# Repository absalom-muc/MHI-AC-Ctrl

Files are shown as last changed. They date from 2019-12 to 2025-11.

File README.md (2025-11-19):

# MHI-AC-Ctrl
Reads and writes data (e.g. power, mode, fan status etc.) from/to a Mitsubishi Heavy Industries (MHI) air conditioner (AC) via SPI controlled by MQTT. The AC is the SPI master and the ESP8266 is the SPI slave.

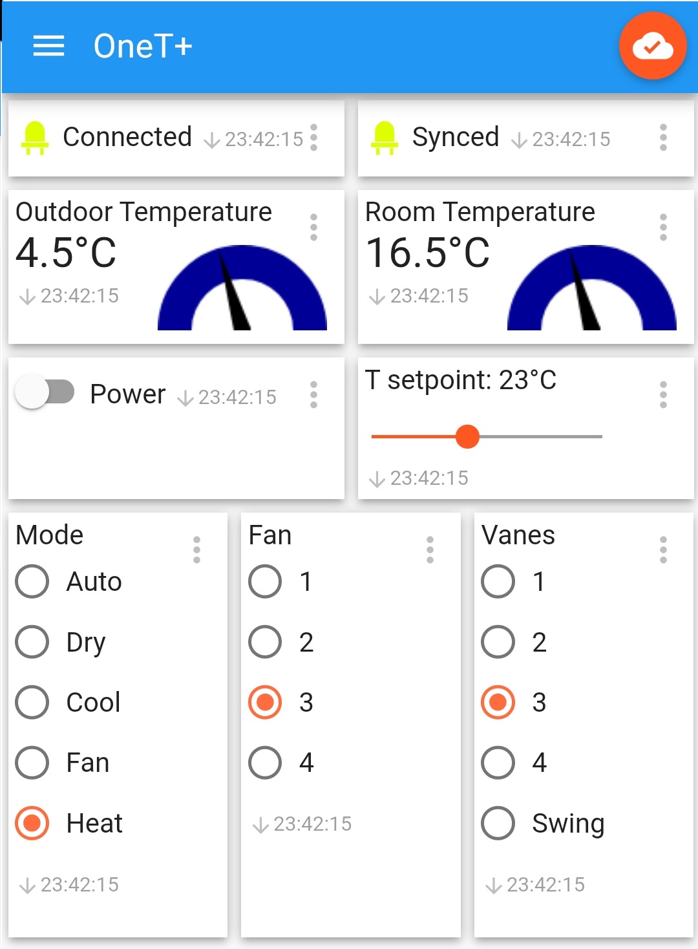
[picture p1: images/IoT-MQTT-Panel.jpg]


# Attention:
:warning: You have to open the indoor unit to have access to the SPI. Opening of the indoor unit should be done by 
a qualified professional because faulty handling may cause leakage of water, electric shock or fire! :warning: 

# Prerequisites:
For use of the program you have to connect your ESP8266 (I use a LOLIN(WEMOS) D1 R2 & mini with 80 MHz) via a
cable connector to your air conditioner. This has to be a split device (separated indoor and outdoor unit).
I assume that all AC units of the type "SRK xx ZS-S" / "SRC xx ZS-S" are supported. I use the indoor unit SRK 35 ZS-S and the outdoor unit SRC 35 ZS-S. Users reported that additionally the following models are supported:

- [SRF xx ZJX-S1](https://github.com/absalom-muc/MHI-AC-Ctrl/issues/17#issue-632187165)
- [SRF xx ZMX-S](https://github.com/absalom-muc/MHI-AC-Ctrl/issues/17#issuecomment-704789297)
- [SRF xx ZMXA-S](https://github.com/absalom-muc/MHI-AC-Ctrl/pull/91)
- SRF xx ZF-W
- [SRF xx ZS-W](https://github.com/absalom-muc/MHI-AC-Ctrl/pull/216#issue-3234769567) works with frame size 20
- [SRK xx ZJ-S](https://github.com/absalom-muc/MHI-AC-Ctrl/issues/10)
- [SRK xx ZM-S](https://github.com/absalom-muc/MHI-AC-Ctrl/issues/9)
- [SRK xx ZJX-S](https://github.com/absalom-muc/MHI-AC-Ctrl/issues/17#issuecomment-646469621)
- [SRK xx ZJX-S1](https://github.com/absalom-muc/MHI-AC-Ctrl/issues/17#issuecomment-646968940)
- [SRK xx ZR-WF](https://github.com/absalom-muc/MHI-AC-Ctrl/issues/214)
- [SRK xx ZRA-W](https://github.com/absalom-muc/MHI-AC-Ctrl/issues/17#issuecomment-730628655) / DXK xx ZRA-W
- [SRK xx ZSA-W](https://github.com/absalom-muc/MHI-AC-Ctrl/issues/17#issuecomment-891649495) / DXK xx ZSA-W
- [SRK63ZSPR-S](https://github.com/absalom-muc/MHI-AC-Ctrl/issues/149)
- SRK xx ZSXA-W/A
- [SRK xx ZSX-S](https://github.com/absalom-muc/MHI-AC-Ctrl/issues/6#issuecomment-582242372)
- [SRK xx ZSX-W](https://github.com/absalom-muc/MHI-AC-Ctrl/issues/17#issuecomment-643748095)
- [SRK xx ZS-W](https://github.com/absalom-muc/MHI-AC-Ctrl/issues/121)
- [SRK xx ZS-WF](https://github.com/absalom-muc/MHI-AC-Ctrl/issues/121#issuecomment-1938350129)
- [SRC 35Z SA-W]
- [DXK xx ZMA-S](https://github.com/absalom-muc/MHI-AC-Ctrl/issues/201)
- [SRK 2824 T (Japanese domestic model)](https://github.com/absalom-muc/MHI-AC-Ctrl/issues/211)

Unsupported models:
- [SRK71ZEA-S1](https://github.com/absalom-muc/MHI-AC-Ctrl/issues/143)
- [SRK35ZC-S](https://github.com/absalom-muc/MHI-AC-Ctrl/issues/154)
- [SRK xx ZSPR-S](https://github.com/absalom-muc/MHI-AC-Ctrl/issues/200) (except SRK63ZSPR-S)

If you find out that also other models are supported that are not listed here, please give feedback so that I can expand the list. In general, please recheck if your AC has a CNS connector before you spend time and money to build the hardware.

# Installing:

## Hardware:
The ESP8266 is powered from the AC via DC-DC (12V -> 5V) converter. 
The ESP8266 SPI signals SCL (SPI clock), MOSI (Master Out Slave In) and MISO (Master In Slave Out) are connected via a voltage level shifter 5V <-> 3.3V with the AC. Direct connection of the signals without a level shifter could damage your ESP8266!
More details are described in [Hardware.md](Hardware.md).

## Software:
The program uses the following libraries:
 - MQTT client library [PubSubClient3](https://github.com/hmueller01/pubsubclient3)
   - :warning: Don't use PubSubClient v2.8.0, it is broken due to issue [#747](https://github.com/knolleary/pubsubclient/issues/747) :warning:
 - [ArduinoOTA](https://github.com/esp8266/Arduino/tree/master/libraries/ArduinoOTA) (might be removed in future)
 
and optionally you need for the use of an external temperature sensor DS18x20 the libraries
 - [OneWire](https://www.pjrc.com/teensy/td_libs_OneWire.html)
 - [DallasTemperature](https://github.com/milesburton/Arduino-Temperature-Control-Library)

Please check the GitHub pages to see how to install them (usually via tools -> libraries).

Create a sub-directory "MHI-AC-Ctrl" and copy the files from the latest [release](https://github.com/absalom-muc/MHI-AC-Ctrl/releases) src directory in your MHI-AC-Ctrl sub-directory. You could also use the recently updated version in the [src folder](src) but with the risk that it is more unstable. The stability of the program is better when you compile it for a CPU frequency of 160MHz.
The configuration options are described in [SW-Configuration.md](SW-Configuration.md).

In a previous version (see [here](https://github.com/absalom-muc/MHI-AC-SPY)) I used the Hardware-SPI of the ESP8266. But since the SPI documentation of ESP8266 is poor, I decided to switch to a Software based SPI.
This Software based SPI is reliable and the performance of the ESP8266 is sufficient for this use case.
In case of problems please check the [Troubleshooting guide](Troubleshooting.md).

# Enhancement
If you are interested to have a deeper look on the SPI protocol or want to trace the SPI signals, please check [MHI-AC-Trace](https://github.com/absalom-muc/MHI-AC-Trace). But this is not needed for the standard user of MHI-AC-Ctrl.

# License
This project is licensed under the MIT License - see the LICENSE.md file for details

# Acknowledgments
The coding of the [SPI protocol](https://github.com/absalom-muc/MHI-AC-Trace/blob/main/SPI.md) of the AC is a nightmare. Without [rjdekker's MHI2MQTT](https://github.com/rjdekker/MHI2MQTT) I had no chance to understand the protocol! Unfortunately rjdekker is no longer active on GitHub. He used an Arduino plus an ESP8266 for his project.
Also thank you very much on the authors and contributors of [MQTT client](https://github.com/knolleary/pubsubclient), [ArduinoOTA](https://github.com/esp8266/Arduino/tree/master/libraries/ArduinoOTA), [OneWire](https://www.pjrc.com/teensy/td_libs_OneWire.html) and [DallasTemperature](https://github.com/milesburton/Arduino-Temperature-Control-Library) libraries.

Last but not least thank you for the implementation of MHI-AC-Ctrl in [different environments](https://github.com/absalom-muc/MHI-AC-Ctrl/blob/master/SW-Configuration.md#integration-examples) (FHEM, Tasmota, Home Assistant etc.)

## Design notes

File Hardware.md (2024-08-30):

# Hardware

## Schematic
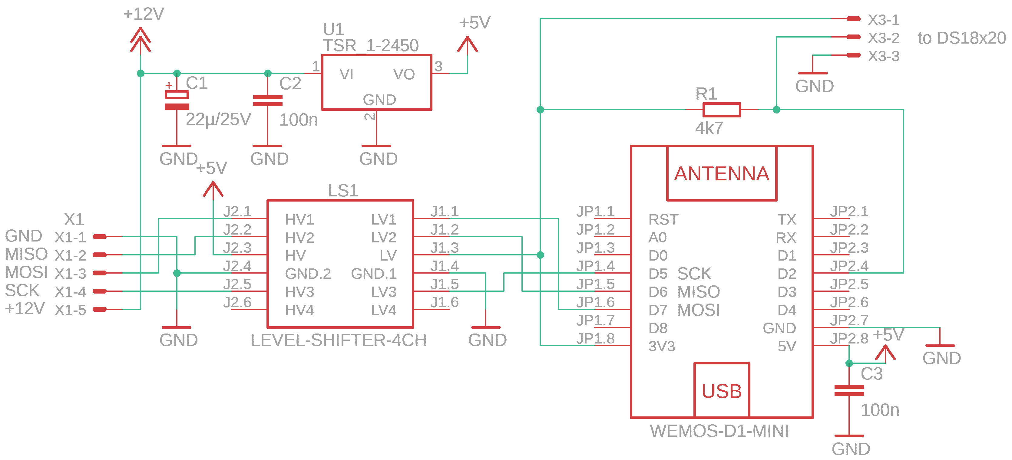
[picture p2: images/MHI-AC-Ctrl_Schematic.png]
schematic


## PCB (Eagle)
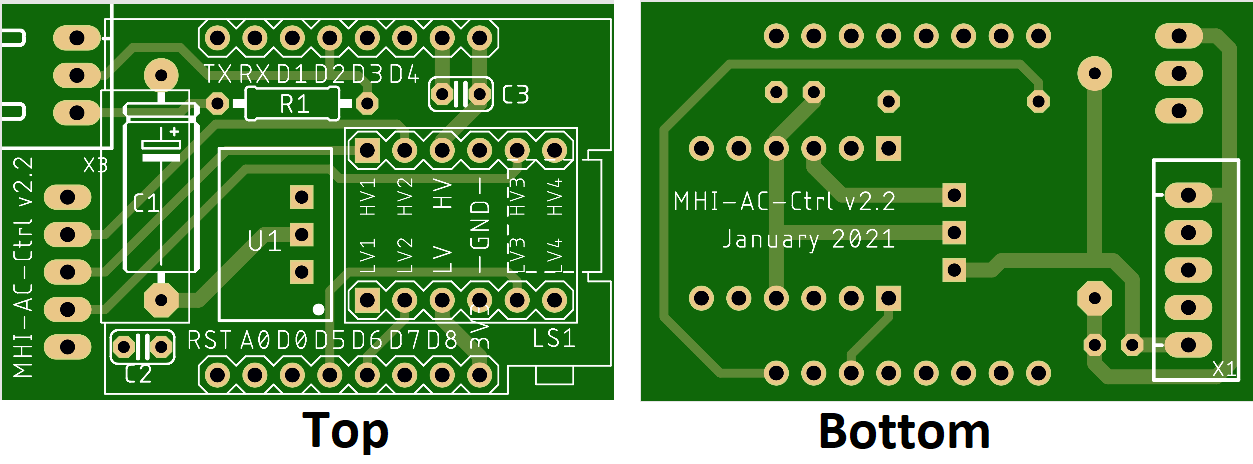
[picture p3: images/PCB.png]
PCB


You find the eagle schematic and the layout in the [eagle folder](eagle). The Gerber data is in [MHI-AC-Ctrl_v2.2_2021-01-22.zip](eagle/Gerber/MHI-AC-Ctrl_v2.2_2021-01-22.zip). I used this Gerber data for the PCB order at [JLCPCB](https://jlcpcb.com).

## Bill of Material
Part |Value            |Package                    |comment
---- | ----            |----                       |-----
C1   |22µ/25V          |E15-5                      |consider the polarity
C2, C3   |100n             |C025-024X044
LS1  |LEVEL-SHIFTER-4CH|LEVEL-SHIFTER-4CH          |consider the polarity
U$1  |WEMOS-D1-MINI    |WEMOS-D1-MINI              |consider the polarity
U1   |TSR_1-2450       |TSR-1                      |consider the polarity  <sup>1</sup>
X1   |JST 05JQ-BT      |JST-XH-05-PACKAGE-LONG-PAD                     |consider the polarity

<sup>1</sup>According to the discussions [here](https://github.com/absalom-muc/MHI-AC-Ctrl/issues/102) and [here](https://github.com/absalom-muc/MHI-AC-Ctrl/issues/17) TSR 1-2450 can be replaced by TSR 1-2450E.

The following parts are only needed when externally a DS18x20 should be connected:
Part |Value            |Package                    |comment
---- | ----            |----                       |-----
R1   |4k7              |R-EU_0207/10       
X3   |JST-XH-03        |JST-XH-03-PACKAGE-LONG-PAD |consider the polarity

## Assembled PCB
The following photos show the assembled PCB (without R1 and X1, which are used in context of DS18x20 only).
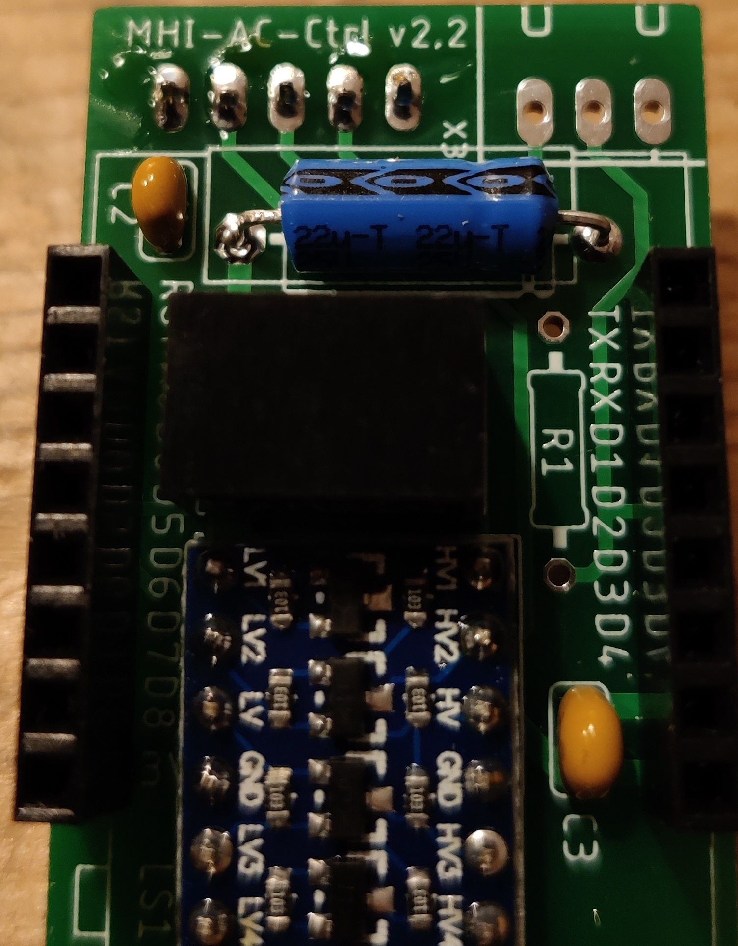
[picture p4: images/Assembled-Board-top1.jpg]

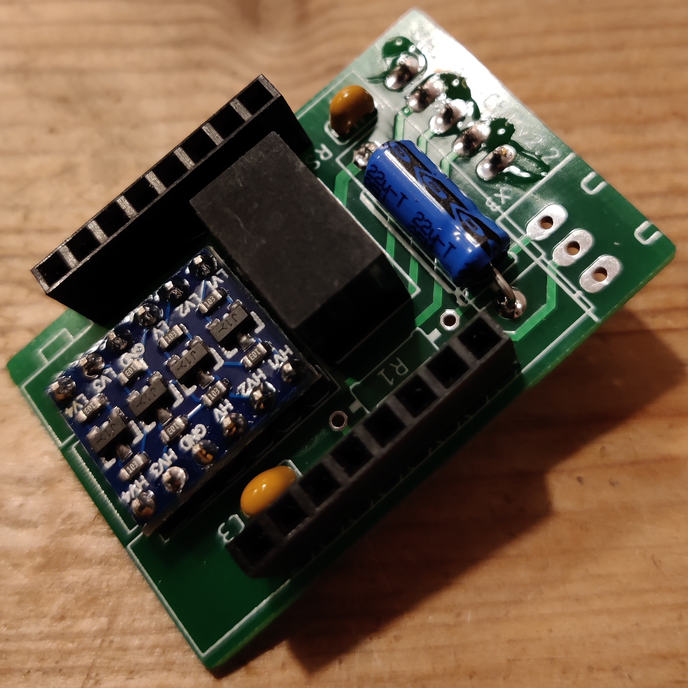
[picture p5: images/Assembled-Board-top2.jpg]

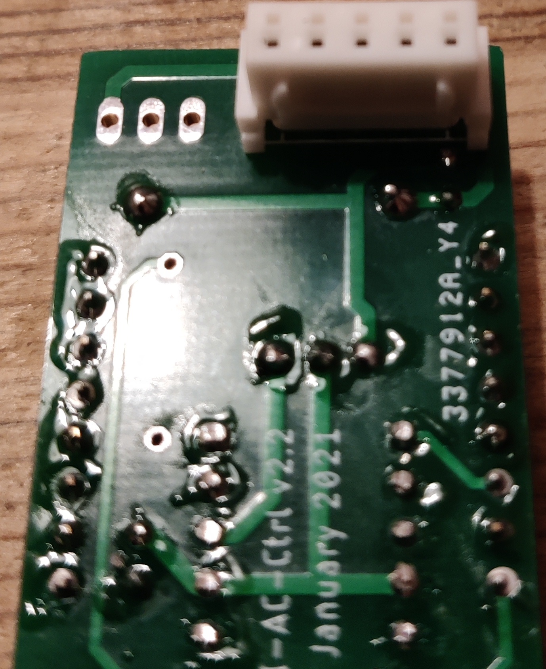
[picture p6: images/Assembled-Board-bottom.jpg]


# PCB (KiCad)
User [oliv3r](https://github.com/oliv3r) converted the eagle model to KiCad, see [here](https://gitlab.com/olliver/MHI-AC-Ctrl_PCB/-/tree/master/kicad). Continues development will also happens on that other repo.
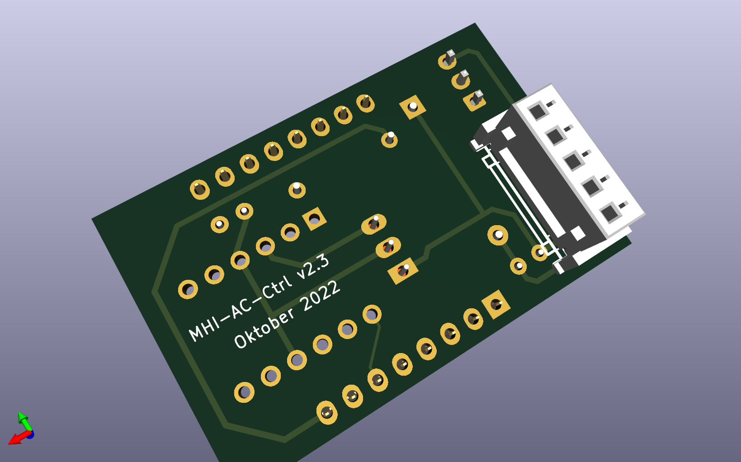
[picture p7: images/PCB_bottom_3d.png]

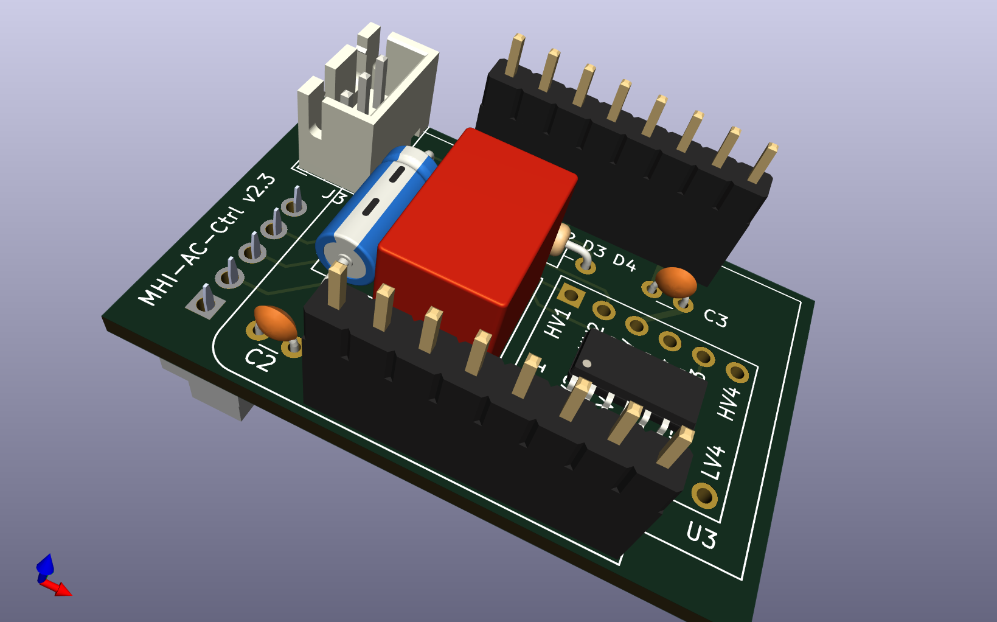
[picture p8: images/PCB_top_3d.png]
   
Please note that the KiCad design hasn't been tested so far (see also this [issue](https://github.com/absalom-muc/MHI-AC-Ctrl/issues/111)).

## Connector
The AC provides the signals via the CNS connector. It has 5 pins with a pitch of 2.5 mm. It is out of the [XH series from JST](http://www.jst-mfg.com/product/detail_e.php?series=277). The position of the connector is visible on the following photo of the AC indoor unit PCB.
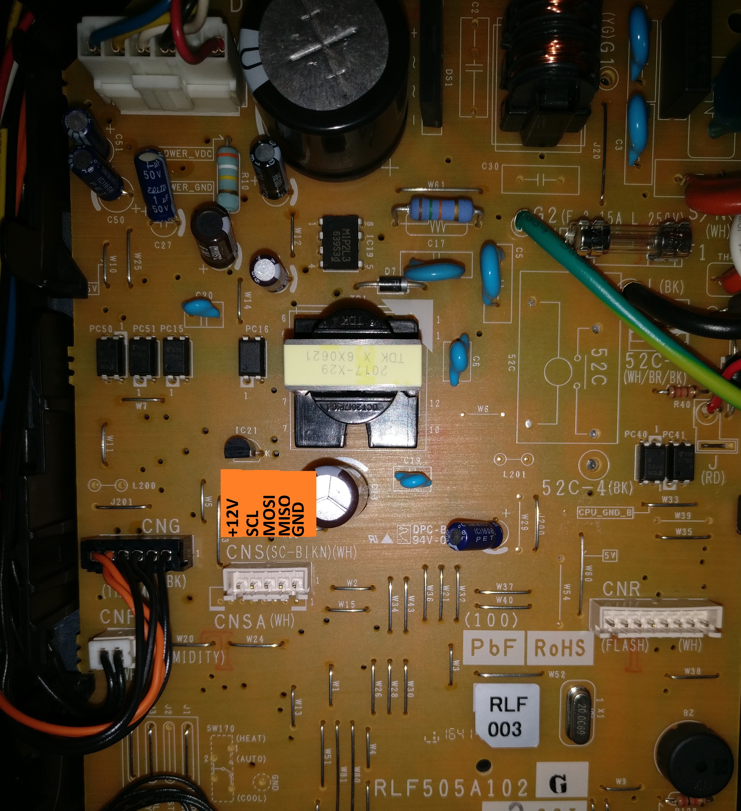
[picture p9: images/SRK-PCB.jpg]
Indoor PCB


The PCB of the remote control uses a pin connector out of [JST JQ series](https://jst.de/file/download/124/pitch-2-5-mm-btb-jq-pdf) also with a pitch of 2.5 mm. So the board can be directly plugged into the board of the AC.
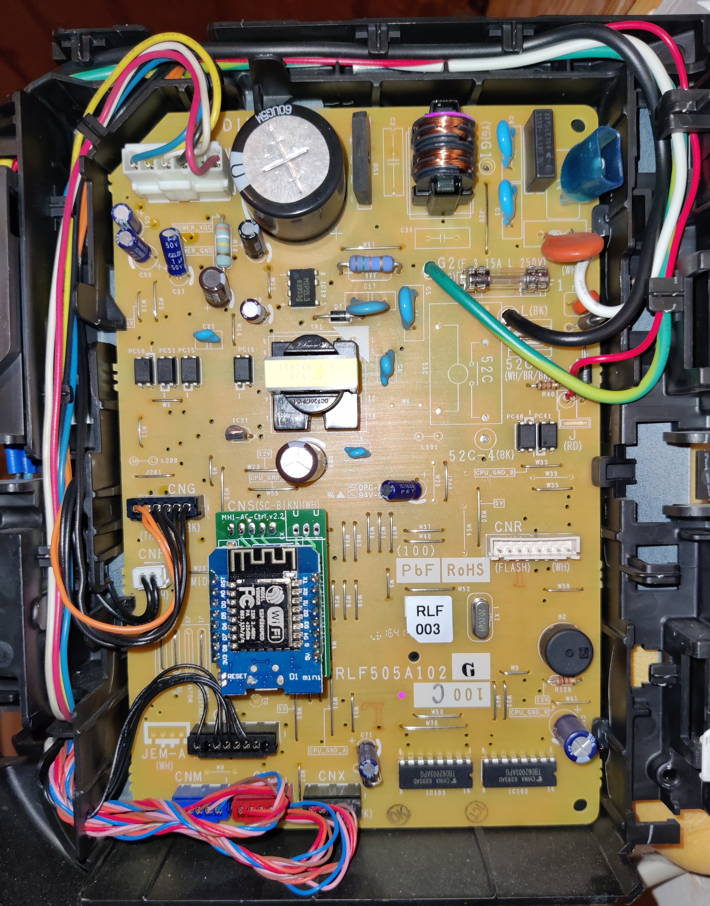
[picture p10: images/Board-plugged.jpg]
Board plugged


*hint: For previous MHI-AC-Ctrl PCB layouts a different connector was used. Additionally, it was required to swap pins because there was no 1:1 connection. This is no longer valid for the latest PCB layout. With the latest PCB layout you can directly plug the MHI-AC-Ctrl PCB to the AC PCB - **:warning: of course only when the AC is de-energized :warning:**.*

The possibility to directly plug the MHI-AC-Ctrl PCB to the AC PCB makes it simpler, but the operation of MHI-AC-Ctrl inside the AC case could reduce slightly the WiFi signal strength. If you see that the signal strength is not sufficient (e.g. many WiFi disconnects) then you should use a cable (called "4S balancer JST-XH extension cable" with one male and one female connector) and locate MHI-AC-Ctrl outside of the AC case. 

:warning: **Opening of the indoor unit should be done by a qualified professional because faulty handling may cause leakage of water, electric shock or fire!** :warning:

Before you assemble the PCB, please check this [issue](https://github.com/absalom-muc/MHI-AC-Ctrl/issues/56). For some ACs (e.g. SRK-ZSX serie) it's getting tight and there might be not enough space to plug-in the MHI-AC-Ctrl PCB to your AC board.

## Power Supply
The JST connector provides +12V. The DC-DC converter [TSR 1-2450](https://www.tracopower.com/products/browse-by-category/find/tsr-1/3/) converts the +12V to +5V.

## Signal Connection
The ESP8266 SPI signals SCL (SPI clock), MOSI (Master Out Slave In) and MISO (Master In Slave Out) are connected via a voltage level shifter 5V <-> 3.3V with the AC. Direct connection of the signals without a level shifter could damage your ESP8266!
In an early version I used a resistor voltage divider, but since the SPI of the AC has high impedance outputs, a voltage level shifter seems to be better. The voltage level shifters are bi-directional. That means the according ESP8266 pins (SCL, MOSI, MISO) could be inputs or outputs.

Please find [here](https://github.com/absalom-muc/MHI-AC-Ctrl/issues/65) the discussion if the level shifter can be omitted. 

## External Temperature Sensor
An external temperature sensor DS18x20 (e.g. DS18S20, DS18B20) is supported. If you want to connect a DS18x20 you assemble R1 (4k7) on the PCB. The signals for the DS18x20 are available at X2.

## Hints for Assembly
If you prefer to assemble X1 on the top of the PCB because e.g. you want to place the MHI-AC-Ctrl outside of the AC, you have to consider the direction of X1 as shown on the following photo.

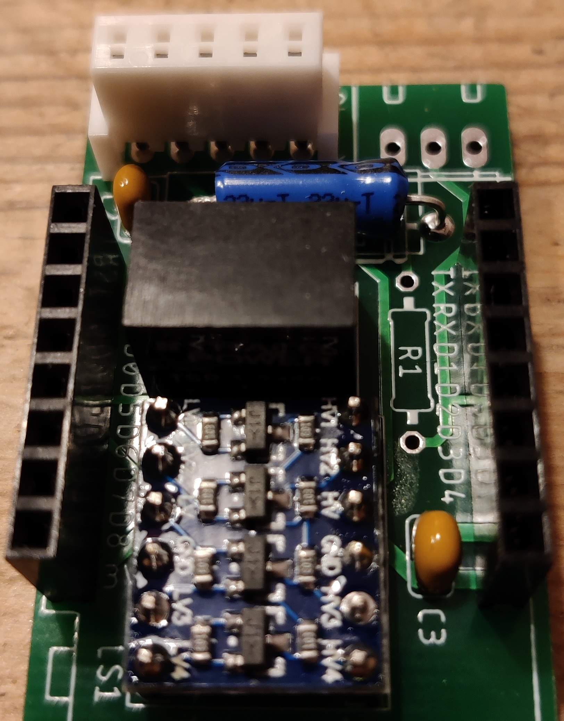
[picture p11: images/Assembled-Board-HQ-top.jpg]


## ESP32
There is also an ESP32 variant available created by user [hberntsen](https://github.com/hberntsen/mhi-ac-ctrl-esp32-c3). It is a rewite of the core files and using esphome. Issues with it should be posted there :-)

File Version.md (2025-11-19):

MHI-AC-Ctrl by absalom-muc

**Adaptions since version 2.8** (not released)
- [Move from unmaintained knolleary/pubsubclient to hmueller01/pubsubclient3](https://github.com/absalom-muc/MHI-AC-Ctrl/pull/212)

**v2.8** (September 2023)
- when ds18x20 used and get disconnected, fallback to  IU temperature sensor by [glsf91](https://github.com/glsf91)
- added status and control 3D auto and vanes L/R (extended frame size (33) used like WF-RAC module). You have to enable this! [3d auto and vanes l/r seems possible over CNS #77](https://github.com/absalom-muc/MHI-AC-Ctrl/issues/77) by [glsf91](https://github.com/glsf91) 
- added SRK35ZC-S to unsupported list [Addition to unsupported list #154](https://github.com/absalom-muc/MHI-AC-Ctrl/issues/154) by [glsf91](https://github.com/glsf91)

**v2.7R4** (April 2023)
- changed setup WiFi connection to async; module starts already communicating with AC during WiFi setup and also during scanning when WiFI_SEARCHStrongestAP is used by [glsf91](https://github.com/glsf91)
- added CONTINUE_WITHOUT_MQTT; module keeps communicating with AC if MQTT is disconnected. See also description in SW-Configuration.md and [Question: why mhi_ac_ctrl_core.loop only when MQTT connected? #144](https://github.com/absalom-muc/MHI-AC-Ctrl/issues/144) by [glsf91](https://github.com/glsf91)
- fix bug for publish list of access points by [glsf91](https://github.com/glsf91)
- added SRK71ZEA-S1 to unsupported list [Addition to unsupported list #143](https://github.com/absalom-muc/MHI-AC-Ctrl/issues/143) by [glsf91](https://github.com/glsf91)
- added Web page [Webpage for accessing MQTT data #141](https://github.com/absalom-muc/MHI-AC-Ctrl/issues/141) to integration list by [glsf91](https://github.com/glsf91)

**v2.7R3** (March 2023)
-  fix some compiler warnings by [glsf91](https://github.com/glsf91)
-  change sending MISO with faster refresh of data every 20s by [glsf91](https://github.com/glsf91)
-  avoid jitter with internal temperature sensor, now updating atmost every 5s by [glsf91](https://github.com/glsf91)
-  fix print wifi encryption type by [glsf91](https://github.com/glsf91)
-  skip not usable values for DB18B20 by [glsf91](https://github.com/glsf91)

**v2.7R2** (March 2023)
-  Added energy kWh from airco by [glsf91](https://github.com/glsf91).

**v2.7R1** (February 2023)
-  Fix for fan not showing 4 and Auto after powerdown AC [pull request #132](https://github.com/absalom-muc/MHI-AC-Ctrl/pull/132#) according to [issue #99](https://github.com/absalom-muc/MHI-AC-Ctrl/issues/99#issuecomment-1407615341) by [glsf91](https://github.com/glsf91).

**v2.6** (January 2023)
- Fix of [Wifi reconnect takes too long #125](https://github.com/absalom-muc/MHI-AC-Ctrl/issues/125)
- Typo related to the unit of TD fixed in MHI-AC-Ctrl-core.h and SW-Configuration.md

**v2.6R5** (December 2022, draft version)
- Added ROOM_TEMP_DS18X20_OFFSET for issue [Adding offset for external temperature sensor #119](https://github.com/absalom-muc/MHI-AC-Ctrl/issues/119)

**v2.6R4** (December 2022, draft version)
- Added Enhance resolution of Tsetpoint according to [pull request #123](https://github.com/absalom-muc/MHI-AC-Ctrl/pull/123) by [glsf91](https://github.com/glsf91).

**v2.6R3** (December 2022, draft version)
- Added switch for Troom filtering to address [issue #82](https://github.com/absalom-muc/MHI-AC-Ctrl/issues/82).

**v2.6R2** (August 2022, draft version)
- final implementation for fan control incl. 'Auto', see [issue](https://github.com/absalom-muc/MHI-AC-Ctrl/issues/99). This is a breaking change, because in the past only the values 1, 2 , 3, 4 were supported for fan status and fan control. Now "Auto" was added.
- added temporary operating data "unknwon" to find out which functions are supported by SPI dependent on the indoor AC unit.

**v2.6R1** (August 2022, draft version)
- new implementation for fan control incl. 'Auto', see [issue](https://github.com/absalom-muc/MHI-AC-Ctrl/issues/99)

**v2.5** (August 2022)
- release w/o changes

**v2.5R3** (June 2022, draft version)
- moved the functions for frequency measurement from MHI-AC-Ctrl.ino to support.cpp
- moved some MQTT init handling from MHI-AC-Ctrl.ino void setup() to MQTTloop()
- moved long previousMillis = millis to inside void loop() as static
- added parameter WiFI_SEARCH_FOR_STRONGER_AP_INTERVALL
- Reworked WiFi network re-scan function
- added work around for "not updating WiFi.status()", see https://github.com/esp8266/Arduino/issues/7432
- ICACHE_RAM_ATTR is deprecated, replaced by IRAM_ATTR
- removed switch ROOM_TEMP_MQTT in support.h, a Troom MQTT set command is always considered  

**v2.5R21** (December 2021, draft version)
- calculation of RETURN-AIR in MHI-AC-Ctrl.ino corrected
- Removed the option #define ROOM_TEMP_IU for adaption by the user in support.h. Now it is generated automatically when ROOM_TEMP_DS18X20 and ROOM_TEMP_MQTT are not defined
- Reworked WiFi network re-scan function
- increased resolution of Tsetpoint to 0.5°C

**v2.5R1** (November 2021, draft version)
- Version number now located in support.h, published once MQTT connection is available

**Versioning changed**

Released versions are availabe on the [release page](https://github.com/absalom-muc/MHI-AC-Ctrl/releases)
All other versions are draft. A new version ends with "R1", "R2"-postfix etc. before it is released w/o "R"-postfix, e.g. v2.5R1 => v2.5R2 => v2.5
For documentation updates usually no new version number is created.

**v2.3** (September 2021, draft version)
- for MHI_AC_Ctrl_Core::loop return value err_msg_timeout replaced by the more detailed return values err_msg_timeout_SCK_low and err_msg_timeout_SCK_high added
- output of the number of WiFi and MQTT lost since last reset
- output of the BSSID used for the WiFi connection
- use of the strongest WiFi access point (testing incomplete)
- option added to use the room temperature from DS18x20 sensor or from MQTT topic instead of AC IU sensor

**v2.2** (February 2021)
- PCB layout update to v2.2 allows to plug-in MHI-AC-Ctrl directly into the AC without using a cable

**v2.03** (July 2020)
- Functionality for POWERON_WHEN_CHANGING_MODE improved in MHI-AC-Ctrl.ino
- WiFi mode restricted to STA (no more AP) in support.cpp

**v2.02** (June 2020)
- Functionality for POWERON_WHEN_CHANGING_MODE enhanced, the according #define shifted to support.h

**v2.01** (June 2020)
- No functional changes
- Further reduction of memory usage
- Compiler warnings removed
- set-mechanism reworked
- SCK by SCK_PIN replaced according to [pull request 19](https://github.com/absalom-muc/MHI-AC-Ctrl/pull/19)
- Shift void MeasureFrequency() from support.cpp to MHI-AC-Ctrl-core.cpp

**v2.0** (June 2020)
- code refactored to allow simplified adaption for other frameworks (e.g. Tasmota, Home Assistant), main changes
	- MHI-AC-Ctrl-core separated according to [Issue #13](https://github.com/absalom-muc/MHI-AC-Ctrl/issues/13)
	- Changeable defs for all topics and payload according to this [Pull request](https://github.com/absalom-muc/MHI-AC-Ctrl/pull/15)
- Option added to switch on the AC when the mode is changed according to [Issue #14](https://github.com/absalom-muc/MHI-AC-Ctrl/issues/14)
- Added operating data THO-R1, THO-R2, THO-R3, THO-R1 and TD added
- Handling for operating data "PROTECTION-No" and "CT" corrected
- Output of the frame raw data is no longer supported
- MQTT.md replaced by [SW-Configuration.md](SW-Configuration.md)

**v1.4** (April 2020)
- Vanes MQTT status corrected
- Frequency measurement limits adapted, ESP is halted only when there is a toggle on MISO detected, results of the measurement will be published via MQTT
- some [operating data](https://github.com/absalom-muc/MHI-AC-Ctrl/blob/master/MQTT.md#mqtt-topics-related-to-operating-data) added (MQTT path changed)
- [error operating data](https://github.com/absalom-muc/MHI-AC-Ctrl/blob/master/MQTT.md#mqtt-topics-related-to-error-data) added
- reset via MQTT for ESP8266 added
- support of an external DS18x20

**v1.3** (March 2020)
- MHI-AC-Ctrl.h added
- Support of Mitsubishi's ZSK series by acceptance of additionally 0x6d as the first MOSI signature byte (SB0) according to [this issue](https://github.com/absalom-muc/MHI-AC-Ctrl/issues/6).
- MQTT authentication support added
- AC operating data are supported
- Outdoor temperature MQTT topic is shifted to operating data
- Frequency measurement of the signals to check correct connection of MHI-AC-Ctrl board to AC
- MQTT topic connection values changed from false/true to 0/1 to be aligned with the documentation

**v1.2** (January 2020)

- Mode setting corrected
- Vanes is now only published if DB0[7]=1 or DB1[7]=1, else last vanes change was via IR-RC (so not visible via SPI)
- Options for vanes MQTT values adapted, it is now 1,2,3,4,Swing (before it was 1..5)
- Data types of some variables adapted
- MQTT status will be published after broker was down
- Raw data publishing commented out to reduce the broker load (worst case 20/s)
- Remove leading space characters for MQTT room and outdoor temperature
- MQTT topic Runtime removed

**v1.1** (December 2019)

- Error code (DB4) added
 OTA is now also working when waiting for a MQTT connection

**v1.0** (December 2019)

- initial

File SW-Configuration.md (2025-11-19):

# Introduction
The following descriptions address:
1. Basic settings for your configuration
2. Advanced settings for other frameworks (e.g. Tasmota, Home Assistant, Homie)
3. Integration examples

# Basic settings
The basic settings will be adapted in three files:   
 - [support.h](src/support.h) for general settings related to WiFi, MQTT, OTA and the external temperature sensor DS18x20
 - [MHI-AC-Ctrl.h](src/MHI-AC-Ctrl.h) for input / output settings (i.e. topic / payload text)
 - [MHI-AC-Ctrl-core.h](src/MHI-AC-Ctrl-core.h) for settings related to the behaviour of MHI-AC-Ctrl (e.g. selection of operating data)

## WiFi ([support.h](src/support.h))
WiFi STA mode is supported.

### WiFi Settings (SSID, Password, hostname)
Adapt the SSID and the password. Changing the hostname is usually not required.
```
#define WIFI_SSID "your SSID"
#define WIFI_PASSWORD "your WiFi password"
#define HOSTNAME "MHI-AC-Ctrl"
```
 Changing the hostname is required when multiple ACs should be supported. E.g. replace "MHI-AC-Ctrl" by "Living-Room-MHI-AC-Ctrl"

Per default ESP8266 uses the first WiFi access point (AP) with matching SSID. This behaviour can be changed.
```
#define UseStrongestAP true             // when false then the first WiFi access point with matching SSID found is used.
                                        // when true then the strongest WiFi access point with matching SSID found is used, it doesn't work with hidden SSID
```
Configure the time interval for searching a stronger AP.
```
#define WiFI_SEARCH_FOR_STRONGER_AP_INTERVALL 12    // WiFi network re-scan interval in minutes with alternate to +5dB stronger signal if detected
```
 
## MQTT ([support.h](src/support.h))
The program uses the MQTT client library [PubSubClient3](https://github.com/hmueller01/pubsubclient3) from Holger Müller (hmueller01), originally written by Nick O'Leary (knolleary).
If you are not familiar with MQTT you find on the Internet endless numbers of descriptions and tutorials. My favorites are [here](https://www.hivemq.com/blog/how-to-get-started-with-mqtt/) and [here](https://www.heise.de/developer/artikel/Kommunikation-ueber-MQTT-3238975.html).
I recommend [MQTT Explorer](http://mqtt-explorer.com/) a great all-round MQTT client that provides a structured topic overview for the first steps.

### MQTT General Settings (broker, port, account data)
Adapt the server (broker) name and the port if needed:

```
#define MQTT_SERVER "MQTT broker name"  // broker name or IP address of the broker
#define MQTT_PORT 1883                  // port number used by the broker
```

If you want to use MQTT authentication enter user name and password:
```
#define MQTT_USER ""          // if authentication is not used, leave it empty
#define MQTT_PASSWORD ""      // if authentication is not used, leave it empty
```
note: TLS/SSL is not supported

The following sections show the configuration for the MQTT pathes.
### MQTT status
The topic level for status information from the AC consists of the MQTT_PREFIX and the function name separated by a slash, e.g. *MHI-AC-Ctrl/Power*.   
For writes the topic level consists of the MQTT_PREFIX, the prefix for set commands (MQTT_SET_PREFIX) and the function name, each separated by a slash, e.g. *MHI-AC-Ctrl/set/Power*.  
You can change MQTT_PREFIX and MQTT_SET_PREFIX, default is
```
#define MQTT_PREFIX HOSTNAME "/"           // basic prefix used for publishing AC data
#define MQTT_SET_PREFIX MQTT_PREFIX "set/" // prefix for subscribing set commands
```
Please pay attention to the case sensitivity.

The following status data is available (prefix is not listed)
They are only published when there is a change of the message. The retained flag is 'true'.
When writing data, the retain flag shall be 'false'!

topic|r/w|value|comment
-----|---|-----|------
Power|r/w|"On", "Off"|
Mode|r/w|"Auto", "Dry", "Cool", "Fan", "Heat" and "Off"|"Off" is only supported when option [POWERON_WHEN_CHANGING_MODE](#behaviour-when-changing-ac-mode-supporth) is selected
Tsetpoint|r/w|18 ... 30|Target room temperature (float) in °C, resolution is 0.5°C
Fan|r/w|1,2,3,4,"Auto"|Fan level
Vanes|r/w|1,2,3,4,"Swing","?"|Vanes up/down position <sup>1</sup>
Troom|r/w|0 ... 35|Room temperature (float) in °C, resolution is 0.25°C  <sup>2</sup>
Tds1820|r|-40 .. 85|Temperature (float) by the additional DS18x20 sensor in °C, resolution is 0.5°C  <sup>3</sup>
Errorcode|r|0 .. 255|error code (unsigned int)
ErrOpData|w||triggers the reading of last error operating data
VanesLR|r/w|1,2,3,4,5,6,7,"Swing"|Vanes left/right position <sup>4</sup>
3Dauto|r/w|"On", "Off"|3D auto only works for mode Auto, Cool and heat<sup>4</sup>

<sup>1</sup> When the last command was received via the infrared remote control then the Vanes status is unknown and the "?" is published.   
<sup>2</sup> Please compare with section [Room temperature](#room-temperature) for writing.   
<sup>3</sup> Only available when a DS18x20 is connected, please see the description in [Hardware.md](Hardware.md) and in section [External Temperature Sensor Settings](#external-temperature-sensor-settings-supporth).
<sup>4</sup> Only available if USE_EXTENDED_FRAME_SIZE is enabled in [support.h](src/support.h)

Additionally, the following program status topics are available:

topic    |r/w| value |comment
---------|---|---|---
cmd_received|r|"o.k.", "unknown command" or "invalid parameter"|feedback for last set command
connected|r  |0, 1|MQTT connection status to broker
fMISO    |r  |unsigned integer|frequency of the MISO pin in Hz during boot
fMOSI    |r  |unsigned integer|frequency of the MOSI pin in Hz during boot
fSCK     |r  |unsigned integer|frequency of the SCK pin in Hz during boot
reset|w|"reset"|resets the ESP8266
RSSI     |r  |integer         |WiFI RSSI / signal Strength in dBm after MQTT (re-)connect
Version  |r  |string          |Version number of MHI-AC-Ctrl
WIFI_LOST|r  |integer         |number of lost WiFi connections since last reset
MQTT_LOST|r  |integer         |number of lost MQTT connections since last reset
APs      |r  |string          |Matched APs seen at scan with RSSI value

note: The topic and the payload text of the status data is adaptable by defines in [MHI-AC-Ctrl.h](src/MHI-AC-Ctrl.h)

### MQTT operating data
MHI-AC-Ctrl can provide operating data of the indoor and outdoor unit. This data is not needed for daily use, but might be interesting in specific use cases. Operating data is only published when there is a change of the content. The retained flag is 'true'.
The path to the operating data topic can be adapted.

```
#define MQTT_OP_PREFIX "OpData/"    // prefix for publishing operating data
```

Without changes of the path, subscribe to *MHI-AC-Ctrl/OpData/#* for receiving all operating data. Please see section [Operating data](#operating-data-mhi-ac-ctrl-coreh) to find all supported operating data.

note: The topic and the payload text is adaptable by defines in [MHI-AC-Ctrl.h](src/MHI-AC-Ctrl.h)

### MQTT last error operating data
When an error in the AC occurs, some operating data of this error are stored in the AC and can be read out.
The path to the operating data topic is defined in   
```
#define MQTT_OP_PREFIX "ErrOpData/"    // prefix for publishing operating data from last error
```
The readout of last error operating data is triggered by publishing *ErrOpData* to topic ErrOpData. Not all of the operating data from section [Operating data](#operating-data-mhi-ac-ctrl-coreh) might be available as last error operating data.

note: The topic and the payload text is adaptable by defines in [MHI-AC-Ctrl.h](src/MHI-AC-Ctrl.h)

### MQTT operating data PROTECTION-NO topic
This is the Protection state number of the compressor (Compressor protection status).
The meaning of this numeric value is:

Value |meaning
------|-----
0  |Normal
1  |Discharge pipe temperature protection control
2  |Discharge pipe temperature anomaly
3  |Current safe control of inverter primary current
4  |High pressure protection control
5  |High pressure anomaly
6  |Low pressure protection control
7  |Low pressure anomaly
8  |Anti-frost prevention control
9  |Current cut
10 |Power transistor protection control
11 |Power transistor anomaly (Overheat)
12 |Compression ratio control
13 |-
14 |Condensation prevention control
15 |Current safe control of inverter secondary current
16 |Stop by compressor rotor lock
17 |Stop by compressor startup failure

## OTA Settings ([support.h](src/support.h))
OTA (Over the Air) update is the process of loading the firmware to ESP module using Wi-Fi connection rather than a serial port.
The OTA hostname can be adapted, per default it is the hostname used by WiFi.
```
#define OTA_HOSTNAME HOSTNAME     // default for the OTA_HOSTNAME is the HOSTNAME
#define OTA_PASSWORD ""           // Enter an OTA password if required
```
## External Temperature Sensor Settings ([support.h](src/support.h))
When an external temperature sensor is connected, you can configure the pin where DQ of the the DS18x20 is connected, default is Pin 4 (D2)
and how often the sensor should be read. To use reading of the external sensor you must adapt the TEMP_MEASURE_PERIOD.

```
#define TEMP_MEASURE_PERIOD 0   // period in seconds for temperature measurement with the external DS18x20 temperature sensor
                                // set to e.g. 30 to read the sensor every 30 seconds. 
#define ONE_WIRE_BUS 4          // D2, PIN for connecting temperature sensor DS18x20 DQ pin
#define ROOM_TEMP_DS18X20_OFFSET 0.0   // Temperature offset for DS18x20 sensor, can be positive or negative (examples: 0.0, -1.0, 1.5)

```
note: The according libraries [OneWire](https://www.pjrc.com/teensy/td_libs_OneWire.html) and [DallasTemperature](https://github.com/milesburton/Arduino-Temperature-Control-Library) are only used if TEMP_MEASURE_PERIOD > 0.

If the DS18x20 should replace the room temperature sensor of the AC, you have to configure it as described in the next clause.

## Room temperature
Usage of the room temperature sensor inside the AC is the default, but instead you can use the DS18x20 sensor on the MHI-AC-Ctrl board or the received temperature via the MQTT topic Troom. Setting Troom via MQTT works per default. But you should adapt ROOM_TEMP_MQTT_TIMEOUT. For using DS18x20 as Troom you have to use ROOM_TEMP_DS18X20.
```
//#define ROOM_TEMP_DS18X20           // use room temperature from DS18x20

#define ROOM_TEMP_MQTT_TIMEOUT  40    // time in seconds, after this time w/o receiving a valid room temperature
                                      // via MQTT fallback to IU temperature sensor value
#define TROOM_FILTER_LIMIT 0.25       // Defines from which Troom delta value a new Troom value is published. Resolution 0.25°C.
                                      // With a smaller resolution, Troom could toggle more. To deactivate the filter use 0.

```
ROOM_TEMP_MQTT_TIMEOUT must be greater than the period of room temperature update via MQTT. E.g. when the room temperature update via MQTT is done every minute, then ROOM_TEMP_MQTT_TIMEOUT could be 2 minutes.
If the timeout occurs, and the system falls back to IU temperature, it will return to using the MQTT room temperature if the MQTT messages resume.

## Enhance resolution of Tsetpoint ([support.h](src/support.h))
The AC is only accepting a setpoint in x.0 degrees. If you send x.5 degrees, the AC will convert this to (x+1).0 degrees. So using .5 degrees as a setpoint will increase the setpoint on the AC not with .5 degrees but with 1 degree. This behaviour can be changed with: 
```
#define ENHANCED_RESOLUTION true                    // when using Tsetpoint with x.5 degrees, airco will use (x+1).0 setpoint
                                                    // uncomment this to compensate (offset) Troom for this.
                                                    // this will simulate .x degrees resolution
```
If you now send x.5 degrees as setpoint, still the setpoint on the AC will be (x+1). But when sending the received Troom (from MQTT or the external temperature sensor) to the AC, Troom with an offset of .5 degrees will be send to the AC. This way the AC will increase the temperature in the room with .5 degrees instead of 1 degree.

**This behaviour won't work if you are using the internal temperature sensor of the AC !**

The MQTT topic Troom will show (like before) the Troom received by the AC (including the offset).

For example: when setpoint is 20.5. When Troom 19.5 is received (from MQTT or DS18x20), Troom sent to the AC will be 20.0. Topic Troom will also show 20.0.

## Behaviour when changing AC mode ([support.h](src/support.h))
Per default the power on/off state is not changed, when you change the AC mode (e.g. heat, dry, cold etc.).
But when you uncomment the following line, then the AC is switched on, once you change the AC mode and switched off if you publish "Off" to Mode (instead of Power). This beahviour is requested for use with [Home Assistant](https://www.home-assistant.io/).
```
//#define POWERON_WHEN_CHANGING_MODE true           // uncomment it to switch on the AC when the mode (heat, cool, dry etc.) is changed
```

## Using extended frame size for enabling 3D auto and vanes L/R ([support.h](src/support.h))
Per default the 3D auto and vanes left/right is not supported. 
But when you uncomment the following line, the frame size is extended to 33 bytes (like the WF-RAC module). This will make it possible to use 3D auto and vanes L/R.
```
//#define USE_EXTENDED_FRAME_SIZE true                // uncomment if you want to use de extended frame size (33) which is used by the WF-RAC module
                                                    // Then it will be possible to get and set the 3D auto and vanes left/right
```

# Advanced settings

## Topic and payload text ([MHI-AC-Ctrl.h](src/MHI-AC-Ctrl.h))
All topic and payload text is included in defines, e.g. change
```
#define PAYLOAD_POWER_ON "On"
```
to
```
#define PAYLOAD_POWER_ON "on"
```
if your framework prefers lower case. These topics and payloads are used for MQTT topics and payloads.

## Operating data ([MHI-AC-Ctrl-core.h](src/MHI-AC-Ctrl-core.h))
Currently the following operating data in double quotes are supported
```
  { 0xc0, 0x02},  //  1 "MODE"
  { 0xc0, 0x05},  //  2 "SET-TEMP" [°C]
  { 0xc0, 0x80},  //  3 "RETURN-AIR" [°C]
  { 0xc0, 0x81},  //  5 "THI-R1" [°C]
  { 0x40, 0x81},  //  6 "THI-R2" [°C]
  { 0xc0, 0x87},  //  7 "THI-R3" [°C]
  { 0xc0, 0x1f},  //  8 "IU-FANSPEED"
  { 0xc0, 0x1e},  // 12 "TOTAL-IU-RUN" [h]
  { 0x40, 0x80},  // 21 "OUTDOOR" [°C]
  { 0x40, 0x82},  // 22 "THO-R1" [°C]
  { 0x40, 0x11},  // 24 "COMP" [Hz]
  { 0x40, 0x85},  // 27 "TD" [°C]
  { 0x40, 0x90},  // 29 "CT" [A]
  { 0x40, 0xb1},  // 32 "TDSH" [°C]
  { 0x40, 0x7c},  // 33 "PROTECTION-No"
  { 0x40, 0x1f},  // 34 "OU-FANSPEED"
  { 0x40, 0x0c},  // 36 "DEFROST"
  { 0x40, 0x1e},  // 37 "TOTAL-COMP-RUN" [h]
  { 0x40, 0x13},  // 38 "OU-EEV" [Puls]
  { 0xc0, 0x94},  //    "energy-used" [kWh]
```

note1: If you are not interested in these operating modes (e.g. to reduce the MQTT load) you can comment out the according lines. But at least 1 line has to stay.
For THI-R2, THO-R1 and TDSH the formula for calculation is not yet known.
You can find some hints related to the meaning of the operating data [here](https://www.hrponline.co.uk/media/pdf/41/42/ed/Beijer-Ref-Service-Support-Handbook-19cWKESQUhzVIy5.pdf#page=7). Addtional opdata information is available [here](https://github.com/absalom-muc/MHI-AC-Trace/blob/main/SPI.md#operation-data-details).  

note2: The energy-used is the energy in kWh counting from power on the AC. If you power off the AC, the value (in kWh) will keep the last value. When you power on the AC again, it will start from 0 again.

hint: The error operating data is usually a sub-set of the operating data above. If user requests error operating data, all available error operating data is provided independent from the list above.

## Access Speed ([MHI-AC-Ctrl-core.h](src/MHI-AC-Ctrl-core.h ))
Default the above operating data is requested within 400 frames. Because 20 frames takes 1 second, the update interval for all operating data will be  400/20 = 20 seconds. If you disable some operating data (above), the update interval will stay 20 seconds.
With the following parameter you can change this interval of 20 seconds.
```
#define NoFramesPerOpDataCycle 400             // number of frames used for a OpData request cycle; will be 20s (20 frames are 1s)
```
Some operating data (32 -38) will take some time at the AC for processing. So don't decrease this value too much.

Changes to Power, Mode, Tsetpoint, Fan and Vanes wll be written to the AC right away. Above parameter will not influence this.

## Jitter internal temperature sensor ([MHI-AC-Ctrl-core.h](src/MHI-AC-Ctrl-core.h ))
If the AC internal temperature sensor is used, the received Troom can changes (+/- 0.25 degrees) sometimes several times in a second. This will give a burst of MQTT Troom messages.
To avoid this behaviour, the changed received Troom will only be published after at least 5 seconds. This is ONLY the case when the AC internal temperature sensor is used.
With the following parameter you can change this minimum interval of 5 seconds.
```
#define minTimeInternalTroom 5000              // minimal time in ms used for Troom internal sensor changes for publishing to avoid jitter 
```

This jitter can also be avoided by using the TROOM_FILTER_LIMIT as descibed above. But this filter is also used if the temperature is provided by an external temperature sensor or a connected DS18B20. With above it will be also possible to see smaller changes.

## Not switching off AC when MQTT connections fails ([MHI-AC-Ctrl.h](src/MHI-AC-Ctrl.h))
Default the module stops communicating with the AC when the MQTT connection get disconnected. After 120 sec the AC will power off because of [this](https://github.com/absalom-muc/MHI-AC-Ctrl/blob/master/Troubleshooting.md#fire-ac-switches-power-off-sometimes).
When using a DS18x20 as room temperature sensor, this can be unwanted behaviour. Also at night or when not at home when this happens, can be unwanted behaviour. 
This behaviour can be changed by changing the following line:
```
//#define CONTINUE_WITHOUT_MQTT true
```
to
```
#define CONTINUE_WITHOUT_MQTT true
```

Warning: be aware that there might be some safety implication and that the deactivation of this feature is on your own risk.
The AC now keeps running and no control is possible anymore when MQTT is disconnected. Also of course no MQTT topics are updated anymore. Of course control is still possible with the remote control.

## MHI-AC-Ctrl partitioning
MHI-AC-Ctrl-core implements the core functions (SPI read/write, communication with the wrapper).
Wifi, MQTT, OTA and DS18x20 stuff is located in support.h and support.cpp.
MHI-AC-Ctrl.ino and MHI-AC-Ctrl.h contain the wrapper for MHI-AC-Ctrl-core.cpp and support.cpp.

### MHI-AC-Ctrl-core.h and MHI-AC-Ctrl-core.cpp
Usually it should be not touched, only configured via [MHI-AC-Ctrl-core.h](src/MHI-AC-Ctrl-core.h).
AC status information change will trigger the callback function cbiStatusFunction located in [MHI-AC-Ctrl.ino](src/MHI-AC-Ctrl.ino)
It is controlled via the functions:
```
void init();                          // initialization called once after boot
void reset_old_values();              // resets the 'old' variables ensuring that all status information are resend
int loop(uint max_time_ms);           // receive / transmit a frame of 20 bytes
void set_power(boolean power);        // power on/off the AC
void set_mode(ACMode mode);           // change AC mode (e.g. heat, dry, cool etc.)
void set_tsetpoint(uint tsetpoint);   // set the target temperature of the AC)
void set_fan(uint fan);               // set the requested fan speed
void set_vanes(uint vanes);           // set the vanes horizontal position (or swing)
void set_troom(byte temperature);     // set the room temperature used by AC
void request_ErrOpData();             // request that the AC provides the error data
```
The following sections describe the usage of these functions.

#### void init()
Configures the input /output state of the SPI pins. Resets old values.

### reset_old_values()
This should be called if you want to ensure that the receiver of the status data has the latest data. E.g. in case of a MQTT broker disconnect it should be called.

### int loop(uint max_time_ms)
For receiving / transmitting a frame of 20 bytes.
The input parameter is the maximum time which should be consumed by the loop function. Use a value > T<sub>Frame</sub> + T<sub>FramePause</sub> to ensure there is sufficient time to receive a frame.

This is a blocking function which takes - dependent on the AC model - about 10 ... 50ms. Inside the loop function no delay() or yield() call is used.
The following return values are supported:

return value|meaning
------------|-------------
err_msg_valid_frame     |a valid frame was received in the given time
err_msg_invalid_signature | a frame with invalid signature bytes was received
err_msg_invalid_checksum | a frame with an invalid checksum was received
err_msg_timeout_SCK_low | the specified time max_time_ms has been exceeded because SCK is const low and not toggling
err_msg_timeout_SCK_high | the specified time max_time_ms has been exceeded because SCK is const high and not toggling

note: The input parameters and return values could be changed in future.

### set_*()
Controls the AC.

### request_ErrOpData()
The error operating data will be read upon a request via this function.

### support
Provides the interface between MHI-AC-Ctrl and the user interfaces. 
It contains helper functions for serving WiFi, MQTT, OTA and the external temperature sensor DS18x20. 

### MHI-AC-Ctrl.h and MHI-AC-Ctrl.ino
This is the wrapper for MHI-AC-Ctrl-core and support.
It provides beside the standard setup() and loop() functions the following two functions.

#### void cbiStatusFunction(ACStatus status, int value)
This is a member of the class StatusHandler : public CallbackInterface_Status. It is a callback function called by MHI-AC-Ctrl-core in case of AC status changes. 

#### void MQTT_subscribe_callback(char* topic, byte* payload, unsigned int length)
This function is called for incoming MQTT messages, the message is analyzed and translated to function calls.
From systematic point of view this function should actually be located in [support.h](src/support.h) but in order to keep it simple it resides in [MHI-AC-Ctrl.ino](src/MHI-AC-Ctrl.ino). 

# Integration examples
You find here some examples for integration of MHI-AC-Ctrl
- [Node-Red / Google Assistant](https://github.com/absalom-muc/MHI-AC-Ctrl/issues/60)
- [openHAB](https://community.openhab.org/t/control-mhi-aircon-by-mqtt/104972)
- [IoT MQTT Panel](https://github.com/absalom-muc/MHI-AC-Ctrl/issues/59)
- [Home Assistant](https://github.com/absalom-muc/MHI-AC-Ctrl/issues/23)
- [Home Assistant with ESPHome](https://github.com/ginkage/MHI-AC-Ctrl-ESPHome)
- [Tasmota](https://github.com/absalom-muc/MHI-AC-Ctrl/issues/13#issuecomment-630425714)
- [ioBroker](https://forum.iobroker.net/topic/17041/anfrage-airconwithme-intesishome-klimasteuerung-adapter/14)
- [FHEM](https://forum.fhem.de/index.php/topic,88841.0/all.html)
- [WiFi SSID, hostname and MQTT server dynamic](https://github.com/absalom-muc/MHI-AC-Ctrl/pull/69)
- [Web page with MQTT](https://github.com/absalom-muc/MHI-AC-Ctrl/issues/141)
- [Display with AC controller](https://github.com/absalom-muc/MHI-AC-Ctrl/issues/173)

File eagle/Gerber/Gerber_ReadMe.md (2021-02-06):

The [Gerber files](MHI-AC-Ctrl_v2.1_2021-01-10.zip) in this folder were generated with Eagle v9.6.2. 
The predefined [CAM file](./cam/jlcpcb_2_layer_v9.cam) was downloaded from [JLCPCB](https://support.jlcpcb.com/article/137-how-to-generate-gerber-and-drill-files-in-autodesk-eagle) and generated according to the description there. 
The price for 5 PCBs with a delivery time of 10 days was approx. 10€ incl. shipment from China to Germany.

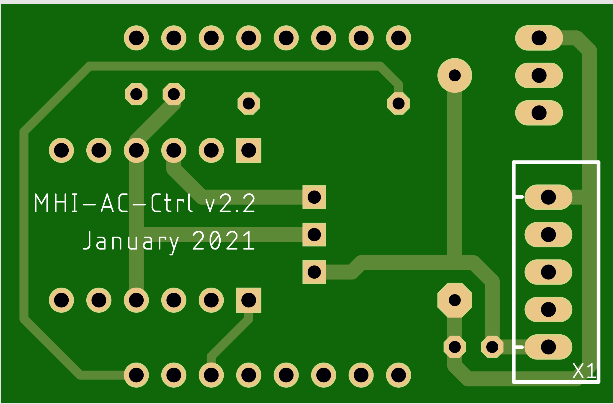
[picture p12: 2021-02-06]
images/PCB_bottom.PNG

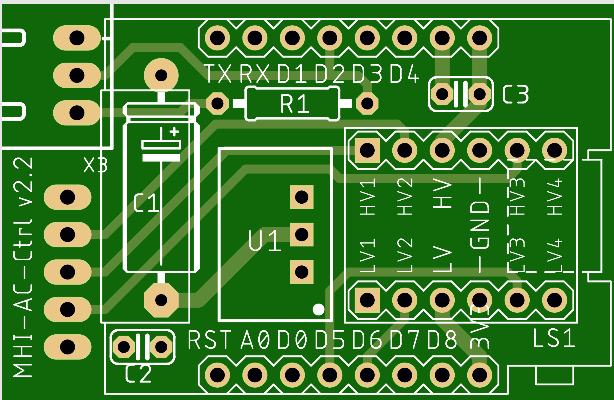
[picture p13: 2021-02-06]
images/PCB_top.PNG

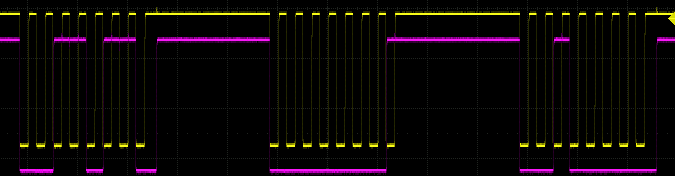
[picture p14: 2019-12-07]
images/ScreenImg-11-cut.png

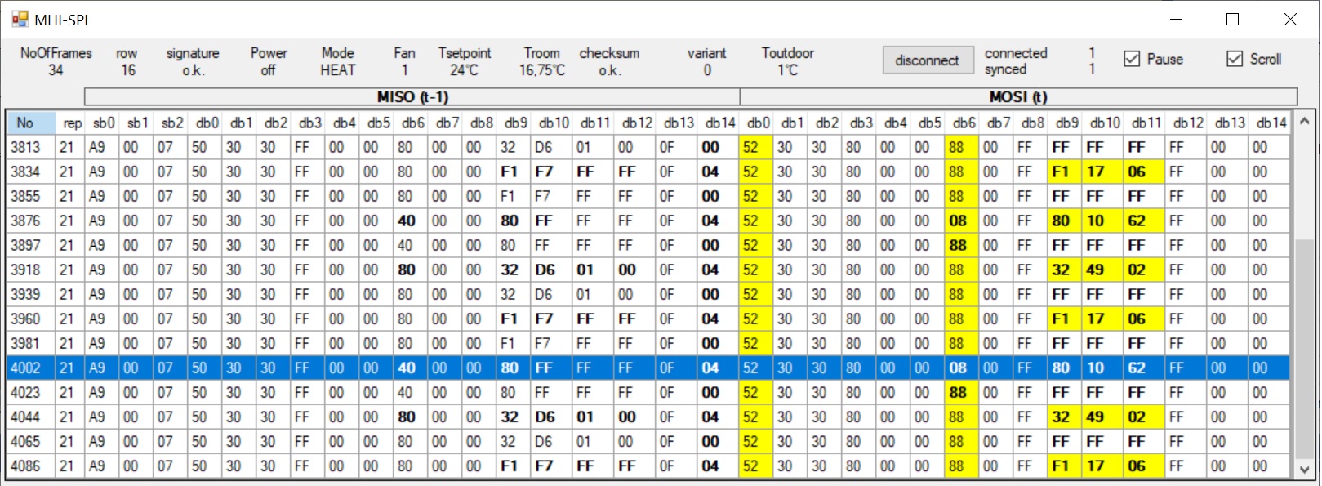
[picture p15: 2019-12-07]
images/MISO-MOSI_1.JPG

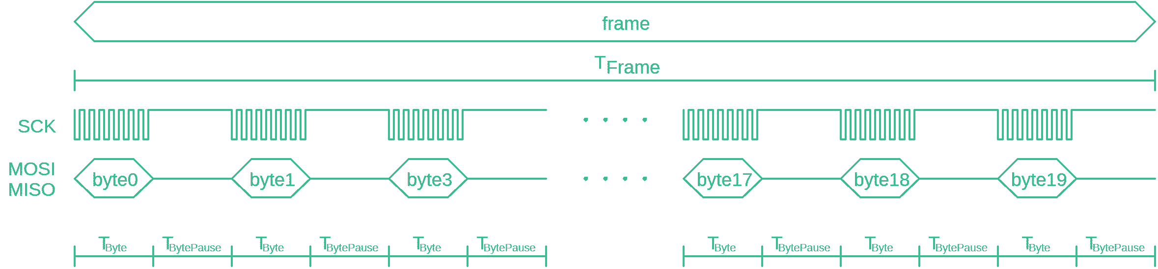
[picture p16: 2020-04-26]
images/timing_frame-byte.png

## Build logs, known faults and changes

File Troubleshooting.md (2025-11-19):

# Troubleshooting
You find here problems and solutions collected by users. I spend some time to write this documentation. Please take your time to read it before you open a new issue.

If you can't find the solution for your problem here and not in the existing  [Issues](https://github.com/absalom-muc/MHI-AC-Ctrl/issues?q=is%3Aissue) you can open a new issue. But please consider the following topics:
- You should have a basic understanding how to use an ESP8266. That includes the usage of an IDE for programming, compile, flash, OTA and log output via the serial terminal.
- You should have a basic understanding of the MQTT protocol and how to setup a MQTT broker

There are great descriptions in the WWW related to the topics above. Please use your preferred search engine.

If you open a new issue, please consider the following topics:
- Use a use a meaningful title, so that the next user with a similar problem can recognize it
- Which program version do you use?
- Add the exact name of your AC indoor unit, e.g. SRK 35 ZS-S 
- MHI-AC-Ctrl outputs some basic status information via the serial terminal. Please use it for your first analysis and upload it together with a new Issue. Check this [section](#recording-a-basic-log-file)

## Recording a basic log file
You can use e.g. the Arduino IDE to record the serial output. Apply a baud rate of 115000 Baud and switch **on** the time stamp. In order not to overload the Issue, the log should not be copied directly into the Issue, but copied to a text file and attached to the Issue.

## Recording a detailed log of the SPI waveforms
This is done via the [SPI-logger](https://github.com/absalom-muc/MHI-AC-Ctrl/blob/master/testprog/SPI_logger.ino). You can use e.g. the Arduino IDE to record the serial output. Apply a baud rate of 115000 Baud and switch **off** the time stamp. In order not to overload the Issue, the log should not be copied directly into the Issue, but copied to a text file and attached to the Issue.

## Known limitations
MHI-AC-Ctrl doesn't support all functions of the infrared remote control. This is because some functions are not reflected by the SPI payload (or I'm not aware of the according SPI codes):
- Vanes up/down is supported, but with the limitation that if the last command was issued by the IR RC, then the vanes up/down status is not visible in MHI-AC-Ctrl
- ECO, Silent and Night set back mode

This should be considered especially when you use the IR RC in parallel to MHI-AC-Ctrl.

Connecting the MHI-AC-Ctrl controller will **disable** the RC timer functionality. This also apply to the standard MHI WiFi (or other) controller. See [here](https://github.com/absalom-muc/MHI-AC-Ctrl/issues/148) for more information.

## :fire: ESP8266 crashes periodically
For a periodic crash there are different causes possible:

### :fire: Pins not properly connected
During boot the frequency of the SPI pins are checked. This is very helpful to identify SPI signal connection problems. Following values are expected:
- SCK frequency > 3000 Hz
- MOSI frequency < SCK frequency (usually ~ 500 Hz)
- MISO frequency ~ 0 Hz (usually 0Hz)

If you see other values, please re-check
- the connection between the MHI-AC-Ctrl board and your AC
- that there is no short between the three signals

If MISO frequency>10Hz the program will stop and reboot. This prevents damage of your board or AC because there was a signal detected on the MISO pin which should be an output during normal operation.

 Typical faults seen in the past:
- SCK frequency = 0Hz => SCK pin not connected
- SCK frequency < MOSI frequency => SCK and MOSI pins swapped
- MISO frequency = SCK frequency => MISO and SCK pins shorted

For reference: With a multimeter I measure for SCK and MOSI approx. 4.7V on the HV pins of the level shifter (and X1) and approx. 3V on the LV pins of the level shifter (and D5/D7)

### :fire: You use PubSubClient v2.8.0
There was a [bug](https://github.com/knolleary/pubsubclient/issues/747) introduced in PubSubClient version 2.8.0. Please use [PubSubClient3](https://github.com/hmueller01/pubsubclient3) instead, or downgrade to PubSubClient v2.7.0.

## :fire: MQTT connects / disconnects periodically
The HOSTNAME specified in support.h is used as WiFi hostname, MQTT hostname and OTA hostname. In case that you use more than one MHI-AC-Ctrl, e.g. in a multi-split configuration, you have to use unique HOSTNAME to every PCB.

## :fire: AC switches power off sometimes
When there is for >=120 seconds no valid MISO frame, the AC goes into an error state (MQTT topic Errorcode=1) and the AC switches off. You can leave the error state by sending a command via IR-RC or by sending a command via SPI. To switch on the AC again via SPI you have to send the Power On command. I assume this is some kind of safety function. This happens when there is >=120 seconds no WiFi or MQTT connection, because the SW loop related to SPI is not served.

## :fire: Receiving the AC status works, but can't change values
Different root causes are possible:
### :fire: MISO pin not connected to AC
Please check this [section](#fire-pins-not-properly-connected)

### :fire: Wrong MQTT set path used
The MQTT path for receiving the status is different from the MQTT path for setting values. Re-check that you use the set-path described in [SW-Configuration.md](https://github.com/absalom-muc/MHI-AC-Ctrl/blob/master/SW-Configuration.md#mqtt-status). Please pay attention to the case sensitivity.
## :fire: Last Vanes up/down status not visible in MHI-AC-Ctrl
That is no bug, but a restriction because the SPI unfortunately doesn't provide the Vanes status when the IR remote control was used for the last command.

## :fire: Log shows errors, but it works nevertheless
With some ACs the SPI connection is fragile because of a different timing. E.g.
```
mhi_ac_ctrl_core.loop error: -4
```

Possible error codes:
```
err_msg_invalid_signature = -1
err_msg_invalid_checksum = -2
err_msg_timeout_SCK_low = -3
err_msg_timeout_SCK_high = -4
```

However, this does not appear to be critical and is usually not noticed by the user.

## :fire: Room temperature is toggling
This effect occurs with some AC models. The cause is unclear. 

## :fire: Can't see the device in in Arduino IDE 'tools -> port' for OTA 
I believe this is a general OTA problem, not related to MHI-AC-Ctrl. I made good experience using [espota.py](https://github.com/esp8266/Arduino/blob/master/tools/espota.py) instead of the Arduino IDE for OTA.

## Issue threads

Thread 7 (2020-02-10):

Cannot get it working

gamblor999, 2020-02-10:
I have been trying to get this working with both rjdekkars library and now your library with no success. Below is a picture of my connections which looks the same as your picture (excuse the blurryness) as aircon is right next to wall so was difficult to hook up)

I’ve tried swapping the scl and MOSI but no success I can see mqtt is connecting again and again to my broker which suggests it’s getting caught in the while loop and resetting. This would suggest nothing coming through on the scl but I don’t get it my picture looks the same as yours. I’m using level shifter from spark fun and polu voltage regulator as per rjdekkar with a nodemcu over the Wemos. I’ve tried diffrent cpu frequencies. Any help would be greatly appreciated. My unit is an srk

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

gamblor999, 2020-02-10:
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

gamblor999, 2020-02-10:
Also
When I check the voltages on the aircon port I get the following

Pin1 = 12v
Pin2= 4.7v
Pin3=4.7v
Pin4=2.78v
Pin5 =ground

absalom-muc, 2020-02-10:
Spontaneously I see no mistake. Only in the pictures you write "D7 & D5 (SCL and MISO) swapped", I assume that there is only a typo because it should be SCL and MOSI (instead of MISO), but D7 & D5 is correct.
btw: For your testing I recommend that you connect power supply and SCL only, to prevent unintended driving of an aircon output.

absalom-muc, 2020-02-10:
Can you see that the mqtt is connecting again and again to your broker also when your ESP board is not connected via USB with your computer? With this question I want to ensure that the power supply with your DCDC is working and that the ESP board is not supplied via USB.

gamblor999, 2020-02-10:
Yes when it’s connected to USB on pc it resets due to the while loop digital read as expected and in the serial I just see it connecting to mqtt and then resetting, when connected to the 12v through pololu regulator to 5v I see the same thing on the broker it connects to mqtt and then resets. On your last message I disconnected everything Except scl and power and tried each of the possible 3 pins as scl between ground and 12v and the same thing happened for all of them. Is it possible that maybe there is an srk model that does not work...  I even bought all the parts to rjdekker last version (arduino pro mini, esp and adapter ) followed the code and still no success with that either. No one replies to comments on that one as he no longer maintains it so really appreciate your reply

gamblor999, 2020-02-10:
Out of curiosity do you get the same voltages on each of the 5 pins from the aircon as per my previous message, the one that is 2.78v seems odd was wondering if you have one that voltage also

absalom-muc, 2020-02-10:
Imho a CNS connector is a clear indication for a SPI, but of course the protocol could be different. Nevertheless the SPI CLK should toggle.
Currently I can't check the voltage levels, but your list
Pin1 = 12v
Pin2= 4.7v (SCL)
Pin3=4.7v (MOSI)
Pin4=2.78v (MISO)
Pin5 =ground
seems to be reasonable.
- SCL and MOSI are AC outputs and have mostly a value of 5V, so a value just below 5V seems to be fine.
- MISO is an AC input, every level between 0 - 5V is o.k. (without the knowledge if there are AC internal pull up/down resistors)

Can you measure the SCL and MOSI voltage behind the DCDC-converter? Should be about 3V independent if SCL/MOSI are connected to the ESP board

gamblor999, 2020-02-10:
the voltages behind the level converter that go to the nodemcu were:
Scl= 3.03
MOSI = 3
Miso = 3.22

absalom-muc, 2020-02-10:
The voltage levels look fine. Now we should measure the SCK frequency, expected is approx. 32kHz. but we have to consider that SCK is only sometimes toggling as described in the timing clause of the SPI docu. Can you measure the frequency? With a standard frequency meter I would expect a value of 20*20*8Hz=3.2kHz
If you have no frequency meter we can use most probably the ESP for the measurement.

gamblor999, 2020-02-11:
i have never measured frequency but found a method using the ardunio uno which i tried (readings vary a bit so not sure)
https://github.com/PaulStoffregen/FreqCount
https://www.pjrc.com/teensy/td_libs_FreqCount.html

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

gamblor999, 2020-02-11:
for the above measurements below are the averages for each pin

PIN 2 (SCL) =   5717.17

PIN 3 (MOSI) = 2927.41

PIN 4 (MISI) = 944.79

absalom-muc, 2020-02-11:
To be honest, none of these values make sense for me. Unfortunatelly I can't use the lib you used with my WEMOS board. Therefore I wrote my own very simple frequeny measurement program:

```
// MHI-AC-frequency-simpel_v1.0
// simple frequency measurement for SCK input

#define SCK 14
void setup() {
  Serial.begin(115200);
  pinMode(SCK, INPUT);
}

void loop() {
  uint cnt=0;
  unsigned long starttimeMillis = millis();
  uint SCK_state = digitalRead(SCK);
  while(millis() - starttimeMillis < 1000){
    if(SCK_state != digitalRead(SCK)){
      cnt++;
      SCK_state = !SCK_state;
    }
  }
  Serial.printf("frequency=%i\n", cnt/2);
}
```

Results are between 3040 - 3200. That is the range I expected. Can you try this program?

gamblor999, 2020-02-12:
your code worked really well!   below are the results for pin 2 SCL

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

absalom-muc, 2020-02-12:
Very good. Then let us check if you have the same problem as metarutaiga described [here](https://github.com/absalom-muc/MHI-AC-Ctrl/issues/6) that the signature of your AC is different. Please use the original MHI-AC-Ctrl sketch and replace in row 370
`if ((rx_SPIframe[SB0] == 0x6c) & (rx_SPIframe[SB1] == 0x80) & (rx_SPIframe[SB2] == 0x04) & (rx_SPIframe[CBH] == highByte(rx_checksum)) & (rx_SPIframe[CBL] == lowByte(rx_checksum)))`
by
`if ((rx_SPIframe[SB1] == 0x80) & (rx_SPIframe[SB2] == 0x04) & (rx_SPIframe[CBH] == highByte(rx_checksum)) & (rx_SPIframe[CBL] == lowByte(rx_checksum)))`

So we don't longer check SB0 for detecting of a valid frame.

gamblor999, 2020-02-12:
in below serial it connects ok,  but from the broker  (windows) it never is able to subscribe to a topic  ( am i doing something very wrong here).

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

absalom-muc, 2020-02-12:
What I can see from the screenshot MHI-AC-Ctrl is connected to the broker, so on this side all is working. But I can't tell you why mosquitto_sub is not connecting to the broker (could be a wrong broker configuration, a firewall topic, a virus scanner etc.). The refused connection has nothing to do with MHI-AC-Ctrl, therefore I can't help you with this problem.

gamblor999, 2020-02-12:
Really appreciate all the help you have given to get me to this point.   I have added inbound rules to firewall, temporarily disabled bitdefender and forwarded ports on the router/modem,   I will install mosquitto on my rpi and give it a shot from there perhaps something else in windows i have overlooked.  I will let you know if i do get this going.

one last question:  as a last resort do you know of any online/cloud mqtt brokers i can use that will eliminate any problems in my personal setup/hardware/configuration ?  i have read one of the other closed issues on this thread to add a username and password which seems easy enough.

coyote1, 2020-02-13:
I don't want to open a new issue. Yesterday, i soldered all the components together and did a first test. Looks good so far, all values are displayed in "ioBroker" MQTT Server.
Now my question, no "set /" topics are created, I then created them by myself and then the control of the device also works.

gamblor999, 2020-02-13:
Good sir absalom-muc,  i tip my hat to you!!!   All is working!    I did try changing row 370 back to the original code (including SB0) to see if it would still work but nothing shows up in mqtt execpt connected topic.

For anyone else having issues my setup is as follows:

Model = SRK20ZSA-W
1. Modified version of absalom-muc' code where line 370 has been changed as per the above.
2. Flashed to NodeMCU (not sure if it matters but CPU frequency was 80Mhz
3. AIRCON PIN SETUP
Pin1 = 12V
Pin2 = SCL     -> level converter  -> D5
Pin3 = MOSI  -> level converter -> D7
Pin4 = MISO - > level converter .> D6
Pin5 = GROUND
4. Mqtt broker was setup with openhab on the raspberry pi (anyone with similar setup first 8minutes of this video helped - https://www.youtube.com/watch?v=R-SrZvKHXdA)
5. Tested the mqtt setup using MQtt.fx (as per video).

Thanks for taking the time and for all your help absalom-muc,  I live in Australia and its summer so being able to automate the cooling of the house will make such a difference.

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

absalom-muc, 2020-02-13:
@gamblor999: Great to hear and thank you for the feedback! I have one request: I'm interested to know the signature of your AC. Could you add to row 369
`Serial.println(rx_SPIframe[SB0]);`
and check the results? Thank you!

absalom-muc, 2020-02-13:
@coyote1: The "set/" topics (commands to the AC) have to be published by your client which should control your AC. Publishing e.g. the topic MHI-AC-Ctrl/set/Power with value "On" is the right way. If you have still problems with it please create a new Issue thread

coyote1, 2020-02-13:
OK, thanks for your answer. Works fine so far, can control 3 Aircons now. Good Work 👍

absalom-muc, 2020-02-13:
Congratulation coyote1 - good to hear!

gamblor999, 2020-02-14:
> @gamblor999: Great to hear and thank you for the feedback! I have one request: I'm interested to know the signature of your AC. Could you add to row 369
> `Serial.println(rx_SPIframe[SB0]);`
> and check the results? Thank you!

will get this done tomorrow night and report back! thanks again absalom-muc

gamblor999, 2020-02-18:
Apologies for delay, i had it all soldered and taped up.   new parts came in the mail that i could prototype again to serial debug.
I tried your original code again and it worked with no modification ( originally it appeared i was only getting the subscription for connected,  but this was not the case this time round as all topics are working so have left the code as per your original).

I did run the following as requested:
Serial.println(rx_SPIframe[SB0]);

The serial output displayed   109

I have updated/corrected my comments further up for future readers of this issue,  i will now close this off.

absalom-muc, 2020-02-18:
Thank you gamblor999, enjoy the summer!

aaronactive, 2024-04-16:
Sorry to bring this up again, but is there any help here to fix this on the original [rjdekker](https://github.com/rjdekker)
/
[MHI2MQTT](https://github.com/rjdekker/MHI2MQTT) code? I have the same model SRK20ZSA-W and presumably this is the same issue?

Closed 2020-02-18.

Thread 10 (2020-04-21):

Vanes left/right swing and mode

b0rder, 2020-04-21:
Hi,

    I've successfully connected SRK25ZJ-S to Wemos D1 using this great project.
Just a few notes:
1. Pinout of MHI CNS connector was different from which described in this project (CLK and MOSI should be swapped). So, my CNS connector pinout: +12V, SPI_CLK, SPI_MOSI, SPI_MISO, GND.
2. After flashing ESP8266 with sketch I have  a lot of messages "Wrong MOSI signature". That's because ESP8266 CPU speed was not enough (80MHz). After flashing with CPU speed 160MHz it works like a charm.

I've started to investigate SPI bus protocol according, and found there is nothing about changing Vanes left/right position and mode. Unfortunately I have no wired module to sniff set commands for this operation. Also, the latest status is not changed during operation using IR as well (the same logic as for vanes up/down swing).

If You have wired remote, can You catch the commands during such operations? Probably we can extend SPI bus interface description and then to implement additional commands?

Thanks.

absalom-muc, 2020-04-22:
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
Thank you for your feedback.
> Just a few notes:
>
>     1. Pinout of MHI CNS connector was different from which described in this project (CLK and MOSI should be swapped). So, my CNS connector pinout: +12V, SPI_CLK, SPI_MOSI, SPI_MISO, GND.
I believe that is in sync with the [description](https://github.com/absalom-muc/MHI-AC-Ctrl/blob/master/Hardware.md#connector)
>     2. After flashing ESP8266 with sketch I have  a lot of messages "Wrong MOSI signature". That's because ESP8266 CPU speed was not enough (80MHz). After flashing with CPU speed 160MHz it works like a charm.
That is interesting - thank you! Which SCL frequency is output?
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

Unfortunatelly the wired remote control (I used two different devices) doesn't support vanes left/right. I assume it is in general not supported by the SPI

b0rder, 2020-04-23:
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

This point is a little bit confuse me. According to the schematic PIN2 (SCL?) connected to D7 (GPIO13) and PIN3 (MOSI?) connected to D5 (GPIO14) [description](https://github.com/absalom-muc/MHI-AC-Ctrl/blob/master/Hardware.md#schematic).
But according to source code:

```
#define SCK 14
#define MOSI 13
#define MISO 12

```
I think there is a type in schematic.

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

I didn't use analyzer, but according console output values are not stable (SCKf=5.3kHz...18kHz, MOSIf=0.8...2.5kHz):
```
SCK frequency=5304Hz (expected: >3000Hz)
MOSI frequency=759Hz (expected: <SCK frequency)
SCK frequency=7928Hz (expected: >3000Hz)
MOSI frequency=1118Hz (expected: <SCK frequency)
MOSI frequency=1474Hz (expected: <SCK frequency)
SCK frequency=13077Hz (expected: >3000Hz)
MOSI frequency=1819Hz (expected: <SCK frequency)
SCK frequency=13077Hz (expected: >3000Hz) MOSI frequency=1819Hz (expected: <SCK frequency)
SCK frequency=18253Hz (expected: >3000Hz)
MOSI frequency=2539Hz (expected: <SCK frequency)

```
That's output from a working sketch on 160MHz esp8266 CPU.

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

I think the situation with up/down vanes was the same as for left/right:

> note: Vanes status is not applicable when using IR remote control. The latest vanes status is only visible when it was changed by the SPI-RC. The latest vanes status is only visible when MOSI DB0[7]=1 or MOSI DB1[7]=1.

Also, I have a lot of messages like:
Troom 27.25
...
Troom 24.50

It looks like temperature sensor is not precise, and to avoid very frequent temperature change reporting, I changed:
`        if (updateMQTTStatus | (abs(troom_diff) > 1)) { // Room temperature delta > 0.25°C
`
to
`        if (updateMQTTStatus | (abs(troom_diff) > 10)) { // Room temperature delta > 0.25°C (2°C)
`

And a last question: why You didn't use SPI.h library from Arduino to work with this stuff?

absalom-muc, 2020-04-24:
For the connection of the air conditioner with the MHI-AC-Ctrl PCB we have the following situation:
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
That means when using the MHI-AC-Ctrl PCB the connection cable has to swap MOSI and SCL. Maybe it is a good idea to add this diagram to the description to make it clearer.

> And a last question: why You didn't use SPI.h library from Arduino to work with this stuff?

Originally when I started with the hardware SPI from ESP8266 and using the Arduino stuff. I managed to use the RX path with the HW SPI (see [here](https://github.com/absalom-muc/MHI-AC-SPY)). But I found no way to transmit data synchronously to the receive data with the HW SPI. Therefore I use the SW SPI.

Related to the other topics I will come back to you later.

absalom-muc, 2020-04-24:
It seems that your SRK xx ZJ-S uses a higher SCK frequency than my SRK xx ZS-S. Where you see SCKf=5.3kHz...18kHz, I see more or less constant fsck=3200Hz. I can imagine that the SW SPI can't manage your high SCK frequencies when running at 80MHz. Therefore, switching the CPU to 160MHz was a good idea.
But it still seems that it works not really stable because of the SCK frequency variations (it should be a constant value and not always changing).
Maybe the toggling Troom temperature values is related to this instability. The temperature sensor of the indoor unit might not be accurate, but it should provide stable values when there is no temperature change. My AC provides stable values. I observe toggling of the least significant bit only, that is related to 0.25°C.

Summarized I assume we can improve the MHI-AC-Ctrl for you AC but it will be some effort on my side and on your side for testing. I am o.k. to spend this time, but before I start with further evaluations, please give me feedback if you are interested to improve it and if you are willing to make some tests.

b0rder, 2020-04-24:
> It seems that your SRK xx ZJ-S uses a higher SCK frequency than my SRK xx ZS-S. Where you see SCKf=5.3kHz...18kHz, I see more or less constant fsck=3200Hz. I can imagine that the SW SPI can't manage your high SCK frequencies when running at 80MHz. Therefore, switching the CPU to 160MHz was a good idea.

I'll try to get frequency analyser and to measure frequency of PIN2 (SCL) directly on MHI...

> But it still seems that it works not really stable because of the SCK frequency variations (it should be a constant value and not always changing).

Even it is not really stable, I don't notice that :) It works :)
Probably, there is something wrong when ESP measures freauency, but I am not sure. That's why I want to measure SCL with frequency analyzer.

> Maybe the toggling Troom temperature values is related to this instability. The temperature sensor of the indoor unit might not be accurate, but it should provide stable values when there is no temperature change. My AC provides stable values. I observe toggling of the least significant bit only, that is related to 0.25°C.

Tha'ts really strange. One more thing I noticed, few years ago my SRK25ZJ-S stops produce beep sound (when I start/stop power, or when I change mode in cycle). I don't know can it be related somehow with SCK stability, but I hope there is some problem with buzzer (or contacts on board, but I am not sure).

> Summarized I assume we can improve the MHI-AC-Ctrl for your AC but it will be some effort on my side and on your side for testing. I am o.k. to spend this time, but before I start with further evaluations, please give me feedback if you are interested to improve it and if you are willing to make some tests.

Yes, I am ready to make some tests.

absalom-muc, 2020-04-26:
Perfect, then let us start with the frequency measurement.
[f_measurement.txt](https://github.com/absalom-muc/MHI-AC-Ctrl/files/4534698/f_measurement.txt)
SInce it is not supported to attach .ino-files I renamed it to .txt. So, please rename it back to f_measurement.ino, run it  for approx. 1 minute and provide the log file from the serial output. (preferred as an attachment ending with .log).
If you see that the SCK results are not stable, please comment out the MOSI and MISO related stuff in line 44,45,50,51 and 57,58 and make a second run.
Thank you.

b0rder, 2020-04-27:
I performed test using provided f_measurement.ino. I didn't change it.
Results for run at 160MHz CPU:
[measurement_160.log](https://github.com/absalom-muc/MHI-AC-Ctrl/files/4538268/measurement_160.log)
Results for run at 80MHz CPU (AC power on):
[measurement_80.log](https://github.com/absalom-muc/MHI-AC-Ctrl/files/4538269/measurement_80.log)
Results for run at 80MHz CPU (AC power ON, then power OFF, then power ON):
[measurement_80_on_off_on.log](https://github.com/absalom-muc/MHI-AC-Ctrl/files/4538271/measurement_80_on_off_on.log)

SCK frequency seems to be stable - 2.5-2.7kHz now :)

absalom-muc, 2020-04-28:
Perfect, thank you! Originally I believed that SCK of your AC has a higher frequency than my AC. But now it is visible that SCK=2720Hz only. That may mean that more time is consumed for receiving a frame, so there is less time left for publishing MQTT data.
Could you make another test? Please add the following line to row 378:

```
   Serial.println("f");  // <- please insert his line
    if (((rx_SPIframe[SB0] & 0xfe) == 0x6c) & (rx_SPIframe[SB1] == 0x80) & (rx_SPIframe[SB2] == 0x04) & ((rx_SPIframe[CBH]<<8 | rx_SPIframe[CBL]) == rx_checksum)) {
      valid_datapacket_received = true;
    }
```
and enable "show timestamp" of the serial monitor. Please log it for 1 minute during power off. And another log when power on.
Thank you!

b0rder, 2020-04-28:
[test_poff.log](https://github.com/absalom-muc/MHI-AC-Ctrl/files/4547991/test_poff.log)
[test_pon.log](https://github.com/absalom-muc/MHI-AC-Ctrl/files/4547992/test_pon.log)

absalom-muc, 2020-04-29:
o.k. thank you. Will check it and come back to you

absalom-muc, 2020-05-02:
I have another (most probably last) test. Please run for ~1 minute and send me the log.
[frame_measurement_0.4.txt](https://github.com/absalom-muc/MHI-AC-Ctrl/files/4568603/frame_measurement_0.4.txt)

b0rder, 2020-05-03:
I performed run more then ~1minute:
Run when AC is off.
23:12:27 - AC switched on (ventilator mode)
23:13:25 - AC switched to auto mode
23:15:03 - AC switched to cool mode
23:20:00 - AC switched on
Result in attachment.
[frame_measurement_0.4.log](https://github.com/absalom-muc/MHI-AC-Ctrl/files/4571533/frame_measurement_0.4.log)

absalom-muc, 2020-05-08:
Thank you b0rder, I'm still checking it and come back to you ...

absalom-muc, 2020-05-12:
When comparing the SPI timing
AC|T<sub>Frame</sub>|T<sub>FramePause</sub>|T<sub>Byte</sub>|T<sub>BytePause</sub>|T<sub>Bit</sub>
---|---|---|---|---|---|
SRK xx ZS-S|10ms|40ms|250µs|250µs|31.25µs
SRK xx ZJ-S|10ms|44ms|120µs|360µs|15µs

the main difference is the doubling of the bit frequency. Overall the measurement was very unstable. I do not know the reason, maybe the cable between AC and MHI-AC-Ctrl is too long. However, since this does not create a problem, we should make no further efforts.

I had also deeper look on your logs [here](https://github.com/absalom-muc/MHI-AC-Ctrl/issues/10#issuecomment-620799365). I have no idea why there are so many temperature changes reported. The SPI connection to the AC is stable (only few async messages). It seems to be something different or wrong with your AC. Sorry, but I don't know how to improve it.
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
absalom-muc, 2020-05-15:
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

The message "async: millis() - lastDatapacketMillis > 35" informs you that you loose the SPI synchronization, because the program execution between 2 frames took more than 35ms. If you loose the synchronization you will have more messages "Wrong MOSI signature ..."
With increasing the 35 to 200 you suppress the warning, but if you can still use the program to control the AC I see no issue.

absalom-muc, 2020-06-24:
@b0rder Could you run the [SPI logger](https://github.com/absalom-muc/MHI-AC-Ctrl/blob/master/testprog/SPI_logger.ino) and provide the log? That would be helpful to understand the differences in the SPI protocol.

absalom-muc, 2020-08-09:
If you are still interested in a follow up, please feel free to re-open this issue

Closed 2020-08-09.

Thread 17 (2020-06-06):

Add supported MHI models

waynethomas69, 2020-06-06:
Hi not really an issue, but thought you would like to know your base code works with the SRK50ZJX-S1 heat pump also. Only issue noted is the SCK frequency is measured incorrectly, but this doesn't affect operation. Checked SPI output using a logic analyser and actual SCK was around 60kHz (from memory) but measured as 2500Hz.
Haven't tested v2.0 yet (only just noticed you updated).
Cheers
Wayne

absalom-muc, 2020-06-06:
I am absolutely interested in such feedback, thank you.

The frequency measurement counts the rising edges for 1 second. The result is only meaningful, if the timing of your AC is identical to the timing of the SRK xx ZS-S. That means only if you have 20 frames in one second (1frame=20byte=20 x 8bit=160bit => 20frame x 160bit=3200). So also with the latest version you will see no meaningful results. But as you mentioned, that is no restriction for the normal usage.

ThatsIT67, 2020-06-14:
Hi, I'm using your program for the AC SRK60ZSX-W and it works fine! You have done a great job!!!

absalom-muc, 2020-06-15:
Thank you for your feedback @ThatsIT67. I'm glad to hear that.

makonrus, 2020-06-19:
Hello! Thanks for the project. I connected the air conditioner SRK25ZJX-S.
1) Power On/Off - Perfect!
2) Fan speed. In total, the air conditioner has 3 fan speeds. Do I understand correctly that mode 4 is an automatic mode? - Perfect!
3) Mode. Fail... When I try to turn on any of the modes, the Heat mode is turned on:
```
MQTT_subscribe_callback, topic=MHI-AC-Ctrl/set/Mode payload=Cool
status=67 value=16
status=67 topic=Mode payload=Heat
status=128 value=16
status=128 topic=Mode payload=Heat
status=129 value=26
status=129 topic=Tsetpoint payload=26
status=137 value=4
status=137 topic=OU-FANSPEED payload=4
status=133 value=1
status=133 topic=IU-FANSPEED payload=1
mhi_ac_ctrl_core.loop error: -2
```
4) Setpoint temp. - Perfect!

absalom-muc, 2020-06-20:
Thanks for your feedback. Please find my response below:

>     2. Fan speed. In total, the air conditioner has 3 fan speeds. Do I understand correctly that mode 4 is an automatic mode? - Perfect!
There should be 4 different fan speeds, no auto mode for the fan.

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

Please create a log with time stamp and some more entries before and after the effect. In addition, how does row 30 of [MHI-AC-Ctrl-core.h](https://github.com/absalom-muc/MHI-AC-Ctrl/blob/f762d00571a6530e3519ce7a6949f2a7054d8a81/src/MHI-AC-Ctrl-core.h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)
`//#define POWERON_WHEN_CHANGING_MODE true`
looks like?, Unchanged or have you commented it in?

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
We've seen this instability alrady e.g. in the [issue10](https://github.com/absalom-muc/MHI-AC-Ctrl/issues/10).  I couldn't find out the root cause, but since this seems to be not critical, I postponed it. btw: If you have an oscilloscope, a measurement would be helpful.

waynethomas69, 2020-06-20:
Me again, also works with my SRF50ZJX-S1. Only issue was this model AC seems to vomit room temperature readings constantly in pairs (0.5 degrees difference). I added an averaging filter for the pairs and another filter to reduce the number of outputs. No issue with your code, just an oddity about this AC model. Thanks again for your great work!!!
Cheers

absalom-muc, 2020-06-20:
Thank you for the feedback @waynethomas69!

absalom-muc, 2020-06-20:
sorry, closed it unintenionally...

absalom-muc, 2020-06-21:
I added a testprogram to folder [testprog](https://github.com/absalom-muc/MHI-AC-Ctrl/tree/master/testprog) and I would appreciate when you could upload here the according logfile. My intention is to find out, if the timing of MHI-AC-Ctrl should be adapted to improve it for further AC models.

scottm1985, 2020-10-07:
@absalom-muc thanks for sharing this, it works perfectly on my SRF35ZMX-S

absalom-muc, 2020-10-07:
Great 👍 thanks for your feedback @scottm1985

L4RGER, 2020-11-19:
@absalom-muc awesome work man, can confirm this works with
SRK95ZRA-W
Have control through Apple Home app using Home Assistant.
Changes made as per @deverelo post above

drdoener, 2021-03-06:
Hi, I'm using it for the AC MHI SRK 35 ZSX - W and it works perfect!
It´s a superb project.
Please advise if I can support you anyhow.

absalom-muc, 2021-03-07:
Thanks for your feedback @drdoener - I'm happy to hear that.
Have you used the latest PCB layout from Feb 2021 or the previous version?

drdoener, 2021-03-07:
I use the previous version. Due to the limited space in the device, I focussed already ne new PCB layout. It seems to be really good improvement.

joshuammex, 2021-08-03:
Thanks for your work on this.
The hardware and code works for a SETSRK25ZSA-W (C2.5kW H3.2kW Reverse Cycle Split System). I did have issues with Mosquitto in Home Assistant picking up the new MQQT device (probably unrelated to this project), so I've instead installed the ESPHome fork (https://github.com/ginkage/MHI-AC-Ctrl-ESPHome).

kARTechnology, 2022-01-20:
MHI SRK18YXS2-W6 Model supported. working without any bugs. highest Indian ISEER model, 1.65ton..
installed in the case itself, discreet.

tharealmb, 2022-04-05:
AC MHI SRK 35 ZSX - WT works too. It's the same as the other ZSX that are already listed. Just a different color (W=white, WB=White/Black, WT=Titanium)

FloR012, 2022-12-29:
Hi,
Thanks for your awesome work. I ordered the OCB with the provided Gerber Files from JLCPCB and it works perfectly with my SRF25-ZJX-S and SRF25-ZJX-S. But the PCB does hardly fit into the cabinet so I placed outside next to the power supply cables. There is a lot of space.

The DC-DC converter was hard to get, but the TSR 1-2450E seems to be the successor of TSR 1-2450 and can also be used.
Best regards from Germany

absalom-muc, 2023-01-02:
Thanks for yor feedback @FloR012

A discussion related to the TSR1-2450E was started [here](https://github.com/absalom-muc/MHI-AC-Ctrl/issues/102). I had also the impression that the 'E'-version it an adequate replacement - good to hear that you can confirm.

Fix1985, 2023-06-18:
Thanks for the good work.
I have a SRK25ZS-W that works great.
I also have an SRF50ZSX-W as a chest.
Unfortunately it is not read. I installed MHI-AC_CTRL as ESP Home. I haven't found the testprog yet.

glsf91, 2023-10-02:
Closed because of no activity for a long time

Krava615, 2024-04-08:
Hello! Does someone know is it Homebridge compatible?

Closed 2023-10-02.

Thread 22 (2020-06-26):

MISO frequency issue?

Daryn-L, 2020-06-26:
Hey mate,

I wonder if you can help me.  I have just soldered up your circuit and have a problem with the MISO frequency it seems.

Here is the running log:
```
MHI-AC-Ctrl starting
CPU frequency[Hz]=80000000
Found 0 DS18xxx family devices.
Unable to find address for Device 0
Device 0 Address: 0000000000000000
Attempting WiFi connection ....... connected to 42 Grey Street, IP address: 192.168.1.91
OTA Ready
Attempting MQTT connection... connected
status=65 topic=connected payload=1
status=64 topic=RSSI payload=-89
Measure frequency for SCK, MOSI and MISO pin
SCK frequency=3196Hz (expected: >3000Hz) o.k.
MOSI frequency=478Hz (expected: <SCK frequency) o.k.
MISO frequency=3435Hz (expected: ~0Hz) out of range!

Soft WDT reset

>>>stack>>>

ctx: cont
sp: 3ffffdb0 end: 3fffffc0 offset: 01a0
3fffff50:  3ffee8bc 3ffee8c4 3ffeeb34 40202b8d
3fffff60:  35333433 3ffe8900 3ffeea00 40202a00
3fffff70:  0039382d 3ffee8d8 3ffee908 3ffeec7c
3fffff80:  3fffdad0 00000000 3ffee908 402021ff
3fffff90:  402018c0 feefeffe 4020f600 4020f5e8
3fffffa0:  feefeffe feefeffe 3ffeec3c 4020d9a0
3fffffb0:  feefeffe feefeffe 3ffe850c 40101135
<<<stack<<<

ets Jan  8 2013,rst cause:2, boot mode:(3,2)

load 0x4010f000, len 3456, room 16
tail 0
chksum 0x84
csum 0x84
va5432625
~ld
```

Here is the freqency log:

```
acquisition-please wait, ready: acq. time=999ms f=3200 time to 1st falling edge=35µs
cycle_time_min[0]=33µs, delta_time[0]=1µs, cycle_time_cnt=2800
cycle_time_min[1]=266µs, delta_time[1]=3µs, cycle_time_cnt=379
cycle_time_min[2]=40268µs, delta_time[2]=1µs, cycle_time_cnt=20
delta_cycle_time_max 9 6 4

acquisition-please wait, ready: acq. time=959ms f=3200 time to 1st falling edge=13156µs
cycle_time_min[0]=33µs, delta_time[0]=1µs, cycle_time_cnt=2800
cycle_time_min[1]=265µs, delta_time[1]=4µs, cycle_time_cnt=380
cycle_time_min[2]=40266µs, delta_time[2]=3µs, cycle_time_cnt=19
delta_cycle_time_max 9 6 4
```

And the SPI log:
https://www.dropbox.com/s/1co2uv9fxcv0zp7/SPI%20Log.txt?dl=0

I'm not really sure how any of this works, but if you could give me an idea of what might be wrong it would be greatly appreciated.

Daryn-L, 2020-06-26:
Actually I think I may have bought the wrong type of logic shifter, 2-channel instead of 4-channel...

damienmorrissey, 2020-06-26:
That'd do it.

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

absalom-muc, 2020-06-26:
The MISO which is an output of the ESP8266 detected a signal during start-up, and that shouldn't be. Maybe you have a short between MISO and SCK.

Daryn-L, 2020-06-28:
Yes I just had bought the wrong level shifter.  It is working now.  But there is a new issue which I think warrants a new thread...

Closed 2020-06-28.

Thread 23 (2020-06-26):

Home Assistant

artbrayko, 2020-06-26:
Do you have an example of integration in Home assistant?

absalom-muc, 2020-06-26:
Unfortunatelly I've no experience with Home assistant. In general you have to setup a MQTT server for receiving the messages from MHI-AC-Ctrl. But maybe @apateluk or @ThomasHFWright who discussed a Home assistant topic in [this issue](https://github.com/absalom-muc/MHI-AC-Ctrl/issues/14) could support you.

apateluk, 2020-06-26:
You need to add the climate mqtt platform to your configuration. Note, I havn't tried the latest build of MHI-AC-Ctrl yet, but is meant to be more compatible with HA.
Below is my configuration,  but note some of the string and topic names may be different to the defaults and HA likes everything to be lowercase.

`climate:
  - platform: mqtt
    unique_id: mhi0001a
    name: LoftAC
    initial: 22
    min_temp: 18
    max_temp: 30
    modes:
      - "auto"
      - "dry"
      - "cool"
      - "fan_only"
      - "heat"
      - "off"
    swing_modes:
      - "1"
      - "2"
      - "3"
      - "4"
      - "Swing"
    fan_modes:
      - "1"
      - "2"
      - "3"
      - "4"
    mode_command_topic: "MHInterface/set/Mode"
    mode_state_topic: "MHInterface/Mode"
    temperature_command_topic: "MHInterface/set/Tsetpoint"
    temperature_state_topic: "MHInterface/Tsetpoint"
    fan_mode_command_topic: "MHInterface/set/Fan"
    fan_mode_state_topic: "MHInterface/Fan"
    swing_mode_command_topic: "MHInterface/set/Vanes"
    swing_mode_state_topic: "MHInterface/Vanes"
    current_temperature_topic: "MHInterface/Troom"`

artbrayko, 2020-06-26:
Thanks, at least some understanding. If you still know what, please write.

artbrayko, 2020-08-25:
I added to configuration.yaml as you wrote above,
only the topic names were left by default (MHI-AC-Ctrl) but nothing happens. Please tell me what am I doing wrong?
In MQTT Explorer I can see that data is being transferred.
.........
............
    mode_command_topic: "MHI-AC-Ctrl/set/Mode"
    mode_state_topic: "MHI-AC-Ctrl/Mode"
    temperature_command_topic: "MHI-AC-Ctrl/set/Tsetpoint"
    temperature_state_topic: "MHI-AC-Ctrl/Tsetpoint"
    fan_mode_command_topic: "MHI-AC-Ctrl/set/Fan"
    fan_mode_state_topic: "MHI-AC-Ctrl/Fan"
    swing_mode_command_topic: "MHI-AC-Ctrl/set/Vanes"
    swing_mode_state_topic: "MHI-AC-Ctrl/Vanes"
    current_temperature_topic: "MHI-AC-Ctrl/Troom"

sstmelbourne, 2020-09-17:
At first thanks @absalom-muc for the great effort in the compiling.

I have set up my yaml as above, everything works except;

AC unit is off - can't switch the ac unit on from the UI of HA. However when a command "On" is sent to the the topic MHI-AC-Ctrl/set/Power via an mqtt.fx the AC unit turns on.

Once the AC is on, modes (heat, cool, dry) from the front UI of HA function, it will change on the AC as well.

When I switch to "Off" front he UI of HA it doesn't work and unit doesn't respond. - error I get when looked up on serial communication of D1 mini is "invalid command".

However, when an "Off" command is published from the mqtt.fx to the power topic it switches off.

In summary the on and off command are not working from the UI of the HA.

Anyone come up with this issue, if so any solution.

Thanks

L4RGER, 2021-01-21:
did you check the updated wiring picture absalin posted?

Also whats the topic for the DS18B20, i cannot get a readinf out of it.
i tried subscribing to TOPIC_TDS1820 "Tds1820"

absalom-muc, 2022-06-16:
closed since there was no update for a long time. Please feel free to re-open in case of follow-up topics.

hart0x, 2022-06-17:
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

If you add this line in HA:
    power_command_topic: "MHI-AC-Ctrl/set/Power"
and change the following 2 lines in MHI-AC-Ctrl.h from:
#define PAYLOAD_POWER_ON "On"
#define PAYLOAD_POWER_OFF "Off"
to:
#define PAYLOAD_POWER_ON "ON"
#define PAYLOAD_POWER_OFF "OFF"
It seems to work then..

scottm1985, 2023-11-09:
Has anybody got this working in Home Assistant with the new config layout?
I've got temperature working but for some reason I can't see the current operation or power status even though the MQTT topics are populated.  This is the configuration I have currently:
`
mqtt:
  climate:
    unique_id: mhi0001a
    name: HeatPump
    initial: 18
    min_temp: 18
    max_temp: 30
    modes:
      - "auto"
      - "dry"
      - "cool"
      - "fan_only"
      - "heat"
      - "off"
    swing_modes:
      - "1"
      - "2"
      - "3"
      - "4"
      - "Swing"
    fan_modes:
      - "1"
      - "2"
      - "3"
      - "4"
    mode_command_topic: "MHI-AC-Ctrl/set/Mode"
    mode_state_topic: "MHI-AC-Ctrl/Mode"
    temperature_command_topic: "MHI-AC-Ctrl/set/Tsetpoint"
    temperature_state_topic: "MHI-AC-Ctrl/Tsetpoint"
    fan_mode_command_topic: "MHI-AC-Ctrl/set/Fan"
    fan_mode_state_topic: "MHI-AC-Ctrl/Fan"
    swing_mode_command_topic: "MHI-AC-Ctrl/set/Vanes"
    swing_mode_state_topic: "MHI-AC-Ctrl/Vanes"
    current_temperature_topic: "MHI-AC-Ctrl/Troom"
`

Timple, 2023-11-09:
Honestly I just use: https://github.com/ginkage/MHI-AC-Ctrl-ESPHome
It's based on this nice project. But works out of the box for home assistant.

Allinijhof, 2023-11-21:
I have been able to toggle / Target / Fan mode and Swing mode successfully, hence unfortunately I am not able to enable the features displayed under Mode.

If I select "Heat" = I can see a message has been send through MQTT topic: MHI-AC-Ctrl/set/Mode = heat

I can see a response through MQTT topic: MHI-AC-Ctrl/cmd_received = invalid parameter

Can you advice how to resolve the parameter issue?

Please find attached the software I have loaded on to the Wemos D1;

[MHI-AC-Ctrl.zip](https://github.com/absalom-muc/MHI-AC-Ctrl/files/13430988/MHI-AC-Ctrl.zip)

Please find below a screenshot of Home Assistant entity and MQTT explorer;

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

Please find below the code in configuration.yaml

mqtt:
  climate:
    unique_id: mhiacctrl
    name: mhictrlac
    initial: 15
    min_temp: 15
    max_temp: 30
    modes:
      - "auto"
      - "dry"
      - "cool"
      - "fan_only"
      - "heat"
      - "off"
    swing_modes:
      - "1"
      - "2"
      - "3"
      - "4"
      - "Swing"
    fan_modes:
      - "1"
      - "2"
      - "3"
      - "4"
    mode_command_topic: "MHI-AC-Ctrl/set/Mode"
    mode_state_topic: "MHI-AC-Ctrl/Mode"
    temperature_command_topic: "MHI-AC-Ctrl/set/Tsetpoint"
    temperature_state_topic: "MHI-AC-Ctrl/Tsetpoint"
    fan_mode_command_topic: "MHI-AC-Ctrl/set/Fan"
    fan_mode_state_topic: "MHI-AC-Ctrl/Fan"
    swing_mode_command_topic: "MHI-AC-Ctrl/set/Vanes"
    swing_mode_state_topic: "MHI-AC-Ctrl/Vanes"
    current_temperature_topic: "MHI-AC-Ctrl/Troom"

Many thanks for your help!

Regards,
Allard

scottm1985, 2023-11-21:
I figured this out after reading the documentation.  There is a line in support.h
```cpp
#define POWERON_WHEN_CHANGING_MODE true
```
that needs to be uncommented to be able to turn on and off with Home Assistant.
And then you need to change MHI-AC-Ctrl.h so that your mode payloads are as follows
```cpp
#define PAYLOAD_MODE_AUTO "auto"
#define PAYLOAD_MODE_STOP "stop"
#define PAYLOAD_MODE_DRY "dry"
#define PAYLOAD_MODE_COOL "cool"
#define PAYLOAD_MODE_FAN "fan_only"
#define PAYLOAD_MODE_HEAT "heat"
```
Home Assistant is receiving "Heat" when it should be "heat".
Your YAML looks correct.

Allinijhof, 2023-11-22:
Excellent it working perfectly!

Allinijhof, 2023-11-24:
@scottm1985  I have do want to add a second AC to Home Assistant, I have created a prefix HOSTNAME Room1 and Room2 however unfortunately the Dasboard in Home Assistant is no longer working. Once I delete either Room1 or Room2 (so basically just have one HOSTNAME / HOSTNAME prefix) the dashboard is working.

Could you please advise what I am missing?

#define MQTT_PREFIX HOSTNAME "/Room1/"                    // basic prefix used for publishing AC data (e.g. for status),
                                                    // replace "/" by e.g. "/Living-Room/" when you have multiple ACs

Please find below the details of the configuration.yaml file in Home Assistant.

mqtt:
  climate:
    unique_id: MHI-AC-Ctrl-Room1
    name: MHI-AC-Ctrl-Room1
    initial: 15
    min_temp: 15
    max_temp: 30
    modes:
      - "auto"
      - "dry"
      - "cool"
      - "fan_only"
      - "heat"
      - "off"
    swing_modes:
      - "1"
      - "2"
      - "3"
      - "4"
      - "Swing"
    fan_modes:
      - "1"
      - "2"
      - "3"
      - "4"
    mode_command_topic: "MHI-AC-Ctrl/Room1/set/Mode"
    mode_state_topic: "MHI-AC-Ctrl/Room1/Mode"
    temperature_command_topic: "MHI-AC-Ctrl/Room1/set/Tsetpoint"
    temperature_state_topic: "MHI-AC-Ctrl/Room1/Tsetpoint"
    fan_mode_command_topic: "MHI-AC-Ctrl/Room1/set/Fan"
    fan_mode_state_topic: "MHI-AC-Ctrl/Room1/Fan"
    swing_mode_command_topic: "MHI-AC-Ctrl/Room1/set/Vanes"
    swing_mode_state_topic: "MHI-AC-Ctrl/Room1/Vanes"
    current_temperature_topic: "MHI-AC-Ctrl/Room1/Troom"
  climate:
    unique_id: MHI-AC-Ctrl-Room2
    name: MHI-AC-Ctrl-Room2
    initial: 15
    min_temp: 15
    max_temp: 30
    modes:
      - "auto"
      - "dry"
      - "cool"
      - "fan_only"
      - "heat"
      - "off"
    swing_modes:
      - "1"
      - "2"
      - "3"
      - "4"
      - "Swing"
    fan_modes:
      - "1"
      - "2"
      - "3"
      - "4"
    mode_command_topic: "MHI-AC-Ctrl/Room2/set/Mode"
    mode_state_topic: "MHI-AC-Ctrl/Room2/Mode"
    temperature_command_topic: "MHI-AC-Ctrl/Room2/set/Tsetpoint"
    temperature_state_topic: "MHI-AC-Ctrl/Room2/Tsetpoint"
    fan_mode_command_topic: "MHI-AC-Ctrl/Room2/set/Fan"
    fan_mode_state_topic: "MHI-AC-Ctrl/Room2/Fan"
    swing_mode_command_topic: "MHI-AC-Ctrl/Room2/set/Vanes"
    swing_mode_state_topic: "MHI-AC-Ctrl/Room2/Vanes"
    current_temperature_topic: "MHI-AC-Ctrl/Room2/Troom"

Beste regards,

Allard

Allinijhof, 2023-11-26:
By creating unique HOSTNAME's and PREFIX'es MQTT has been able to divide the messages. The issue has been resolved and I am now able to control my three AC's through Home Assistant. Many thanks for your help!

glsf91, 2023-11-27:
I added this issue in the Integration examples list for as Home Assistant.
As it is solved I will close this item.

Closed 2023-11-27.

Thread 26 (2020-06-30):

First run problem

aleksandrdobrynin, 2020-06-30:
Greetings.

Thanks a lot for such a cool thing. But I can’t start something: /

I assembled the module, flashed it with the latest firmware, connected it to the air conditioner, in MQTT Explorer I see only that (see screen). What could be wrong?
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

aleksandrdobrynin, 2020-06-30:
It is also alarming that the pings are interrupted, maybe it doesn’t catch the wifi network well, but another device is nearby and works fine.
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

absalom-muc, 2020-06-30:
Hello,
1. Which AC model do you have? Please tell me the exact name e.g. SRK 35 ZS-S
2. Please provide an extract of the serial monitor output (115200Baud, Timestamp enabled)

aleksandrdobrynin, 2020-06-30:
1. SRK 25ZS-W
2. Please tell me how to do this? I do not quite understand (

aleksandrdobrynin, 2020-06-30:
Still, instead of the power that is implemented in the project, I set this with an output of 5v:
https://aliexpress.ru/item/4000035788248.html?spm=a2g0s.9042311.0.0.402133edyUWAbH

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

absalom-muc, 2020-06-30:
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

if you use the Arduino IDE, select tools -> serial monitor. Since this is very basic, please use Google for further details how to use the serial monitor.

aleksandrdobrynin, 2020-06-30:
11:49:41.688 -> MHI-AC-Ctrl starting
11:49:41.688 -> CPU frequency[Hz]=80000000
11:49:41.721 -> Attempting WiFi connection .... connected to ilink2G, IP address: 192.168.252.215
11:49:42.207 -> OTA Ready
11:49:42.207 -> Attempting MQTT connection... connected
11:49:42.207 -> status=65 topic=connected payload=1
11:49:42.207 -> status=64 topic=RSSI payload=-58
11:49:42.241 -> Measure frequency for SCK, MOSI and MISO pin
11:49:43.238 -> status=68 value=0
11:49:43.238 -> status=68 topic=fSCK payload=0
11:49:43.238 -> status=69 value=0
11:49:43.238 -> status=69 topic=fMOSI payload=0
11:49:43.238 -> status=70 value=0
11:49:43.238 -> status=70 topic=fMISO payload=0
11:49:43.238 -> SCK frequency=0Hz (expected: >3000Hz) out of range!
11:49:43.238 -> MOSI frequency=0Hz (expected: <SCK frequency) out of range!
11:49:43.238 -> MISO frequency=0Hz (expected: ~0Hz) o.k.
11:49:44.229 -> mhi_ac_ctrl_core.loop error: -1
11:49:44.583 -> mhi_ac_ctrl_core.loop error: -1
11:49:44.931 -> mhi_ac_ctrl_core.loop error: -1
11:49:45.294 -> mhi_ac_ctrl_core.loop error: -1
11:49:45.621 -> mhi_ac_ctrl_core.loop error: -1
11:49:45.963 -> mhi_ac_ctrl_core.loop error: -1
11:49:46.317 -> mhi_ac_ctrl_core.loop error: -1
11:49:46.661 -> mhi_ac_ctrl_core.loop error: -1
11:49:47.026 -> mhi_ac_ctrl_core.loop error: -1
11:49:47.394 -> mhi_ac_ctrl_core.loop error: -1

absalom-muc, 2020-06-30:
You mixed MOSI and SCK pins. Swap the connections or adapt MHI-AC-Ctrl-core.h
old
```
#define SCK_PIN  14
#define MOSI_PIN 13
```
new
```
#define SCK_PIN  13
#define MOSI_PIN 14
```
And ensure that MISO is connected to Pin 12

aleksandrdobrynin, 2020-06-30:
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
The data ran! )))
Only does not display the position of the curtain. Is he just writing a sign? I tried to change the position from the remote control, the situation has not changed.

aleksandrdobrynin, 2020-06-30:
I tried to send Off or On in RAW format to the MHI-AC-Ctrl-LR / Power topic via MQTT Explorer, but the air conditioner does not react in any way.

absalom-muc, 2020-06-30:
>
>
> I tried to send Off or On in RAW format to the MHI-AC-Ctrl-LR / Power topic via MQTT Explorer, but the air conditioner does not react in any way.

Please provide an extract of the serial monitor output (115200Baud, Timestamp enabled).
Have you changed something in the program? I'm surprised that fSCK=0, it should be aprox. 3200.
The curtain topic is described in https://github.com/absalom-muc/MHI-AC-Ctrl/blob/master/SW-Configuration.md#mqtt-status

aleksandrdobrynin, 2020-06-30:
Changed only this:
old

#define SCK_PIN 14
#define MOSI_PIN 13
new

#define SCK_PIN 13
#define MOSI_PIN 14

And reloaded the firmware. Didn’t change anything anymore.

fSCK is ok
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

aleksandrdobrynin, 2020-07-01:
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

I worked for a couple of hours and fell off, does not respond to / set commands. fSCK shows 0

Also there was an open wifi network. Or should it be?

aleksandrdobrynin, 2020-07-01:
12:15:37.205 -> mhi_ac_ctrl_core.loop error: -2
12:15:37.312 -> mhi_ac_ctrl_core.loop error: -2
12:15:37.420 -> mhi_ac_ctrl_core.loop error: -2
12:15:37.520 -> mhi_ac_ctrl_core.loop error: -2
12:15:37.624 -> mhi_ac_ctrl_core.loop error: -2
12:15:37.727 -> mhi_ac_ctrl_core.loop error: -2
12:15:37.801 -> mhi_ac_ctrl_core.loop error: -2
12:15:37.902 -> mhi_ac_ctrl_core.loop error: -2
12:15:38.012 -> mhi_ac_ctrl_core.loop error: -2
12:15:38.118 -> mhi_ac_ctrl_core.loop error: -2

absalom-muc, 2020-07-01:
In your log are no MQTT accesses visible. Have you considered the desciption in https://github.com/absalom-muc/MHI-AC-Ctrl/blob/master/SW-Configuration.md#mqtt-status? Especially that the MQTT path for setting values is different from the path for reading values, e.g. MHI-AC-Ctrl/**set**/Power

I don't understand your statement:
>  fSCK shows 0

If fSCK=0 then the program would do nothing, and [here](https://github.com/absalom-muc/MHI-AC-Ctrl/issues/26#issuecomment-651960971) you show that fSCK=3200.

If you used previously the ESP8266 for an open WiFi then it could happen that the old configuration is stored. To prevent this, you could use once the option tools -> Erase Flash -> All Flash Contents when compiling/uploading the sketch in the Arduino IDE.

Your log shows many errors, but these are not critical and we take care later once the basic functionality works.

aleksandrdobrynin, 2020-07-01:
I download the firmware with the checkmark on clearing flash checked, but after downloading, the Wi-Fi point is visible anyway.
Tell me which version of arduino ide  to use and what settings to set with firmware?

aleksandrdobrynin, 2020-07-01:
Now there is such a log in the console (cyclic reboot).
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
aleksandrdobrynin, 2020-07-03:
Tell the correct syntax:

void setupWiFi (WiFi.persistent (false), WiFi.mode (WIFI_STA));

So I get a compilation error.

absalom-muc, 2020-07-03:
Please copy it from my post

aleksandrdobrynin, 2020-07-03:
Sorry, I made changes to the wrong file.

Forgiven, the access point has disappeared. But the connection disappeared again. Log:

01:28:45.630 -> >>>stack>>>
01:28:45.664 ->
01:28:45.664 -> ctx: cont
01:28:45.664 -> sp: 3ffffdb0 end: 3fffffc0 offset: 01a0
01:28:45.664 -> 3fffff50:  3ffee54c 3ffee554 3ffee7b0 402011b1
01:28:45.664 -> 3fffff60:  00000001 3ffe86a3 3ffee67c 3ffee8f8
01:28:45.664 -> 3fffff70:  3fffdad0 00000000 3ffee558 402011d6
01:28:45.664 -> 3fffff80:  3fffdad0 00000000 3ffee584 40202440
01:28:45.664 -> 3fffff90:  40201a9c feefeffe 4020e8cc 4020e8b4
01:28:45.664 -> 3fffffa0:  feefeffe feefeffe 3ffee8b8 4020cc6c
01:28:45.700 -> 3fffffb0:  feefeffe feefeffe 3ffe850c 40101145
01:28:45.700 -> <<<stack<<<
01:28:45.700 ->
01:28:45.700 ->  ets Jan  8 2013,rst cause:2, boot mode:(3,7)
01:28:45.700 ->
01:28:45.700 -> load 0x4010f000, len 3456, room 16
01:28:45.700 -> tail 0
01:28:45.700 -> chksum 0x84
01:28:45.700 -> csum 0x84
01:28:45.700 -> va5432625
01:28:45.700 -> ~ld
01:28:45.775 ->
01:28:45.775 -> MHI-AC-Ctrl starting
01:28:45.775 -> CPU frequency[Hz]=80000000
01:28:45.775 -> Attempting WiFi connection .......... connected to ilink2G, IP address: 192.168.252.215
01:28:50.020 -> OTA Ready
01:28:50.020 -> Attempting MQTT connection... connected
01:28:50.020 -> status=65 topic=connected payload=1
01:28:50.020 -> status=64 topic=RSSI payload=-63
01:28:50.020 -> Measure frequency for SCK, MOSI and MISO pin
01:28:51.009 -> status=68 value=3200
01:28:51.009 -> status=68 topic=fSCK payload=3200
01:28:51.009 -> status=69 value=500
01:28:51.043 -> status=69 topic=fMOSI payload=500
01:28:51.043 -> status=70 value=500
01:28:51.043 -> status=70 topic=fMISO payload=500
01:28:51.043 -> SCK frequency=3200Hz (expected: >3000Hz) o.k.
01:28:51.043 -> MOSI frequency=500Hz (expected: <SCK frequency) o.k.
01:28:51.043 -> MISO frequency=500Hz (expected: ~0Hz) out of range!
01:28:52.165 ->
01:28:52.165 -> Soft WDT reset

absalom-muc, 2020-07-04:
```
01:28:51.043 -> SCK frequency=3200Hz (expected: >3000Hz) o.k.
01:28:51.043 -> MOSI frequency=500Hz (expected: <SCK frequency) o.k.
01:28:51.043 -> MISO frequency=500Hz (expected: ~0Hz) out of range!
```
This time it is a short between MOSI and MISO.

coyote1, 2020-07-05:
Flashed all 3 ESPs with Changes lines, works fine now. No AP anymore

aleksandrdobrynin, 2020-07-06:
Yes, I did it too! WiFi points are no more. Thank.

And how can I make sure that the air conditioner sends its basic settings (operating mode, temperature, fan speed, shutters) every 10 seconds? I add air conditioning to Apple HomeKit through Node-RED and without receiving changes, it may turn out that the air conditioner works in one mode, and the Apple application will display another.

And yet, I have 5 fan speed modes - auto, 1,2, 3, 4. When I set auto mode, it says that this is the third speed, not auto. Can I somehow add support for auto mode?

absalom-muc, 2020-07-08:
> Yes, I did it too! WiFi points are no more. Thank.

Thanks to you and @coyote1 for your feedback

> And how can I make sure that the air conditioner sends its basic settings (operating mode, temperature, fan speed, shutters) every 10 seconds? I add air conditioning to Apple HomeKit through Node-RED and without receiving changes, it may turn out that the air conditioner works in one mode, and the Apple application will display another.

Better rethink your approach. An update of the AC status is visible on your MQTT broker. This event driven approach is usually the best approach because it is ensured that the latest status is always available. There should be no reason for regulary update the status when there is no change. If you still want to have the status resend w/o update you have to adapt the program.

> And yet, I have 5 fan speed modes - auto, 1, 2, 3, 4. When I set auto mode, it says that this is the third speed, not auto. Can I somehow add support for auto mode?

Please check section "Known Limitations" in the [Troubleshooting guide](https://github.com/absalom-muc/MHI-AC-Ctrl/blob/master/Troubleshooting.md#known-limitations)

aleksandrdobrynin, 2020-07-09:
Thank you very much for the help!!!
Added two air conditioners to HomeKIT thanks to your efforts.

L4RGER, 2020-11-16:
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

In 2.03 it’s still showing
#define SCK_PIN  14
#define MOSI_PIN 13

Do I need to swap this?

absalom-muc, 2020-11-17:
No, if you connect it according to [Hardware.md](https://github.com/absalom-muc/MHI-AC-Ctrl/blob/master/Hardware.md)
```
#define SCK_PIN  14
#define MOSI_PIN 13
```
is correct.

Closed 2020-07-09.

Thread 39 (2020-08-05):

Wiring btw AC and MHI-AC-Ctrl

drdoener, 2020-08-05:
Hi absalom,

thanks a lot for your great work. I´m about to solder the board and I´ve a question and input concerning the layout / wiring.
On the orange placards (/images/SRK-PCB.jpg and /images/SRK-PCB-RC.jpg) the order is GND,MISO,MOSI,SCL,+12V, beginning from 1.
This would mean 1 equals to GND.
On the pic below (AC_to_MHI-AC-Ctrl.png), PIN 1 equals to +12 V.
Please, could you explain the relationship between the pins on the boards and the information on the orange placards?

Thanks a lot,
Best,
drdoner

absalom-muc, 2020-08-05:
Thank you @drdoener - you found a bug in AC_to_MHI-AC-Ctrl.png. There is the numbering of the AC connector wrong, it should be
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
But the photos (incl. the orange placards in [SRK-PCB.jpg](../tree/master/images/SRK-PCB.jpg) and [SRK-PCB-RC.jpg](../tree/master/images/SRK-PCB-RC.jpg)) and the PCB show still the correct signal names.
I will update AC_to_MHI-AC-Ctrl.png accordingly.

absalom-muc, 2020-08-09:
corrected [here](https://github.com/absalom-muc/MHI-AC-Ctrl/blob/master/images/AC_to_MHI-AC-Ctrl.png)

drdoener, 2020-08-15:
Hi,
fine, looks better now.
As soon as I will have installed the board, you receive feedback for my SRK 35 ZSX-W.

Greetz

Closed 2020-08-09.

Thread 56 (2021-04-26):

PCB improvement for SRK-ZSX serie

DYLaKo, 2021-04-26:
First of all: Excellent project & development. I have 2 MHI airco's and both are equipped with your solution and it works great!

Last week I have provided one of my ordered PCB's to someone who also wanted to build an airco controller based on your software. After installation, he provided me with some feedback for PCB improvement, since he had to modify the PCB to make it fit in his airco.

The airco used is one from the Mitsubishi Heavi Industries SRK-ZSX series. Next to the connector on the mainboard of the airco, there is a big elco which prevents the PCB to be fitted in the connector. This could offcourse be solved with an extension cable, but he removed a small piece of the PCB to make it fit.

Photos are attached for your reference, maybe you can use them to further improve your PCB design.

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

absalom-muc, 2021-04-28:
Thank you for the hint @DYLaKo, I will add a link to this issue to the HW description and consider it for a future update of the PCB.

absalom-muc, 2022-01-20:
The [supported units list](https://github.com/absalom-muc/MHI-AC-Ctrl#prerequisites) gives you only the infromation if MHI-AC-Ctrl is basically supported by a unit, e.g. related to the SPI protocol and the electrical connection. The feature for plug-in MHI-AC-Ctrl directly into the AC without using a cable is only since the last PCB update (Sept 2021). And I'm not sure when we received the confirmation that SRK ZS-W units work with MHI-AC-Ctrl. Before or after Sept 2021. So worst case there could be a collision. And I'm also not sure if there is enough space for an extension.
Let's keep finger crossed.

DYLaKo, 2022-01-20:
I have 2 SRK35ZS-W units in my house, running like a charm with the MHI-AC-Ctrl board, so that works. :)

birarda, 2022-01-21:
> The [supported units list](https://github.com/absalom-muc/MHI-AC-Ctrl#prerequisites) gives you only the infromation if MHI-AC-Ctrl is basically supported by a unit, e.g. related to the SPI protocol and the electrical connection. The feature for plug-in MHI-AC-Ctrl directly into the AC without using a cable is only since the last PCB update (Sept 2021). And I'm not sure when we received the confirmation that SRK ZS-W units work with MHI-AC-Ctrl. Before or after Sept 2021. So worst case there could be a collision. And I'm also not sure if there is enough space for an extension. Let's keep finger crossed.

@absalom-muc thanks for the info!

In this response you mention a Sept 2021 PCB update but it looks like the latest in the repo is Jan 2021?

absalom-muc, 2022-01-21:
Sept 2021 is the date when the new PCB was released in v2.2. Introduced was it in Jan 2021. If someone trusted the "draft" version in the repo the Jan is the deadline, for a release version the September.

johnneerdael, 2023-08-08:
Have you found any instructions ANYWHERE on how to access the PCB?

Closed 2021-04-28.

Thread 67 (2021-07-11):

"SELF CLEAN operation" to prevent mold

al400k, 2021-07-11:
Hello,
is it possible to switch on Aircon in "SELF CLEAN operation" with MHI-AC-Ctrl?

SELF CLEAN operation should be run after AUTO, COOL and DRY operation to remove the moisture from inside of the indoor unit andcontrol the growth of mold and bacteria.
The indoor unit fan runs for about two hours in SELF CLEAN operation
(can be switched on using settings on remote control)

See mitsubishi heavy manual that explains that function:
https://www.mhi-mth.co.jp/en/products/pdf/rlf012a201_english.pdf

When this function is swithed on, i see this data in MQTT Explorer:

MHI-AC-Ctrl-1
connected = 1
RSSI = -79
fSCK = 3200
fMOSI = 500
fMISO = 0
Mode = fan_only
Power = on
Fan = 1
Vanes = ?
Troom = 30.75
Tsetpoint = 24
Errorcode = 0
OpData
	Mode = fan_only
	Tsetpoint = 24
	RETURN-AIR = 31.00
	THI-R1 = 27
	IU-FANSPEED = 1
	TOTAL-IU-RUN = 4600
	OUTDOOR = 34.50
	THI-R2 = 71
	COMP = 0.00
	THO-R1 = 19
	TD = 43
	THI-R3 = 27
	CT = 0.00
	PROTECTION-NO = 0
	OU-FANSPEED = 0
	DEFROST = off
	TOTAL-COMP-RUN = 3800
	OU-EEV1 = 250
	TDSH = 2
	cmd_received = o.k.

in this mode:
	Vanes are closed,
	indoor fan speed- very slow (slower than minimum on cool mode)
	OUTDOOR unit -is swithed off

thank you.

absalom-muc, 2021-07-13:
Activating "SELF CLEAN operation" with MHI-AC-Ctrl is not supported because I don't know if the self-clean command is supported via the [SPI](https://github.com/absalom-muc/MHI-AC-Ctrl/blob/master/SPI.md#spi-bus) bus and - if yes - which SPI command it is. Currently I have no plans to analyze it.

drdoener, 2021-07-26:
Hi,
for you info: I subsituted this function by a short script in node red.
Shut down with SELF CLEAN: Via MHI-AC-Ctrl immediately to FAN mode, after 2 hours via MHI-AC-Ctrol-> OFF.

al400k, 2021-07-26:
thanks,  i did the same with script, but "SELF CLEAN" works little different because vanes are closed. I thought there is the way to send command to MHI (fan=1(nomal min mode=2),vanes=0) but it is not so easy.

drdoener, 2021-08-06:
Hi,
that sounds interesting. I **assumed** that there is no difference between SELF CLEAN and the ordinary FAN mode.
How have you figuered it out? I can´t see the difference.
As an example, I dumped the values via MHI-Ctrl and copied those into the attached xls to compare the values.
[MHI_SELF_CLEAN.xlsx](https://github.com/absalom-muc/MHI-AC-Ctrl/files/6944299/MHI_SELF_CLEAN.xlsx)

And here are two pics:
The IU in FAN mode:
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

The IU in SELF CLEAN mode:
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

Thanks & greets,
drdoener

al400k, 2021-08-06:
Hello,very strange, your data shows mqtt.0.MHI-AC-Ctrl.OpData.IU-FANSPEED=2 like normal minimum fan speed.
 are you sure that you push "SELF CLEAN operation" and not the "ALLERGEN CLEAR operation"?
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

drdoener, 2021-08-06:
Hi,
really sure. This mode is set in my RC and the timer on RC display runs down when I press "ON/OFF)
I never used the "ALLERGEN CLEAR operation". Just tried it out. After pressing the "Alien Button" on the RC, the Unit went ON und shut down after approx. 1 min.

al400k, 2021-08-06:
Probably depends of model, mine is: SRK25ZS-W and SRK40HG-S both working with closed Vanes and Fan=1 in Self clean mode. May i know your model?

drdoener, 2021-08-06:
It´s MHI SRK 35 ZSX - W

drdoener, 2021-08-10:
Hi,
disregard everything I wrote above.
I had a huge bug in my scripts, resulting in triggering the normal FAN mode when I switched on SELF CLEAN via RC.
This means: Same at my device, if I switch on SELF CLEAN, the vanes become closed and **IU-FANSPEED = 2** for 2 hours.

Further info:
Prior MHI-AC-Ctrl, I used the original WLAN Adapter via intensis cloud.
As far as I remember (I`m very sure), as well the SELF CLEAN function didn´t work via the WLAN Adapter.
That leads me to expect, that the SELF CLEAN mode is only working via the RC.

Sorry for the misleading information, I´ll delete my posts above if you agree.

al400k, 2021-08-10:
thank you for sharing, now everything is clear:) We still don't have working solution for "SELF CLEAN" mode except Fan mode with script.

kARTechnology, 2021-10-31:
I

>
>
> thank you for sharing, now everything is clear:) We still don't have working solution for "SELF CLEAN" mode except Fan mode with script.

Is it possible to close the vanes fully with mhi-ac-ctrl? and also we see the power led blinking (3sec on/1sec off) is present which means there is some mode to activate it.

kARTechnology, 2022-01-20:
i would like to change the action on the off command to

1. set temp to 30deg
2. fan at 2 speed
3. run for 2 hrs on a timer and then turn off
4. and reset the temp to what value it was set before(either by remote too, so how to read the current value from the esp/ac before i change it to 30)

if the ac is turned on, the running timer to turn off after 2 hrs is cancelled.

this looks the workaround but without it my ac starts to stink. even though we tried analyzing the raw values thru the mhi-trace, unable to fund out. there might be some other setting bit to set but without a wired RC with self clean, cant explore

absalom-muc, 2022-06-16:
closed since there was no update for a long time. Please feel free to re-open in case of follow-up topics.

Closed 2022-06-16.

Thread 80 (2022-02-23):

mhi_ac_ctrl_core.loop error: -3

andi377, 2022-02-23:
I described the wemos with version v2.5R21. The Wemos is available in the WiFi and also in the MQTT server in the iobroker. The data points have been created, but they are not updated. Where I have now activated the serial monitor in the IDE comes

18:01:26.323 -> mhi_ac_ctrl_core.loop error: -3
18:01:26.423 -> mhi_ac_ctrl_core.loop error: -3
18:01:26.523 -> mhi_ac_ctrl_core.loop error: -3
18:01:26.624 -> mhi_ac_ctrl_core.loop error: -3
18:01:26.724 -> mhi_ac_ctrl_core.loop error: -3

Where is my problem, unfortunately I can't get any further

absalom-muc, 2022-02-23:
This message indicates a time out condition for the SCK pin. Please provide the debug outputs from the beginning after reset is released. There should be messages related to the pins SCK, MISO and MOSI, so that you can see if the pins are connected in the right way. (I assume SCK is not connected, but let's see)

andi377, 2022-02-24:
Ifound the problem, it was a hardware error, now everything works.
Thanks for your help

Is there also a possibility to integrate a ceiling device (FDTC25VF) ?

andi377, 2022-02-25:
Today I wanted to rewrite the wemos, only the host name was adjusted. After that, the control no longer works.

The  debugfile is attach

Here is the problem?

[debug.txt](https://github.com/absalom-muc/MHI-AC-Ctrl/files/8142606/debug.txt)
-

andi377, 2022-02-26:
yes it the original HW setup for MHI-AC-Ctrl).
I just changed the hostname.
With one pcb I have the plug directly with the second one with a cable length of approx. 15 cm. I measured the pcb electrically. Only the level converter could be the problem
.
In the MQTT server I can see that the time stamp for MISO, MOSI and SCK changes when the Wemos is boote
[debug2.txt](https://github.com/absalom-muc/MHI-AC-Ctrl/files/8147493/debug2.txt)
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
d

absalom-muc, 2022-02-28:
The frequency values for SCK, MOSI and MISO during boot look perfect and I can see in your debug file that it works without problems for 20 seconds. I have no idea what happens after these 20 seconds. Maybe the esp8266 should be replaced, but that's just a guess.

andi377, 2022-03-03:
oday I tried it again with new hardware,
one version worked, one didn't.
When it worked, the whole thing only went for a certain amount of time. Then the wemos was no longer visible in the WLAN. When checked, the wemos was very warm. What temperature is normal there?
I'm slowly running out of ideas on how to get this to work.

absalom-muc, 2022-03-12:
> oday I tried it again with new hardware, one version worked, one didn't. When it worked, the whole thing only went for a certain amount of time. Then the wemos was no longer visible in the WLAN. When checked, the wemos was very warm. What temperature is normal there? I'm slowly running out of ideas on how to get this to work.

I don't know "normal temperature".
Not sure what you mean with "one version worked, one didn't". Have you exchanged the Wemos of the boards? So not clear if you identified a board not working or a Wemos not working.

absalom-muc, 2022-06-05:
Since there was no update since long time, I assume this issue is resolved. In case of further questions please don't hesitate to re-open it.

Closed 2022-06-05.

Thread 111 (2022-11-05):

Wrong assembly orientation of X1 in KiCad PCB layout

absalom-muc, 2022-11-05:
@oliv3r : Not sure if you have seen my question in your [KiCad pull request](https://github.com/absalom-muc/MHI-AC-Ctrl/pull/106).

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

 I believe the orientation of X1 is not correct and should be rotated by 180°. Could you recheck?

oliv3r, 2022-11-08:
Hey @absalom-muc,

don't think so? I took this picture of you as reference:
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 obviously this is the male mounted at the bottom, but the 'tabs' are pointing the same way, board-inside. I agree that the actual connector is on the wrong side and uses the wrong model :p but that shouldn't matter?

Looking at the pcblayout:
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
GND is pin 1 facing the 'middle' +12V is the bottom one facing the edge. As I 'traced' your PCB, I'm fairly confident that the pin orientation is identical to yours?

So pins are GND, MISO, MOSI, CLK, 12V which is exactly what you had as well (though no silkscreen helpers on those labels :p)

oliv3r, 2022-11-09:
Well right now the connector is just a render, and the pinout matches exactly that of a female (the housing is male?) on the bottom. So if you'd solder this board, and put the correct connector on the bottom with the edges facing inwards, your fine.

If I 'flip' the connector to the bottom, it _looks_ like this:
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

But regardless, the pinout stays completly _identical_. So in the end, it's just how the component is being rendered. I do agree it makes logically more sense :p to at least show it exactly as you'd have to assemble it with extension cable type A). But I'm sure excention cable type B exists just as much, which makes it work with the current rendering. Caveat emptor I would say. I'll open a MR with the correct _rendering_ of the connector. But note, that ultimately, the PCB gerber is still the same as before!

oliv3r, 2022-11-09:
https://github.com/absalom-muc/MHI-AC-Ctrl/pull/113

absalom-muc, 2022-11-12:
I understand that the gerber is unchanged and that only the rendering is affected. But I've also seen in the last years that for unexperienced users this minor "inconsistency" creates confusion. Would it be possible to make a female connector and to rotate it by 180°? Then we are consistent to the existing assembly pictures. Thank you.

oliv3r, 2022-11-16:
> Then we are consistent to the existing assembly pictures
I'd have to do some 3D modelling to create that connector :), which is not something I've done before much. So that's certainly a challenge :) So #113 puts it on the correct side, the 180degree rotation would then only be applicable because it's a female header. I'll see what I can do on those rendering skills. We could also omit the render of the connector for the time being :p

absalom-muc, 2022-11-17:
Thank you for your efforts @oliv3r

Closed 2023-08-28.

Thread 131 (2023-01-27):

Get Power usage

HpNoTiQ56, 2023-01-27:
Hi,
I'm trying to monitor power usage (W,KWh or A) but the only value I could gather is TD and CT in A.

First, are TD and CT intensities in A? I've monitored them but TD is about 45 thus can't be in A and CT is too low I think!

Could you tell me if it could be done?

thanks,

dennistd4, 2023-01-28:
The CT value is the right one. Multiply it with your actual voltage and you will have the power in watts. Here it is slightly higher (about 10-40 watt) than the power measured by a Shelly EM, but maybe it's because of the length of the power cable (I use the voltage measured by the Shelly for the calculation).

buennerbernd, 2023-01-28:
I‘m using CT * 230 to calculate the current electrical power.
If my devices are of, this jumps between 0 and 62W.
During heating I have peaks up to 1600W but normal are 500 - 900W.
For power consumption I‘m calculating the integral over the time an get reasonable results.

absalom-muc, 2023-01-28:
btw: In the documentaion and in the source code the TD unit is wrong, TD is the Discharge Pipe Temperature  [°C]

buennerbernd, 2023-01-28:
In my installation I have 3 indoor units and one outdoor unit. All devices are powered by the outdoor unit. That are 4 devices in stand-by plus 3 esps.
The CT is a value of the outdoor unit for the whole installation. All 3 ESPs are reporting consistent values. Perhaps 0,27A is the minimum step that can be reported.
I will calculate the power consumption in stand-by for the coming hour…

absalom-muc, 2023-01-28:
o.k. makes sense. The resolution of CT is 14/51A=0,2745A

buennerbernd, 2023-01-28:
So, now I have checked after an hour. My calculated consumption is 0.0133kWh.
The average power consumption of my whole installation in stand-by is 13.3 Watt.

@absalom-muc Could you please explain 14/51?

absalom-muc, 2023-01-28:
> @absalom-muc Could you please explain 14/51?

This is the factor to calculate the current from the data byte value, see [here](https://github.com/absalom-muc/MHI-AC-Trace/blob/main/SPI.md#29-ct-a) (just added)

HpNoTiQ56, 2023-01-28:
Thanks a lot for your help and clarification. I'm now ready to follow power consumption !
I didn't think that I would make such reactions!
Keep up the good work !
I Close the issue !

Closed 2023-01-28.

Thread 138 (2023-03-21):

Frage: wie bekomme ich den Deckel ab?

ymca72, 2023-03-21:
Hallo,
Vorweg  kein Bug sondern eine Frage:
Ich beschäftige mich gerade sehr intensiv mit deinem Projekt und habe heute eines meiner Splitgeräte geöffnet um mir mal die Leiterplatte anzuschauen um zu wissen was mich erwartet.
Ich bin aber daran gescheitert, die Abdeckung der Leiterplatte zu öffnen.  Ich wollte am Ende keine rohe Gewalt anwenden um dran zu kommen. Ich denke mal, das es Abdeckung auf der rechten Seite ist wo sehr viel Blech zur Abschirmung drauf ist.  Gibt es da einen Trick die zu öffnen?
Da mein Split sehr dicht rechts an der Wand sitzt, sieht man es kaum. Und das zweite Split sitzt sehr hoch, deswegen habe ich erstmal an diesem üben wollen.

Übrigens,  ich habe 20 PCB bestellt (5 oder 20 hat keinen großen Unterschied gemacht) und würde dann auch welche zum Selbstkostenpreis abgeben.

Danke für die Realisierung des Projektes und Support .

ymca72, 2023-03-21:
Not really. It's more for desinfect and clean. I need advice for open the electric compartment. I have no idea how to open it. The AC is an 2016 zr-35m.

dennistd4, 2023-03-22:
You have to follow that video till 1:34. Then you see a screw on the right side. Unscrew that screw, remove the cover it holds and you will have access to the mainboard.

ymca72, 2023-03-22:
Right , i See in last 24h a lot of YouTube-Videos, that the Single screw remove all. Bit my setup is quite different like that shown in that Videos. I See a lot of screws, a lot of Plastik clips and think in my compartment is the pcb rotated 180° against what i see in YouTube.  This is the reason why i ask.

trombose009, 2023-03-25:
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

Ich hätte Interesse: svenhandloegten@yahoo.de
Melde dich und sag mir gern wie weit du damit gekommen bist

ymca72, 2023-03-26:
Hi,
i solved the issue to open the electronic compartment but it needs more than one screw in my case (additional 3 screws) and the PCB is indeed 180° reverse than the newer modelsfrom  MHI. Anyway, so I´m now little smarter. Thanks to my AC technican for support.
For all with older models: You must lose the srew on the top, downside and on the left side of the compartment. Then you dismantle the cover in front with by slightly lifting the plastic clips on the left and on the top. If the cover away, you can silde carefully the Main-PCB out of AC. Then you see the needed conector.  This is a little nightmare to dismantle all. Also you must cut one of the cable tie around the ferrite core. The second in this area is reuseable.
To assemble goes just the same only in reverse. Pay attention to all cables when assembling, that they come back into the correct bushings.

Now I waiting of delivery of all needed parts and then again reopen the AC and install the control. Keeps fingers cross that all will work on the first try.

glsf91, 2023-03-28:
@ymca72 Please close the item if your issue is solved.

ymca72, 2023-03-28:
Thanks for Support. It's sovled. Discription above.

Cheers

Closed 2023-03-28.

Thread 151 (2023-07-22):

MISO not zero during startup in software versions 2 and above

NickyNL, 2023-07-22:
Name of my AC: MHI SRK50ZJX-S1
Used MHI-AC-Ctrl HW: 2.2
Used MHI-AC-Ctrl SW: 2.6

I have a strange issue. I have ordered the latest hardware pcb, programmed a ESP with the latest software, and it didn`t work. The ESP keeps getting rebooted due to a too high MISO frequency.
See the serial output here;
Starting MHI-AC-Ctrl v2.6
CPU frequency[Hz]=160000000
ESP.getCoreVersion()=3.1.2
ESP.getSdkVersion()=2.2.2-dev(38a443e)
ESP.checkFlashCRC()=1
Measure frequency for SCK, MOSI and MISO pin
SCK frequency=2400Hz (expected: >3000Hz) out of range!
MOSI frequency=300Hz (expected: <SCK frequency) o.k.
MISO frequency=165Hz (expected: ~0Hz) out of range!

I have tried the following to solve this;
- Try different Wemos D1 versions (standard mini and the PRO), both give the same issue
- Try new level shifters, all the same issue
- Downgrade to software version 2.0, same issue

Lastly I downgraded even ot 1.4, and that seems to at least work.
Now I do get data via MQTT, and the MISO frequency seems to be roughly zero as it should.
I do get some checksum errors, but this at least works.
See the serial output here;
MHI-AC-Ctrl starting
Measure frequency for SCK, MOSI and MISO pin
SCK frequency=2594Hz (expected: >3000Hz) out of range!
MOSI frequency=315Hz (expected: <SCK frequency) o.k.
MISO frequency=0Hz (expected: ~0Hz) o.k.
Found 0 DS18xxx family devices.
Unable to find address for Device 0
Device 0 Address: 0000000000000000
........ connected to xxx, IP address: xxx
OTA Ready, IP address: xxx
Attempting MQTT connection...connected
Wrong MOSI signature: 0x6C 0x80 0x04 or checksum received!

So the main question boils down to, how can the measured MISO frequency be higher when I use the latest software versions?

It`s nice to have it working, but keeping up with the newer versions would be preferrable.

NickyNL, 2023-07-23:
I have tried two more things;

- With software version 2.6, just for testing i disconnected only the MISO pin between the pcb and the airco.
  Doing this resulted in a MISO readout of zero,  a voltage on the MISO pin on the airco side of zero,
  And the data worked only partially. It only send out data from the indoor unit as far as I could see.
- In software version 2.6, I commented out the while(1) so the software wouldn`t reboot, to see if for example MISO would later
  on become zero.
  After this the program seems to work and I get all the data. Also sending commands works. However the MISO does not go
  to zero.
  And also the serial output is clogging with "mhi_ac_ctrl_core.loop error: -4"

glsf91, 2023-07-23:
Removing the while(1) can damage the ac or your board as mentioned in Troubleshooting.md
There is no difference in measuring the pins in 1.4 and 2.6.
If the board is connected to your ac with a cable, maybe it is picking up some noise.

absalom-muc, 2023-07-23:
And please re-check your PCB if there is a short between MISO signal and another signal, maybe a bridge due to poor PCB quality or by solder. I suggest a loupe.

NickyNL, 2023-07-23:
Thanks for your responses.
Yes I did read the disclaimer about damaging, I knew it was a bit risky.

Also I did look at #22 which is about the wrong level shifter,
I also looked at #26 and #84, but none seems to display exact behavior to what I am seeing.

So picking up some noise would sound reasonable... However, it does not explain the difference in 1.4 and 2.6.

Also a fault on the PCB would not explain that difference if you ask me.

I have though measured by multimeter,
And the only resistive values I saw where 10k/20k due to the pull/up/down resistors on the level shifter.
Measureable between ground and SCK/MOSI/MISO is some 10k/20k, and between SCK/MOSI/MISO also some 10k/20k.
Between VCC(12V) and SCK/MOSI/MISO it`s all measuring mega ohms.

I do have oscilliscopes and stuff to measure things, but unsure at the moment of what to measure.

glsf91, 2023-07-23:
If you have a logic analyser this will help.
Otherwise maybe with the oscilloscoop you can monitor the behavior of the MISO line at the board without the esp. It should be steady 0 Volt.
Otherwise strip the program to only measure the frequency repeatly and look with the oscilloscoop.

NickyNL, 2023-07-23:
I don`t have a logic analyser readily available.
When I have some more time I`ll sure hookup a scope to at least look what the signals look like.

I just measured with my multimeter, the MISO pin reads a steady 2,6V when the PCB is connected to the airco. Even without the ESP on it. Without the PCB so measuring just the airco pins it the MISO pin reads 0V.
So at least this voltage must be coming from the on the PCB itself (including level shifter).

Am wondering now if it is due to the resistances on the level shifter.
So measuring with my scope I should be able te verify if it is a voltage diveded copy of SCK and/or MOSI.
Would suspect SCK since that is 5V.
(Although I am wondering why nobody else had the issue)
These are the level shifters I`ve used; https://nl.aliexpress.com/item/1972789887.html

I`ll update next when I`ve had time to hook up a scope!

SmOeL-swdev, 2023-08-04:
@NickyNL have you managed to solve the issue? I was facing the same issue. I have made a complete different hardware version though (manually soldered with stuff I had laying arround).
Initially I used the same pinning as described in the repository.
I solved the issue by changing the MISO pin to GPIO16 (Seems like internal crosstalk of the ESP).
I have created al sorts of filtering initially that didn't help, changing pin did. You might need some changing when using the PCB version.

Groeten

NickyNL, 2023-08-04:
@SmOeL-swdev thanks for the tip! Will definitely try swapping to that pin soon.

It also was a good trigger that I still had to do something.
As it is "working" as is, it sometimes gets forgotten.

So, hereby at least some captures with a oscilloscope;
Measured straight on the pins on the pcb coming from the AC.
With the ESP on the pcb as well.

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

NickyNL, 2023-08-05:
I`ve given your trick a try, and it works!
Swapped MISO from GPIO12 to GPIO16 and now the MISO reading remains 0!
Reimplementing the MISO check on boot and everything is okay now.

Cudos to @SmOeL-swdev!
Of course I live and work in probably the same country, the Netherlands :)

Closed 2023-08-05.

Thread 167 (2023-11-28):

KiCAD: J1 Connector pinout is wrong

AlexCPU, 2023-11-28:
The KiCAD design was "fixed" in #155 to model a female connector correctly on the reverse of the board, which involved flipping the connector.  However the schematic wasn't updated, so the PCB layout has the pins defined incorrectly:
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
You can see the unconnected nets, and the fact that different named nets are connected to the pins (easiest to see on the GND and +12V pins).
I'll see if I can raise a PR for this.

Unrelated question: I'm making a new version of the board with an ESP32-C3 integrated (i.e. no extra D1 Mini) with mostly SMD parts, any preference in the repo where to put it?

glsf91, 2023-11-28:
That epshome fork is using a part of the mhi-ac-ctrl code.
I have also tried with that esphome fork without success.
So I suggest you first trying to get this up and running without errors before making a new version of the board :-)

oliv3r, 2024-02-07:
Sorry for not noticing this !! Thanks @AlexCPU for the fix :)

Closed 2024-01-08.

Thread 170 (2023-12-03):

Can't send commands

wissenj, 2023-12-03:
I have installed version 2.8 with MQTT PubSubCLient v.2.7. D1 mini is soldered to the PCB Board which I manufactured by JLCPCB. This is mounted on the Unit SRK 50ZS-W. Via MQTT I can receive all data successfully. And I can send commands via MQTT, e.g. MHI-AC-Ctrl/set/Power which then get's confirmed by an MHI-AC-Ctrl/cmd_received o.k.

However, all send commands are not executed in any way. Seems they get lost on the way to the SRK unit.

I have checked the troubleshooting guide, but can't find the issue. My serial boot log:
```
Measure frequency for SCK, MOSI and MISO pin
SCK frequency=3200Hz (expected: >3000Hz) o.k.
MOSI frequency=560Hz (expected: <SCK frequency) o.k.
MISO frequency=0Hz (expected: ~0Hz) o.k.
OTA Ready
```
Also looks OK for me? Can someone give me a hint what to check next? Thank you very much!

absalom-muc, 2023-12-04:
It seems that the problem is related to the hardware.

- First I would check the PCB with a magnifying glass to ensure there is no bad solder joint (in most cases this is the problem).
- Please check if the Level Shifter is the right one.
- Can you check if the MISO conncetion from PCB to the jack at the end of the cable is o.k.?
- Do you have electronic measurement equipment? E.g. an oscilloscope?
- Since it is simple to test you could change the ESP8266

btw: I appreciate the way how you described your problem - very clean and structured 👍

wissenj, 2023-12-07:
Hey absalom-muc,

Thank you for the nice help and the hints. My level shifter used had all necessary connections but wasn't fully bi-directional on all foru channels! And this was the reason. Maybe this can be added to the troubleshoot list or to the hardware description.

Thank you very much for the great project, looking forward now using it.

Closed 2023-12-08.

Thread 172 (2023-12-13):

Wrong runtime counters

KoelnSolar, 2023-12-13:
Hi there,

great job !

Since yesterday my SRK35-ZSX-WB with SRC35-ZSX-W is running with Wemos-mini. I just added an LED to reduce power of 12,5V(measured) to a voltage beneath 12V(3.3 voltage regulator has max. voltage 12V). Level shifting MOSI/SCLK is done by voltage dividers 825/2200. USE_EXTENDED_FRAME_SIZE is enabled. Version MHI-AC-Ctrl is 2.8.

OpData_TOTAL-IU-RUN didn't change so far and still shows 100(value seems to be 1)
OpData_TOTAL-COMP-RUN was 100(value seems to be 1) and changed now the first time to 200(last power off was yesterday 4 p.m.)

further issues:
OpData_CT seems to be calculated wrong(at least 0.5 higher than measured consumption). Maybe it is an issue that no wave shift Phi is given ?
Edit: e.g. CT shows 1.1; calculated power by multiplying 230V results in 253W, but power is measured with 140-200 W

OpData_OUTDOOR is nearly 1 degree lower than temperature measured with DS18B20

setting fan speed doesn't work for 2 and 3. setting 4 results in level 7. Auto and level 5,6,7 as settings are missing(checked against program code).

I'm missing settings for "Hi/Lo"(boost/eco mode), silent mode....

Any idea of calculating thermal energy and COP ?

I'm using FHEM as MQTT Server and have a lot of possibilities to compare data against measurements, program things...... Don't hesitate to contact me if you need further informations or assistance.

Regards, Markus

glsf91, 2023-12-13:
OpData_CT:
We cannot change this, this is wat the AC provides. The voltage is not always 230V, so multiplying always with 230V is not right. Better to multiply with voltage from P1 meter measured (on the right phase).

OpData_OUTDOOR:
We cannot change this, this is wat the AC measures and provides.

Fan speed:
level 5,6,7 don't exists. Only 1-4 and Auto like on the remote control. The levels 1-8 are for OpDate/IU-Fanspeed and are different from topic Fan.
So if you set Fan to 3, the IU-Fanspeed will normally become 6. BUT the AC can change this to lower values.
So if you set Fan, look into the topic Fan and you will see the same value (and means it is working). Same for Auto,

"Hi/Lo"(boost/eco mode), silent mode...." is not possible.

KoelnSolar, 2023-12-13:
Thanks for quick reply.

> The voltage is not always 230V, so multiplying always with 230V is not right. Better to multiply with voltage from P1 meter measured (on the right phase).

Thats true, but multiplying 230V is OK to get nearly the power. 25% difference is caused by wrong CT, maybe missing wave shift.

> We cannot change this, this is wat the AC provides.

The value is not provided by AC. It is calculated `dtostrf(value * 14 / 51.0f, 0, 2, strtmp)`

> OpData_OUTDOOR:
We cannot change this, this is wat the AC measures and provides.

Is calculated too. `dtostrf((value - 94) * 0.25f, 0, 2, strtmp)`

> "Hi/Lo"(boost/eco mode), silent mode...." is not possible.

Currently in software and not yet evaluated, but should be supported by SPI, I think.

glsf91, 2023-12-13:
Of course they are calculated but value is coming from AC en calculations are right. And yes this can differ from own measured values.

> Currently in software and not yet evaluated, but should be supported by SPI, I think.

Is not supported by SPI.

KoelnSolar, 2023-12-13:
How do you know the right formulas for calculations ?

At lunch time I made a test to check directly power after each change of AC-CT. As you can see the differences are not that big. Maybe just time shifted.
But in low power mode CT didn't change since 4:24 p.m . Real power is 20% less. As you can see, I checked against power meter and grid.
I'm wondering that I could see only this 1.1. And there was only one lower value 0.82. Is it similar with your ACs ?
It seems that CT is only a kind of calculation and not really measured.

[AC power.pdf](https://github.com/absalom-muc/MHI-AC-Ctrl/files/13664164/AC.power.pdf)

glsf91, 2023-12-13:
> How do you know the right formulas for calculations ?

Because in the past they are compared with other devices connected with the AC and showing the values.

> Is it similar with your ACs ?

I don't measure the current with a power meter so cannot compare with CT.
And I do not calculate power usage with CT so can also not compare with power usage from powermeter.
It will be always preferable to use the power measured from your powermeter if you have one. It will be more accurate.

glsf91, 2023-12-21:
I think we can close this one

KoelnSolar, 2023-12-21:
Why did you close the issue ?
Was there any answer regarding the runtime counters ?

glsf91, 2023-12-21:
Because there was no activity anymore.
> Was there any answer regarding the runtime counters ?

It is in the last answer. Calculations are based (in the past) on a MHI device which was also displaying these values.

Closed 2023-12-21.

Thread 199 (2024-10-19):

SRR series not working

Dduck112, 2024-10-19:
Hi all, I orders the board on Nodo-Shop and included the soldering service.
I have a MHI srr35zs-w with the required CNS connection, 5 pins.
Installed the ESPHome code and read out the log wireless while on usb power.
Turned the power from the airco down, and connected the board. Turned it back on, but the ESP did not get powered.
I tried pressing the reset button and watched for the little blue light, but it did not light up.
(when I have the ESP connected with a usb power, it does light up.)
So I ques the SRR are not supported :(  (I did not dare to power it with a usb while connected too the airco)

glsf91, 2024-10-20:
Check if the TSR2450 SUPPLIES 5V to the wemos. If not check if the AC supplies 12V to the TSR

Dduck112, 2024-10-20:
Hi,
I get 12.3V on the TSR and 4.9 to the wemos.
So no idea why it does not boot up at all.

fonske, 2024-10-20:
Does your esp still work on USB source only? Or is it dead on usb?

I see that the pcb from node-shop is missing the larger capacitor as in the original design?

Dduck112, 2024-10-20:
Hi,  I disconnected the board from the airco, and powered it using a 12v power supply, the wemos did not turn on...
I tried a other wemos, and it did  turn on. I flashed the bin downloaded from ESPhome in HA to the new board and added the code from the examle to the main code. tried to connect with the wireless log, and it worked. Connected it back to the airco and it is powering the wemos :)  I can read the log from within HA... see below, But all entities are unavailable.

side note, it is my first ESPhome node. So not much experience here.

Log:
INFO ESPHome 2024.10.0
INFO Reading configuration /config/esphome/espairco.yaml...
INFO Starting log output from 192.168.2.40 using esphome API
INFO Successfully connected to espairco @ 192.168.2.40 in 0.063s
INFO Successful handshake with espairco @ 192.168.2.40 in 0.396s
[14:09:35][I][app:100]: ESPHome version 2024.10.0 compiled on Oct 20 2024, 13:51:24
[14:09:35][W][component:237]: Component MhiAcCtrl took a long time for an operation (53 ms).
[14:09:35][W][component:238]: Components should block for at most 30 ms.
[14:09:36][W][component:237]: Component MhiAcCtrl took a long time for an operation (54 ms).
[14:09:36][W][component:238]: Components should block for at most 30 ms.
[14:09:36][W][component:237]: Component MhiAcCtrl took a long time for an operation (52 ms).
[14:09:36][W][component:238]: Components should block for at most 30 ms.
[14:09:36][W][component:237]: Component MhiAcCtrl took a long time for an operation (53 ms).
[14:09:36][W][component:238]: Components should block for at most 30 ms.
[14:09:36][W][component:237]: Component MhiAcCtrl took a long time for an operation (52 ms).
[14:09:36][W][component:238]: Components should block for at most 30 ms.
[14:09:36][W][component:237]: Component MhiAcCtrl took a long time for an operation (52 ms).
[14:09:36][W][component:238]: Components should block for at most 30 ms.
[14:09:37][W][component:237]: Component MhiAcCtrl took a long time for an operation (51 ms).
[14:09:37][W][component:238]: Components should block for at most 30 ms.
### This go's on and on

fonske, 2024-10-20:
you can use this in your code
```
logger:
  baud_rate: 0
  logs:
    esp32.preferences: DEBUG
    sensor: DEBUG
    text_sensor: DEBUG
    switch: DEBUG
    button: DEBUG
    number: DEBUG
    climate: DEBUG
    component: ERROR
```

glsf91, 2024-10-20:
Please continue in the repo with this issue where you got the mhi esphome sw.
They can support esphome issues better there. I will close this one.

Closed 2024-10-20.

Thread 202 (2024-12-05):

Manufacturer Wifi units wiring question

ThomasHFWright, 2024-12-05:
Name of my AC: SRK35ZS-WF
Used MHI-AC-Ctrl HW: Nodo shop ESPAC Wifi interface MHI-AC-Ctrl +WeMos D1 Mini (https://www.nodo-shop.nl/en/our-products/228-espac-wifi-mitsubishi-heavy-industries-interface.html)
Used MHI-AC-Ctrl SW: N/A

**Describe the bug**
Has anyone tested the cable that connects to the manufacturer wifi units to check the orientation of the cables are the same as expected by the hardware design in this repo?
My installer didn't have access to non-wifi units so just gave me a discount to get the same price on the units with wifi units pre-installed.
They have installed the units without the proper spacing to be able to open them up and allow me to swap cables (getting this fixed with the aftercare service).
In the meantime I want to see if I can just splice the manufacturer cable to connect to the module I bought from Nodo shop but I don't want to risk frying my aircon units or esp hardware.

See picture of the wifi unit:
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
I've identified which pins are the 12V and GND but not sure about the 3 middle pins as I couldn't find any obvious trace to what I expect are the MISO, MOSI and SCK pins on the chip.
I'm no electronics expert so wanted to ask if there's any risk to my units if I just try those pins randomly until I can identify the correct orientation. Thoughts?

fonske, 2024-12-05:
This cable has the same wiring order as the MHI-AC-CTRL
I checked already.

I was planning to make a pcb with this connector on the board too
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

ThomasHFWright, 2024-12-05:
That's awesome, do you know what the connector standard is? I'd love to just buy or make a converter from the manufacturer cable to the one on the piece of hardware I bought

fonske, 2024-12-05:
@ThomasHFWright
I think the connector is a SM05B-GHS-TB(LF)(SN) from jst

glsf91, 2024-12-05:
I cut the wifi cable in the middle (power off AC !!). Then bought this: https://www.aliexpress.com/item/1005003977653324.html
Cut 1 of the cables in the middle. Soldered 1 part to the wifi cable from AC. Other part to the wifi module. Used Heat Shrink Tube to protect.
Now I can connect (with AC mains power off!) the mhi-ac-ctrl module or wifi module to the AC.

fonske, 2024-12-05:
@glsf91
Are you sure you this fits on this module, because the pitch size (1,25) looks smaller then the one in your link?

ThomasHFWright, 2024-12-05:
It looks like these might be the right size https://www.aliexpress.com/item/1005006135792829.html

glsf91, 2024-12-05:
I used the cable from my link. This cable (JST-XH) fits on the mhi-ac-ctrl module like described in https://github.com/absalom-muc/MHI-AC-Ctrl/blob/master/Hardware.md under connector. It also fits the CNS port on the AC.
It won't fit of course the connector on the pcb of the wifi module.
But I see your cable of the wifi module is short. So probably makes not much sense to cut the cable like I did. My cable was 1 meter.

ThomasHFWright, 2024-12-05:
> @ThomasHFWright I **think** the connector is a SM05B-GHS-TB(LF)(SN) from jst it doesnt fit on the standard soldering connection though because of 1.25 mm pitch instead of 2 mm
>
> I am happy to make one for you, when i order the new pcb's

I appreciate the thought, but I already have all the hardware for the regular JST-XH cable so just looking for a simple adapter to put together

fonske, 2024-12-05:
@ThomasHFWright
Not sure if it will fit on the original connector as it is GH
https://www.lcsc.com/datasheet/lcsc_datasheet_2304140030_JST-SM05B-GHS-TB-LF-SN_C189896.pdf

ThomasHFWright, 2024-12-05:
> @ThomasHFWright Not sure if it will fit on the original connector as it is GH https://www.lcsc.com/datasheet/lcsc_datasheet_2304140030_JST-SM05B-GHS-TB-LF-SN_C189896.pdf

hmm yes you're right, I can't see any listings with female connectors. Only male such as https://www.aliexpress.com/item/1005007295303376.html
I suppose I can just splice the cable while it remains plugged in as long as I cut the power.

ThomasHFWright, 2024-12-05:
Anyone know where to look for a 5 pin JST GH breakout board? Closest I could find is a 6 pin https://mktechnic.com/product/jst-1-25-6-pin-female-connector-adapter-pcb-breakout-board/

ThomasHFWright, 2024-12-05:
I ended up ordering some little boards on JLCPCB to plug into and keep everything stock.
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

[PickAndPlace_PCB_JST-GH-5-pin-breakout_2024-12-05.csv](https://github.com/user-attachments/files/18026016/PickAndPlace_PCB_JST-GH-5-pin-breakout_2024-12-05.csv)
[Gerber_JST-GH-5-pin-breakout_PCB_JST-GH-5-pin-breakout_2024-12-05.zip](https://github.com/user-attachments/files/18026017/Gerber_JST-GH-5-pin-breakout_PCB_JST-GH-5-pin-breakout_2024-12-05.zip)

fonske, 2024-12-18:
@ThomasHFWright
I got my pcb's also delivered today,
The connector is the correct one.

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

glsf91, 2025-01-12:
I close this one. We can reopen if needed

Closed 2025-01-12.

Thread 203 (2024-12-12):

Mitsubishi WF-RAC Interface wiring

tech2mar, 2024-12-12:
Hi friends,

Is it possible that this Mitsubishi WF-RAC Interface module has wiring issues? It seems like it’s not powering on, as the device doesn’t work at all. Could it be that the 12V+ and GND connections are swapped or incorrectly wired? Has anyone experienced something like this before?

I recently made some PCBs for my home and sold this module to a friend, but he’s struggling to get it to work. Unfortunately, I haven’t had the chance to use this module myself, as I prefer a local solution for my own unit.

Any advice or insights would be greatly appreciated!

Very strange.

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

glsf91, 2024-12-13:
You can see [here](https://github.com/absalom-muc/MHI-AC-Ctrl/blob/master/Hardware.md#connectorl) how the board is connected to he AC. So check if your cable is doing the same.
You can also check if the Wemos receives 5V from the TSR_1-2450.
If that is the case take a look at the serial logging of the Wemos with a usb cable (and the module connected to the AC).

tech2mar, 2024-12-19:
Update maybe the Modul is not working at all, is it possible to flash the Modul and using It without MQTT or Home Assistent? With Esphome and a direct Esphome server on it?

glsf91, 2024-12-20:
You can use the module without MQTT. See CONTINUE_WITHOUT_MQTT  in support.h
But if you don't use an external DS18x20 temperature sensor it has no sense to use the module without MQTT.
For esphome you have to use: https://github.com/ginkage/MHI-AC-Ctrl-ESPHome
(you can ask question about esphome there)

tech2mar, 2024-12-22:
Thank you for your help.

glsf91, 2025-01-12:
I close this one. We can reopen if needed

Closed 2025-01-12.

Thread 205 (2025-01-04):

Wemos restarts after connecting to AC

Haegar88, 2025-01-04:
Hi, after connecting to the AC the Flash-LED of the Wemos periodically flashes. I think he's rebooting periodically, but i dont't know why. Can I connect the Laptop to the Mirco-USB while the Wemos is powered via 12V from the AC? Any ideas why the device reboots?
BR Haegar

glsf91, 2025-01-04:
yes, you can connect your laptop if it is powered from ac.
Take a look at the serial logging to take a look if it is rebooting and why

Haegar88, 2025-01-04:
That's the serial output..

Starting MHI-AC-Ctrl v2.8
CPU frequency[Hz]=80000000
ESP.getCoreVersion()=3.1.2
ESP.getSdkVersion()=2.2.2-dev(38a443e)
ESP.checkFlashCRC()=1
Measure frequency for SCK, MOSI and MISO pin
SCK frequency=3200Hz (expected: >3000Hz) o.k.
MOSI frequency=615Hz (expected: <SCK frequency) o.k.
MISO frequency=0Hz (expected: ~0Hz) o.k.
OTA Ready
setupWiFi: Start async scanNetworks
WIFI_CONNECT_SCANNING
status=65 topic=Mode payload=Auto

--------------- CUT HERE FOR EXCEPTION DECODER ---------------

Exception (3):
epc1=0x4021ba5e epc2=0x00000000 epc3=0x00000000 excvaddr=0x4024c938 depc=0x00000000

>>>stack>>>

ctx: cont
sp: 3ffffd80 end: 3fffffd0 offset: 0150
3ffffed0:  4024c938 0000010f 00000079 3ffeeb08
3ffffee0:  4024c9e4 4024c938 00000041 402055e0
3ffffef0:  2d49484d 432d4341 2f6c7274 65646f4d
3fffff00:  00000000 00000000 00000000 00000000
3fffff10:  00000000 00000000 00000000 00000000
3fffff20:  00000000 00000000 00000000 00000000
3fffff30:  00000000 00000000 00000000 00000000
3fffff40:  00000000 00000000 00000000 00000000
3fffff50:  00000000 00000001 0000000c 3ffeeb08
3fffff60:  00000014 3ffeeac8 3ffe85c8 402013e4
3fffff70:  00000053 00000000 00000001 000007fe
3fffff80:  00000050 3ffe85db b3333333 00093e7f
3fffff90:  3ffefa0c 40205c84 3ffeeb54 3ffef004
3fffffa0:  00000000 3ffeeafc 3ffeeb08 40204e5f
3fffffb0:  3fffdad0 00000000 3ffeefd8 40210478
3fffffc0:  feefeffe feefeffe 3fffdab0 401003e5
<<<stack<<<

--------------- CUT HERE FOR EXCEPTION DECODER ---------------

 ets Jan  8 2013,rst cause:1, boot mode:(3,3)

load 0x4010f000, len 3424, room 16
tail 0
chksum 0x2e
load 0x3fff20b8, len 40, room 8
tail 0
chksum 0x2b
csum 0x2b
v000557e0
~ld

glsf91, 2025-01-04:
I don't know what you removed in the code (what was your plan).  Looks like when connecting to wifi it restarts. Use the esp exception decoder.

Haegar88, 2025-01-04:
Hello, the culprit was indeed Pubsub version 2.8.0 . With 2.7.0 it works without any problems. Thank you very much, I would never have thought of that.

Closed 2025-01-05.

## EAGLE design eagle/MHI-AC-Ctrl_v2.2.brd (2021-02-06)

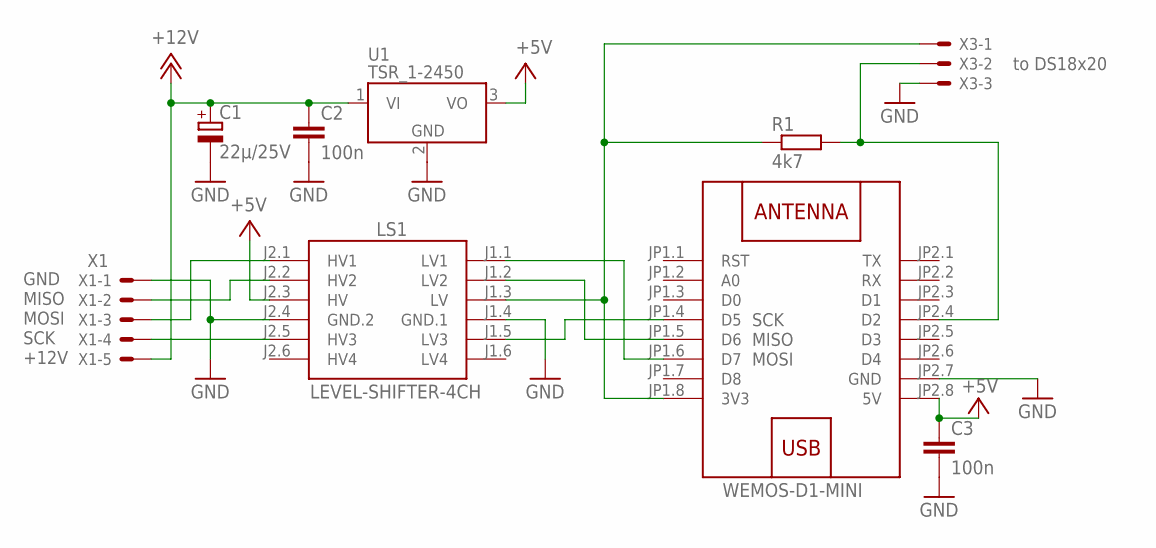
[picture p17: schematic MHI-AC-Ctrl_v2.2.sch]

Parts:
C1: 22µ/25V; E15-5
C2, C3: 100n; C025-024X044
LS1: LEVEL-SHIFTER-4CH
R1: 4k7; 0207/10
U1: TSR_1-2450; TSR-1
U$1: WEMOS-D1-MINI
X1: JST 03JQ-BT; JST-XH-05-PACKAGE-LONG-PAD
X3: JST-XH-03-PIN; JST-XH-03-ST90-PACKAGE-LONG-PAD

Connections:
+3V3: LS1.J1.3 (LV), R1.1, U$1.JP1.8 (3V3), X3.1
+5V: C3.1, LS1.J2.3 (HV), U1.3 (VO), U$1.JP2.8 (5V)
+12V: C1.+, C2.1, U1.1 (VI), X1.5
D2: R1.2, U$1.JP2.4 (D2), X3.2
GND: C1.-, C2.2, C3.2, LS1.J1.4 (GND.1), LS1.J2.4 (GND.2), U1.2 (GND), U$1.JP2.7 (GND), X1.1, X3.3
MISO: LS1.J2.2 (HV2), X1.2
MISO_LV: LS1.J1.2 (LV2), U$1.JP1.5 (D6)
MOSI: LS1.J2.1 (HV1), X1.3
MOSI_LV: LS1.J1.1 (LV1), U$1.JP1.6 (D7)
SCK: LS1.J2.5 (HV3), X1.4
SCK_LV: LS1.J1.5 (LV3), U$1.JP1.4 (D5)

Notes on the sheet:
MOSI
MISO
SCK
to DS18x20

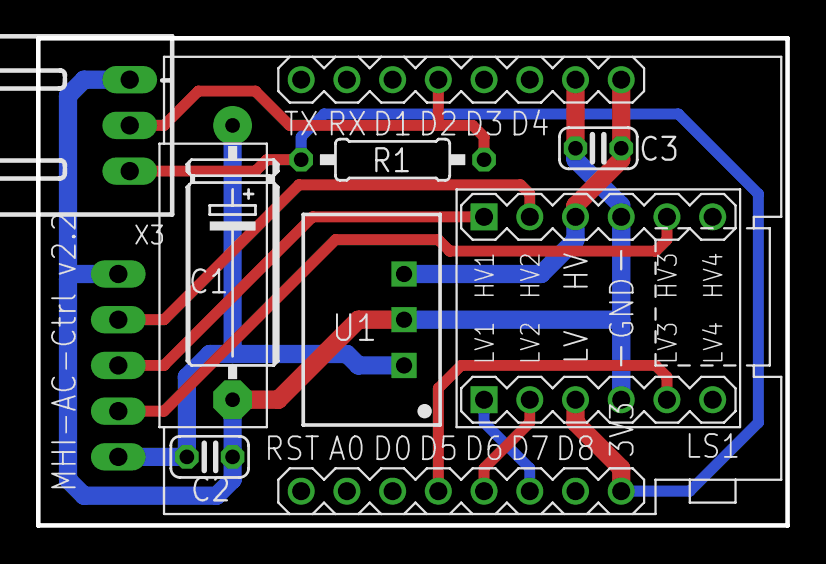
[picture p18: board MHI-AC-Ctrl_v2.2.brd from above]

Board: 2 copper layers, 41.6 x 27.1 mm, 9 parts (1 on the bottom side), 11 nets.

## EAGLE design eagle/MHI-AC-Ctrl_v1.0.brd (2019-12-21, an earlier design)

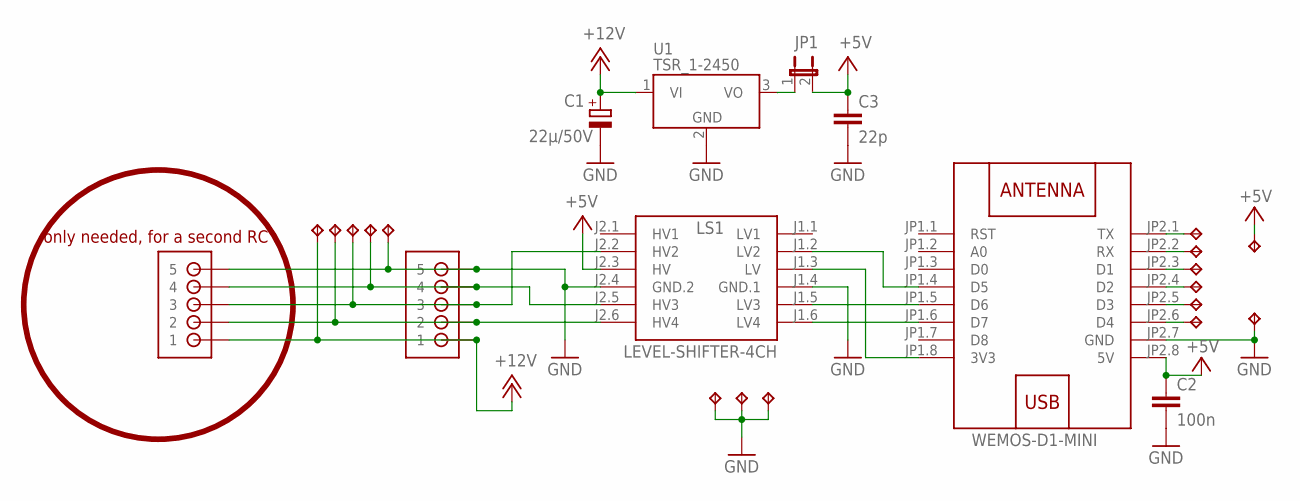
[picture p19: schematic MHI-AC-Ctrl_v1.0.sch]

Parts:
C1: 22µ/50V; E5-10,5
C2: 100n; C025-024X044
C3: 22p; C025-024X044
JP1: JP1E; JP1
LS1: LEVEL-SHIFTER-4CH
TP1, TP2, TP3, TP4, TP5, TP6, TP7, TP8, TP9, TP10, TP11, TP12, TP13, TP14, TP15, TP16: TPPAD1-13; P1-13
U1: TSR_1-2450; TSR-1
U$1: WEMOS-D1-MINI
U$4, U$5: JST-PH_5-PIN_HEADER; JST_B5B-PH_HEADER

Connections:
+3V3: LS1.J1.3 (LV), U$1.JP1.8 (3V3)
+5V: C2.1, C3.1, JP1.2, LS1.J2.3 (HV), TP8.TP, U$1.JP2.8 (5V)
+12V: C1.+, TP13.TP, U1.1 (VI), U$4.P1 (1), U$5.P1 (1)
GND: C1.-, C2.2, C3.2, LS1.J1.4 (GND.1), LS1.J2.4 (GND.2), TP7.TP, TP9.TP, TP14.TP, TP15.TP, TP16.TP, U1.2 (GND), U$1.JP2.7 (GND), U$4.P5 (5), U$5.P5 (5)
MISO: LS1.J2.5 (HV3), TP10.TP, U$4.P4 (4), U$5.P4 (4)
MISO_LV: LS1.J1.5 (LV3), U$1.JP1.5 (D6)
MOSI: LS1.J2.6 (HV4), TP12.TP, U$4.P2 (2), U$5.P2 (2)
MOSI_LV: LS1.J1.6 (LV4), U$1.JP1.6 (D7)
unnamed: TP1.TP, U$1.JP2.1 (TX)
unnamed: TP2.TP, U$1.JP2.2 (RX)
unnamed: TP3.TP, U$1.JP2.3 (D1)
unnamed: TP4.TP, U$1.JP2.4 (D2)
unnamed: TP5.TP, U$1.JP2.5 (D3)
unnamed: TP6.TP, U$1.JP2.6 (D4)
unnamed: JP1.1, U1.3 (VO)
SCL: LS1.J2.2 (HV2), TP11.TP, U$4.P3 (3), U$5.P3 (3)
SCL_LV: LS1.J1.2 (LV2), U$1.JP1.4 (D5)

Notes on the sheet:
only needed, for a second RC

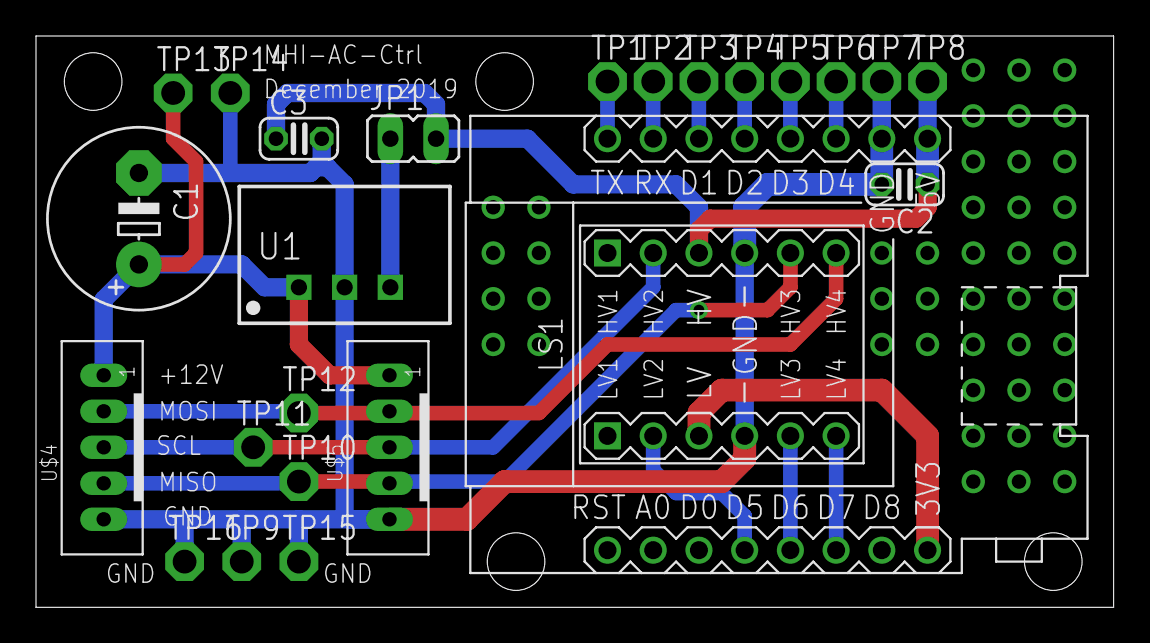
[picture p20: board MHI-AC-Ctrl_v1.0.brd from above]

Board: 2 copper layers, 59.9 x 31.7 mm, 25 parts (0 on the bottom side), 17 nets.

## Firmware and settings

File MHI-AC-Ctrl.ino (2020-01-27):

// MHI-AC-Ctrl v1.2 by absalom-muc
// read + write data via SPI controlled by MQTT

#include <ESP8266WiFi.h>
#include <PubSubClient.h> // see https://github.com/knolleary/pubsubclient
#include <ArduinoOTA.h>

#define SCK 14
#define MOSI 13
#define MISO 12

#define MQTT_SERVER "ds218p"
#define MQTT_PORT 1883
#define MQTT_PREFIX "MHI-AC-Ctrl/"
#define MQTT_SET_PREFIX MQTT_PREFIX "set/"

const char* ssid = "**********";
const char* password = "**********";
const char* hostname = "MHI-AC-Ctrl";

WiFiClient espClient;
PubSubClient MQTTclient(espClient);

bool sync = 0;
byte rx_SPIframe[20];
bool updateMQTTStatus=true;

#define SB0 0
#define SB1 SB0 + 1
#define SB2 SB0 + 2
#define DB0 SB2 + 1
#define DB1 SB2 + 2
#define DB2 SB2 + 3
#define DB3 SB2 + 4
#define DB4 SB2 + 5
#define DB6 SB2 + 7
#define DB9 SB2 + 10
#define DB10 SB2 + 11
#define DB11 SB2 + 12
#define DB14 SB2 + 15
#define CBH 18
#define CBL 19

void setupOTA() {
  ArduinoOTA.setHostname(hostname);
  ArduinoOTA.onStart([]() {
    String type;
    if (ArduinoOTA.getCommand() == U_FLASH) {
      type = "sketch";
    } else { // U_SPIFFS
      type = "filesystem";
    }

    // NOTE: if updating SPIFFS this would be the place to unmount SPIFFS using SPIFFS.end()
    Serial.println("Start updating " + type);
  });
  ArduinoOTA.onEnd([]() {
    Serial.println("\nEnd");
  });
  ArduinoOTA.onProgress([](unsigned int progress, unsigned int total) {
    Serial.printf("Progress: %u%%\r", (progress / (total / 100)));
  });
  ArduinoOTA.onError([](ota_error_t error) {
    Serial.printf("Error[%u]: ", error);
    if (error == OTA_AUTH_ERROR) { Serial.println("Auth Failed"); }
    else if (error == OTA_BEGIN_ERROR) { Serial.println("Begin Failed"); }
    else if (error == OTA_CONNECT_ERROR) { Serial.println("Connect Failed"); }
    else if (error == OTA_RECEIVE_ERROR) { Serial.println("Receive Failed"); }
    else if (error == OTA_END_ERROR) { Serial.println("End Failed"); }
  });
  ArduinoOTA.begin();
  Serial.println("OTA Ready");
  Serial.print("IP address: ");
  Serial.println(WiFi.localIP());
}

void MQTTreconnect() {
  unsigned long runtimeMillisMQTT;
  Serial.println("MQTTreconnect");
  while (!MQTTclient.connected()) { // Loop until we're reconnected
    update_sync(false);
    Serial.print("Attempting MQTT connection...");
    if (MQTTclient.connect (hostname, MQTT_PREFIX "connected", 0, true, "false")) {
      Serial.println("connected");
      MQTTclient.publish(MQTT_PREFIX "connected", "true", true);
      MQTTclient.subscribe(MQTT_SET_PREFIX "#");
      updateMQTTStatus=true;
    }
    else {
      Serial.print("failed, rc=");
      Serial.print(MQTTclient.state());
      Serial.println(" try again in 5 seconds");
      runtimeMillisMQTT = millis();
      while (millis() - runtimeMillisMQTT < 5000) { // Wait 5 seconds before retrying
        delay(0);
        ArduinoOTA.handle();
      }
    }
  }
}

void update_sync(bool sync_new) {
  if (sync_new != sync) {
    sync = sync_new;
    Serial.printf("sync=%i\n", sync);
    if (sync)
      MQTTclient.publish (MQTT_PREFIX "synced", "1", true);
    else 
      MQTTclient.publish (MQTT_PREFIX "synced", "0", true);
  }
}

void publish_cmd_ok() {
  MQTTclient.publish(MQTT_PREFIX "cmd_received", "o.k.");
}
void publish_cmd_unknown() {
  MQTTclient.publish(MQTT_PREFIX "cmd_received", "unknown command");
}
void publish_cmd_invalidparameter() {
  MQTTclient.publish(MQTT_PREFIX "cmd_received", "invalid parameter");
}

bool set_Power = false;
byte new_Power;
bool set_Mode = false;
byte new_Mode;
bool set_Tsetpoint = false;
byte new_Tsetpoint;
bool set_Fan = false;
byte new_Fan;
bool set_Vanes = false;
byte new_Vanes;

void MQTT_subscribe_callback(char* topic, byte* payload, unsigned int length) {
  char payload_str[20];
  memcpy(payload_str, payload, length);
  payload_str[length] = '\0';

  if (strcmp(topic, MQTT_SET_PREFIX "Power") == 0) {
    new_Power = rx_SPIframe[DB0] | 0b11;
    if (strcmp(payload_str, "On") == 0) {
      set_Power = true;
      new_Power = 0b11;
      publish_cmd_ok();
    }
    else if (strcmp(payload_str, "Off") == 0) {
      set_Power = true;
      new_Power = 0b10;
      publish_cmd_ok();
    }
    else
      publish_cmd_invalidparameter();
  }
  else if (strcmp(topic, MQTT_SET_PREFIX "Mode") == 0) {
    if (strcmp(payload_str, "Auto") == 0) {
      set_Mode = true;
      new_Mode = 0b00100000;
      publish_cmd_ok();
    }
    else if (strcmp(payload_str, "Dry") == 0) {
      set_Mode = true;
      new_Mode = 0b00100100;
      publish_cmd_ok();
    }
    else if (strcmp(payload_str, "Cool") == 0) {
      set_Mode = true;
      new_Mode = 0b00101000;
      publish_cmd_ok();
    }
    else if (strcmp(payload_str, "Fan") == 0) {
      set_Mode = true;
      new_Mode = 0b00101100;
      publish_cmd_ok();
    }
    else if (strcmp(payload_str, "Heat") == 0) {
      set_Mode = true;
      new_Mode = 0b00110000;
      publish_cmd_ok();
    }
    else
      publish_cmd_invalidparameter();
  }
  else if (strcmp(topic, MQTT_SET_PREFIX "Tsetpoint") == 0) {
    new_Tsetpoint = atoi(payload_str);
    if ((new_Tsetpoint >= 18) & (new_Tsetpoint <= 30)) {
      set_Tsetpoint = true;
      publish_cmd_ok();
    }
    else
      publish_cmd_invalidparameter();
  }
  else if (strcmp(topic, MQTT_SET_PREFIX "Fan") == 0) {
    new_Fan = atoi(payload_str);
    if ((new_Fan >= 1) & (new_Fan <= 4)) {
      set_Fan = true;
      publish_cmd_ok();
    }
    else
      publish_cmd_invalidparameter();
  }
  else if (strcmp(topic, MQTT_SET_PREFIX "Vanes") == 0) {
    if(strcmp(payload_str, "Swing") == 0) {
      new_Vanes = 5;
      set_Vanes = true;
      publish_cmd_ok();
    }
    else {
      new_Vanes = atoi(payload_str);
      if ((new_Vanes >= 1) & (new_Vanes <= 5)) {
        set_Vanes = true;
        publish_cmd_ok();
      }
      else 
        publish_cmd_invalidparameter();  
    }
  }
  else
    publish_cmd_unknown();
}

void setup() {
  Serial.begin(115200);
  Serial.println();
  Serial.printf("%lu:MHI-AC-Ctrl starting\n", millis());
  pinMode(SCK, INPUT_PULLUP);
  pinMode(MOSI, INPUT);
  pinMode(MISO, OUTPUT);
  pinMode(LED_BUILTIN, OUTPUT);  // indicates that a frame was received, active low
  digitalWrite(LED_BUILTIN, HIGH);

  WiFi.hostname(hostname);
  WiFi.begin(ssid, password);
  Serial.println("");
  while (WiFi.status() != WL_CONNECTED) {
    delay(500);
    Serial.print(".");
  }
  setupOTA();
  Serial.printf(" connected to %s, IP address: %s\n", ssid, WiFi.localIP().toString().c_str());
  MQTTclient.setServer(MQTT_SERVER, MQTT_PORT);
  MQTTclient.setCallback(MQTT_subscribe_callback);
  MQTTreconnect();
}

//                        sb0   sb1   sb2   db0   db1   db2   db3   db4   db5   db6   db7   db8   db9  db10  db11  db12  db13  db14  chkH  chkL
byte tx_SPIframe[20] = { 0xA9, 0x00, 0x07, 0x00, 0x00, 0x00, 0xFF, 0x00, 0x00, 0x00, 0x00, 0x00, 0x80, 0xFF, 0xFF, 0xFF, 0x0F, 0x04, 0x05, 0xF5 };
const byte frameVariant[3][9] {                                              { 0x40, 0x00, 0x00, 0x80, 0xFF, 0xFF, 0xFF, 0x0F, 0x04 },  //variant number 0
																				                                     { 0x80, 0x00, 0x00, 0x32, 0xD6, 0x01, 0x00, 0x0F, 0x04 },  //variant number 1
																				                                     { 0x80, 0x00, 0x00, 0xF1, 0xF7, 0xFF, 0xFF, 0x0F, 0x04 }}; //variant number 2

uint16_t calc_tx_checksum() {
  uint16_t checksum = 0;
  for (int i = 0; i < CBH; i++)
    checksum += tx_SPIframe[i];
  return checksum;
}

void loop() {
  uint8_t fan_old = 0xff;
  uint8_t vanes_old = 0xff;
  uint8_t power_old = 0xff;
  uint8_t mode_old = 0xff;
  uint8_t errorcode_old = 0xff;
  byte troom_old = 0xff;
  byte toutdoor_old = 0xff;
  byte tsetpoint_old = 0xff;
  char strtmp[10]; // for the MQTT strings to send
  byte payload_byte;
  unsigned long lastDatapacketMillis = 0;
  unsigned long SCKMillis;
  bool valid_datapacket_received = false;
  bool new_datapacket_received = false;
  uint16_t packet_cnt = 0;
  uint8_t repetitionNo = 0;
  uint8_t variantnumber = 0;
  uint8_t doubleframe = 1;
  uint8_t frame = 1;


  while (1) {

    SCKMillis = millis();
    while (millis() - SCKMillis < 5) { // wait for 5ms stable high signal
      delay(0);
      if (!digitalRead(SCK)) {
        SCKMillis = millis();
        if (millis() - lastDatapacketMillis > 35)
          update_sync(false);
      }
    }

    if (frame++ > 19) { // setup tx frame
      doubleframe++;  // toggle between 0 and 1
      tx_SPIframe[DB14] = doubleframe % 2;
      frame = 1;
      if (doubleframe % 2) {
        variantnumber = (variantnumber + 1) % 3;
        memcpy(&tx_SPIframe[DB6], &frameVariant[variantnumber][0], 9);

        tx_SPIframe[DB0] = 0;
        tx_SPIframe[DB1] = 0;
        tx_SPIframe[DB2] = 0;
       
        if (set_Power) {
          tx_SPIframe[DB0] = new_Power;
          set_Power = false;
        }

        if (set_Mode) {
          tx_SPIframe[DB0] = new_Mode;
          set_Mode = false;
        }

        if (set_Tsetpoint) {
          tx_SPIframe[DB2] = 2 * new_Tsetpoint | 0b10000000;
          set_Tsetpoint = false;
        }

        if (set_Fan) { // Kollidiert mit Variante 0 da dort db6=0x40
          if (new_Fan == 4) {
            tx_SPIframe[DB1] = 0b1010;
            tx_SPIframe[DB6] |= 0b00010000;
          }
          else
            tx_SPIframe[DB1] = (1 << 3) | (new_Fan - 1);
          set_Fan = false;
        }

        if (set_Vanes) {
          if (new_Vanes == 5) //5: swing
            tx_SPIframe[DB0] = 0b11000000;
          else { // when setting a new vanes position, swing is automatically disabled
            tx_SPIframe[DB1] = (1 << 7) | ((new_Vanes - 1) << 4);
          }
          set_Vanes = false;
        }
      }
    }

    uint16_t tx_checksum = calc_tx_checksum();
    tx_SPIframe[CBH] = highByte(tx_checksum);
    tx_SPIframe[CBL] = lowByte(tx_checksum);

    new_datapacket_received = false;
    uint16_t rx_checksum = 0;
    for (uint8_t byte_cnt = 0; byte_cnt < 20; byte_cnt++) { // read and write a data packet of 20 bytes
      payload_byte = 0;
      byte bit_mask = 1;
      for (uint8_t bit_cnt = 0; bit_cnt < 8; bit_cnt++) { // read and write 1 byte
        while (digitalRead(SCK)) {} // wait for falling edge
        if ((tx_SPIframe[byte_cnt] & bit_mask) > 0)
          digitalWrite(MISO, 1);
        else
          digitalWrite(MISO, 0);
        while (!digitalRead(SCK)) {} // wait for rising edge
        if (digitalRead(MOSI))
          payload_byte += bit_mask;
        bit_mask = bit_mask << 1;
      }

      if (rx_SPIframe[byte_cnt] != payload_byte) {
        new_datapacket_received = true;
        rx_SPIframe[byte_cnt] = payload_byte;
      }

      if (byte_cnt < 18)
        rx_checksum += payload_byte;
    }

    if ((rx_SPIframe[SB0] == 0x6c) & (rx_SPIframe[SB1] == 0x80) & (rx_SPIframe[SB2] == 0x04) & (rx_SPIframe[CBH] == highByte(rx_checksum)) & (rx_SPIframe[CBL] == lowByte(rx_checksum)))
      valid_datapacket_received = true;
    else
      update_sync(false);

    if (valid_datapacket_received) { // valid frame received
      packet_cnt++;
      repetitionNo++;
      valid_datapacket_received = false;
      if (millis() - lastDatapacketMillis < 60)
        update_sync(true);
      lastDatapacketMillis = millis();

      digitalWrite(LED_BUILTIN, HIGH);
      if (new_datapacket_received) {
        new_datapacket_received = false;
        /*MQTTclient.beginPublish (MQTT_PREFIX "raw", 43, true);  // raw data are usually not needed
        MQTTclient.write(highByte(packet_cnt));
        MQTTclient.write(lowByte(packet_cnt));
        MQTTclient.write(rx_SPIframe, 20);
        MQTTclient.write(tx_SPIframe, 20);
        MQTTclient.write(repetitionNo);
        MQTTclient.endPublish();*/
        repetitionNo = 0;
        if (updateMQTTStatus | ((rx_SPIframe[DB0] & 0x01) != power_old)) { // Power
          power_old = rx_SPIframe[DB0] & 0x01;
          if (power_old == 0)
            MQTTclient.publish(MQTT_PREFIX "Power", "Off", true);
          else
            MQTTclient.publish(MQTT_PREFIX "Power", "On", true);
        }

        if (updateMQTTStatus | ((rx_SPIframe[DB0] & 0x1c) != mode_old)) { // Mode
          mode_old = rx_SPIframe[DB0] & 0x1c;
          switch (mode_old) {
            case 0x00:
              MQTTclient.publish(MQTT_PREFIX "Mode", "Auto", true);
              break;
            case 0x04:
              MQTTclient.publish(MQTT_PREFIX "Mode", "Dry", true);
              break;
            case 0x08:
              MQTTclient.publish(MQTT_PREFIX "Mode", "Cool", true);
              break;
            case 0x0c:
              MQTTclient.publish(MQTT_PREFIX "Mode", "Fan", true);
              break;
            case 0x10:
              MQTTclient.publish(MQTT_PREFIX "Mode", "Heat", true);
              break;
            default:
              MQTTclient.publish(MQTT_PREFIX "Mode", "invalid", true);
              break;
          }
        }

        uint fantmp;
        if ((rx_SPIframe[DB6] & 0x40) != 0) // Fan status
          fantmp = 4;
        else
          fantmp = (rx_SPIframe[DB1] & 0x03) + 1;
        if (updateMQTTStatus | (fantmp != fan_old)) {
          fan_old = fantmp;
          itoa(fan_old, strtmp, 10);
          MQTTclient.publish(MQTT_PREFIX "Fan", strtmp, true);
        }

        // Only updated when Vanes command via wired RC
        uint vanestmp = (rx_SPIframe[DB0] & 0xc0) + ((rx_SPIframe[DB1] & 0xB0) >> 4);
        if (updateMQTTStatus | (vanestmp != vanes_old)) {
          if ((vanestmp & 0x88) == 0) // last vanes update was via IR-RC, so status is not known
            MQTTclient.publish(MQTT_PREFIX "Vanes", "?", true);
          else if ((vanestmp & 0x40) != 0) // Vanes status swing
            MQTTclient.publish(MQTT_PREFIX "Vanes", "Swing", true);
          else {
            switch (vanestmp & 0x03) {
              case 0x00:
                MQTTclient.publish(MQTT_PREFIX "Vanes", "1", true);  // up
                break;
              case 0x01:
                MQTTclient.publish(MQTT_PREFIX "Vanes", "2", true);
                break;
              case 0x02:
                MQTTclient.publish(MQTT_PREFIX "Vanes", "3", true);
                break;
              case 0x03:
                MQTTclient.publish(MQTT_PREFIX "Vanes", "4", true);  // down
                break;
            }
          }
          vanes_old = vanestmp;
        }

        if (updateMQTTStatus | (abs(rx_SPIframe[DB3] - troom_old) > 1)) { // Room temperature delta > 0.25°C
          troom_old = rx_SPIframe[DB3];
          float troom = (float)(troom_old - 61) / 4.0;
          dtostrf(troom, 0, 2, strtmp);
          MQTTclient.publish(MQTT_PREFIX "Troom", strtmp, true);
        }

        if (updateMQTTStatus | ((rx_SPIframe[DB2] & 0x7f) >> 1 != tsetpoint_old)) { // Temperature setpoint
          tsetpoint_old = (rx_SPIframe[DB2] & 0x7f) >> 1;
          itoa(tsetpoint_old, strtmp, 10);
          MQTTclient.publish(MQTT_PREFIX "Tsetpoint", strtmp, true);
        }

        if (updateMQTTStatus | (rx_SPIframe[DB4] != errorcode_old)) { // error code
          errorcode_old = rx_SPIframe[DB4];
          itoa(errorcode_old, strtmp, 10);
          MQTTclient.publish(MQTT_PREFIX "Errorcode", strtmp, true);
        }

        if (updateMQTTStatus | ((rx_SPIframe[DB9] == 0x80) & (rx_SPIframe[DB10] == 0x10))) { // indicates variant 0 => outdoor temperature
          if (abs(rx_SPIframe[DB11] - toutdoor_old) > 1) { // Outdoor temperature delta > 0.25°C to prevent toggling
            toutdoor_old = rx_SPIframe[DB11];
            float toutdoor = (float)(toutdoor_old - 94) / 4.0;
            dtostrf(toutdoor, 0, 2, strtmp);
            MQTTclient.publish(MQTT_PREFIX "Toutdoor", strtmp, true);
          }
        }
        updateMQTTStatus = false;
      } // if(new_datapacket_received)
    } // if(valid_datapacket_received)

    if (!MQTTclient.connected())
      MQTTreconnect();
    MQTTclient.loop();
    ArduinoOTA.handle();
  }
}

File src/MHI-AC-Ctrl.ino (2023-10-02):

// MHI-AC-Ctrl by absalom-muc
// read + write data via SPI controlled by MQTT
// for version see support.h

#include "MHI-AC-Ctrl-core.h"
#include "MHI-AC-Ctrl.h"
#include "support.h"

MHI_AC_Ctrl_Core mhi_ac_ctrl_core;

POWER_STATUS power_status = unknown;

unsigned long room_temp_set_timeout_Millis = millis();
bool troom_was_set_by_MQTT = false;
bool troom_was_set_by_DS18X20 = false;

void MQTT_subscribe_callback(const char* topic, byte* payload, unsigned int length) {
  payload[length] = 0;  // we need a string
  Serial.printf_P(PSTR("MQTT_subscribe_callback, topic=%s payload=%s payload_length=%i\n"), topic, (char*)payload, length);
#ifndef POWERON_WHEN_CHANGING_MODE
  if (strcmp_P(topic, PSTR(MQTT_SET_PREFIX TOPIC_POWER)) == 0) {
    if (strcmp_P((char*)payload, PSTR(PAYLOAD_POWER_ON)) == 0) {
      mhi_ac_ctrl_core.set_power(power_on);
      publish_cmd_ok();
    }
    else if (strcmp_P((char*)payload, PSTR(PAYLOAD_POWER_OFF)) == 0) {
      mhi_ac_ctrl_core.set_power(power_off);
      publish_cmd_ok();
    }
    else
      publish_cmd_invalidparameter();
  }
  else 
#endif
  if (strcmp_P(topic, PSTR(MQTT_SET_PREFIX TOPIC_MODE)) == 0) {
#ifdef POWERON_WHEN_CHANGING_MODE
    if (strcmp_P((char*)payload, PSTR(PAYLOAD_POWER_OFF)) == 0) {
      mhi_ac_ctrl_core.set_power(power_off);
      publish_cmd_ok();
    } else
#endif
      if (strcmp_P((char*)payload, PSTR(PAYLOAD_MODE_AUTO)) == 0) {
        mhi_ac_ctrl_core.set_mode(mode_auto);
#ifdef POWERON_WHEN_CHANGING_MODE
        mhi_ac_ctrl_core.set_power(power_on);
#endif
        publish_cmd_ok();
      }
      else if (strcmp_P((char*)payload, PSTR(PAYLOAD_MODE_DRY)) == 0) {
        mhi_ac_ctrl_core.set_mode(mode_dry);
#ifdef POWERON_WHEN_CHANGING_MODE
        mhi_ac_ctrl_core.set_power(power_on);
#endif
        publish_cmd_ok();
      }
      else if (strcmp_P((char*)payload, PSTR(PAYLOAD_MODE_COOL)) == 0) {
        mhi_ac_ctrl_core.set_mode(mode_cool);
#ifdef POWERON_WHEN_CHANGING_MODE
        mhi_ac_ctrl_core.set_power(power_on);
#endif
        publish_cmd_ok();
      }
      else if (strcmp_P((char*)payload, PSTR(PAYLOAD_MODE_FAN)) == 0) {
        mhi_ac_ctrl_core.set_mode(mode_fan);
#ifdef POWERON_WHEN_CHANGING_MODE
        mhi_ac_ctrl_core.set_power(power_on);
#endif
        publish_cmd_ok();
      }
      else if (strcmp_P((char*)payload, PSTR(PAYLOAD_MODE_HEAT)) == 0) {
        mhi_ac_ctrl_core.set_mode(mode_heat);
#ifdef POWERON_WHEN_CHANGING_MODE
        mhi_ac_ctrl_core.set_power(power_on);
#endif
        publish_cmd_ok();
      }
      else
        publish_cmd_invalidparameter();
  }
  else if (strcmp_P(topic, PSTR(MQTT_SET_PREFIX TOPIC_TSETPOINT)) == 0) {
    float f=atof((char*)payload);
    if((f >= 18) & (f <= 30))
      mhi_ac_ctrl_core.set_tsetpoint((byte)(2 * f));
    else
      publish_cmd_invalidparameter();
  }
  else if (strcmp_P(topic, PSTR(MQTT_SET_PREFIX TOPIC_FAN)) == 0) {
    if (strcmp_P((char*)payload, PAYLOAD_FAN_AUTO) == 0){
      mhi_ac_ctrl_core.set_fan(7);
      publish_cmd_ok();
    }
    else if (strcmp_P((char*)payload, "1") == 0){
      mhi_ac_ctrl_core.set_fan(0);
      publish_cmd_ok();
    }
    else if (strcmp_P((char*)payload, "2") == 0){
      mhi_ac_ctrl_core.set_fan(1);
      publish_cmd_ok();
    }
    else if (strcmp_P((char*)payload, "3") == 0){
      mhi_ac_ctrl_core.set_fan(2);
      publish_cmd_ok();
    }
    else if (strcmp_P((char*)payload, "4") == 0){
      mhi_ac_ctrl_core.set_fan(6);
      publish_cmd_ok();
    }
    else
      publish_cmd_invalidparameter();
  }
  else if (strcmp_P(topic, PSTR(MQTT_SET_PREFIX TOPIC_VANES)) == 0) {
    if (strcmp_P((char*)payload, PSTR(PAYLOAD_VANES_SWING)) == 0) {
      mhi_ac_ctrl_core.set_vanes(vanes_swing);
      publish_cmd_ok();
    }
    else {
      if ((atoi((char*)payload) >= 1) & (atoi((char*)payload) <= 5)) {
        mhi_ac_ctrl_core.set_vanes(atoi((char*)payload));
        publish_cmd_ok();
      }
      else
        publish_cmd_invalidparameter();
    }
  }
#ifdef USE_EXTENDED_FRAME_SIZE  
  else if (strcmp_P(topic, PSTR(MQTT_SET_PREFIX TOPIC_VANESLR)) == 0) {
    if (strcmp_P((char*)payload, PSTR(PAYLOAD_VANESLR_SWING)) == 0) {
      mhi_ac_ctrl_core.set_vanesLR(vanesLR_swing);
      publish_cmd_ok();
    }
    else {
      if ((atoi((char*)payload) >= 1) & (atoi((char*)payload) <= 7)) {
        mhi_ac_ctrl_core.set_vanesLR(atoi((char*)payload));
        publish_cmd_ok();
      }
      else
        publish_cmd_invalidparameter();
    }
  }
  else if (strcmp_P(topic, PSTR(MQTT_SET_PREFIX TOPIC_3DAUTO)) == 0) {
    if (strcmp_P((char*)payload, PSTR(PAYLOAD_3DAUTO_ON)) == 0) {
      mhi_ac_ctrl_core.set_3Dauto(Dauto_on);
      publish_cmd_ok();
    }
    else if (strcmp_P((char*)payload, PSTR(PAYLOAD_3DAUTO_OFF)) == 0) {
      mhi_ac_ctrl_core.set_3Dauto(Dauto_off);
      publish_cmd_ok();
    }
    else
      publish_cmd_invalidparameter();
  }
#endif
  else if (strcmp_P(topic, PSTR(MQTT_SET_PREFIX TOPIC_TROOM)) == 0) {
    float f=atof((char*)payload);
#ifdef ENHANCED_RESOLUTION
    f = f + mhi_ac_ctrl_core.get_troom_offset() ;  // increase Troom with current offset to compensate higher setpoint
#endif
    if ((f > -10) & (f < 48)) {
      room_temp_set_timeout_Millis = millis();  // reset timeout
      troom_was_set_by_MQTT=true;
      byte tmp = f*4+61;
      mhi_ac_ctrl_core.set_troom(f*4+61);
      Serial.printf("ROOM_TEMP_MQTT: %f %i %i\n", f, (byte)(f*4+61), (byte)tmp);
      publish_cmd_ok();
    }
    else
      publish_cmd_invalidparameter();
  }
  else if (strcmp_P(topic, PSTR(MQTT_SET_PREFIX TOPIC_REQUEST_ERROPDATA)) == 0) {
    mhi_ac_ctrl_core.request_ErrOpData();
    publish_cmd_ok();
  }
  else if (strcmp_P(topic, PSTR(MQTT_SET_PREFIX TOPIC_REQUEST_RESET)) == 0) {
    if (strcmp_P((char*)payload, PSTR(PAYLOAD_REQUEST_RESET)) == 0) {
      publish_cmd_ok();
      delay(500);
      ESP.restart();
    }
    else
      publish_cmd_invalidparameter();
  }
  else
    publish_cmd_unknown();
}
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

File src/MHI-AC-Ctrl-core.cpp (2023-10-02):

// MHI-AC-Ctrol-core
// implements the core functions (read & write SPI)

#include "MHI-AC-Ctrl-core.h"

uint16_t calc_checksum(byte* frame) {
  uint16_t checksum = 0;
  for (int i = 0; i < CBH; i++)
    checksum += frame[i];
  return checksum;
}

uint16_t calc_checksumFrame33(byte* frame) {
  uint16_t checksum = 0;
  for (int i = 0; i < CBL2; i++)
    checksum += frame[i];
  return checksum;
}

void MHI_AC_Ctrl_Core::reset_old_values() {  // used e.g. when MQTT connection to broker is lost, to re-output data
  // old status
  status_power_old = 0xff;
  status_mode_old = 0xff;
  status_fan_old = 0xff;
  status_vanes_old = 0xff;
  status_troom_old = 0xfe;
  status_tsetpoint_old = 0x00;
  status_errorcode_old = 0xff;
  status_vanesLR_old = 0xff;
  status_3Dauto_old = 0xff;

  // old operating data
  op_kwh_old = 0xffff;
  op_mode_old = 0xff;
  op_settemp_old = 0xff;
  op_return_air_old = 0xff;
  op_iu_fanspeed_old = 0xff;
  op_thi_r1_old = 0x00;
  op_thi_r2_old = 0x00;
  op_thi_r3_old = 0x00;
  op_total_iu_run_old = 0;
  op_outdoor_old = 0xff;
  op_tho_r1_old = 0x00;
  op_total_comp_run_old = 0;
  op_ct_old = 0xff;
  op_tdsh_old = 0xff;
  op_protection_no_old = 0xff;
  op_ou_fanspeed_old = 0xff;
  op_defrost_old = 0x00;
  op_comp_old = 0xffff;
  op_td_old  = 0x00;
  op_ou_eev1_old = 0xffff;
}

void MHI_AC_Ctrl_Core::init() {
  //MeasureFrequency(m_cbiStatus);
  pinMode(SCK_PIN, INPUT);
  pinMode(MOSI_PIN, INPUT);
  pinMode(MISO_PIN, OUTPUT);
  MHI_AC_Ctrl_Core::reset_old_values();
}

void MHI_AC_Ctrl_Core::set_power(boolean power) {
  new_Power = 0b10 | power;
}

void MHI_AC_Ctrl_Core::set_mode(ACMode mode) {
  new_Mode = 0b00100000 | mode;
}

void MHI_AC_Ctrl_Core::set_tsetpoint(uint tsetpoint) {
  new_Tsetpoint = 0b10000000 | tsetpoint;
}

void MHI_AC_Ctrl_Core::set_fan(uint fan) {
  new_Fan = 0b00001000 | fan;
}

void MHI_AC_Ctrl_Core::set_3Dauto(AC3Dauto Dauto) {
  new_3Dauto = 0b00001010 | Dauto;
}

void MHI_AC_Ctrl_Core::set_vanes(uint vanes) {
  if (vanes == vanes_swing) {
    new_Vanes0 = 0b11000000; // enable swing
  }
  else {
    new_Vanes0 = 0b10000000; // disable swing
    new_Vanes1 = 0b10000000 | ((vanes - 1) << 4);
  }
}

void MHI_AC_Ctrl_Core::set_vanesLR(uint vanesLR) {
  if (vanesLR == vanesLR_swing) {
    new_VanesLR0 = 0b00001011; // enable swing
  }
  else {
    new_VanesLR0 = 0b00001010; // disable swing
    new_VanesLR1 = 0b00010000 | (vanesLR - 1);
  }
}

void MHI_AC_Ctrl_Core::request_ErrOpData() {
  request_erropData = true;
}

void MHI_AC_Ctrl_Core::set_troom(byte troom) {
  //Serial.printf("MHI_AC_Ctrl_Core::set_troom %i\n", troom);
  new_Troom = troom;
}

float MHI_AC_Ctrl_Core::get_troom_offset() {
  return Troom_offset;
}

void MHI_AC_Ctrl_Core::set_troom_offset(float offset) {
  Troom_offset = offset;
}

void MHI_AC_Ctrl_Core::set_frame_size(byte framesize) {
  if (framesize == 20 || framesize == 33)
    frameSize = framesize;
}

int MHI_AC_Ctrl_Core::loop(uint max_time_ms) {
  const byte opdataCnt = sizeof(opdata) / sizeof(byte) / 2;
  static byte opdataNo = 0;               //
  long startMillis = millis();             // start time of this loop run
  byte MOSI_byte;                         // received MOSI byte
  bool new_datapacket_received = false;   // indicated that a new frame was received
  static byte erropdataCnt = 0;           // number of expected error operating data
  static bool doubleframe = false;
  static int frame = 1;
  static byte MOSI_frame[33];
  //                            sb0   sb1   sb2   db0   db1   db2   db3   db4   db5   db6   db7   db8   db9  db10  db11  db12  db13  db14  chkH  chkL  db15  db16  db17  db18  db19  db20  db21  db22  db23  db24  db25  db26  chk2L
  static byte MISO_frame[] = { 0xA9, 0x00, 0x07, 0x00, 0x00, 0x00, 0xff, 0x00, 0x00, 0x00, 0x00, 0x00, 0xff, 0xff, 0xff, 0xff, 0x0f, 0x00, 0x00, 0x00, 0x00, 0x00, 0x00, 0x00, 0x00, 0x00, 0x00, 0x00, 0xff, 0xff, 0xff, 0xff, 0x22 };

  static uint call_counter = 0;           // counts how often this loop was called
  static unsigned long lastTroomInternalMillis = 0; // remember when Troom internal has changed
  
  if (frameSize == 33)
    MISO_frame[0] = 0xAA;

  call_counter++;
  int SCKMillis = millis();               // time of last SCK low level
  while (millis() - SCKMillis < 5) {      // wait for 5ms stable high signal to detect a frame start
    if (!digitalRead(SCK_PIN))
      SCKMillis = millis();
    if (millis() - startMillis > max_time_ms)
      return err_msg_timeout_SCK_low;       // SCK stuck@ low error detection
  }
  // build the next MISO frame

  doubleframe = !doubleframe;             // toggle every frame
  MISO_frame[DB14] = doubleframe << 2;    // MISO_frame[DB14] bit2 toggles with every frame
  
  // Requesting all different opdata's is an opdata cycle. A cycle will take 20s.
  // With the current 20 different opdata's, every opdata request will take 1sec (interval).
  // If there are only 5 different opdata's defined, these 5 will be spread about the 20s cycle. The interval will increase.
  // requesting a new opdata will always start at a doubleframe start
  if ((frame > (NoFramesPerOpDataCycle / opdataCnt)) && doubleframe ) {    // interval for requesting new opdata depending on de number of opdata requests
    frame = 1;                              // start requesting new OpData
  }

  if (frame++ <= 2) {                       // use opdata request only for 2 subsequent frames
    if (doubleframe) {                      // start when MISO_frame[DB14] bit2 is set
      if (erropdataCnt == 0) {
        MISO_frame[DB6] = pgm_read_word(opdata + opdataNo);
        MISO_frame[DB9] = pgm_read_word(opdata + opdataNo) >> 8;
        opdataNo = (opdataNo + 1) % opdataCnt;
      }

    }
  }
  else  // reset OpData request
  {
    MISO_frame[DB6] = 0x80;
    MISO_frame[DB9] = 0xff;    
  }
  
  if (doubleframe) {                        // and the other MISO data changes are updated when MISO_frame[DB14] bit2 is set
    MISO_frame[DB0] = 0x00;
    MISO_frame[DB1] = 0x00;
    MISO_frame[DB2] = 0x00;

    if (erropdataCnt > 0) {                 // error operating data available
      MISO_frame[DB6] = 0x80;
      MISO_frame[DB9] = 0xff;
      erropdataCnt--;
    }

    // set Power, Mode, Tsetpoint, Fan, Vanes
    MISO_frame[DB0] = new_Power;
    new_Power = 0;

    MISO_frame[DB0] |= new_Mode;
    new_Mode = 0;

    MISO_frame[DB2] = new_Tsetpoint;
    new_Tsetpoint = 0;

    MISO_frame[DB1] = new_Fan;
    new_Fan = 0;

    MISO_frame[DB0] |= new_Vanes0;
    MISO_frame[DB1] |= new_Vanes1;
    new_Vanes0 = 0;
    new_Vanes1 = 0;

    if (request_erropData) {
      MISO_frame[DB6] = 0x80;
      MISO_frame[DB9] = 0x45;
      request_erropData = false;
    }
  }

  MISO_frame[DB3] = new_Troom;  // from MQTT or DS18x20

  uint16_t checksum = calc_checksum(MISO_frame);
  MISO_frame[CBH] = highByte(checksum);
  MISO_frame[CBL] = lowByte(checksum);
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

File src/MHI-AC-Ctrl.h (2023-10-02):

#pragma once

#include <cstdint>

// MQTT topic names
#define TOPIC_CONNECTED "connected"
#define TOPIC_VERSION "Version"
#define TOPIC_RSSI "RSSI"
#define TOPIC_WIFI_LOST "WIFI_LOST"
#define TOPIC_MQTT_LOST "MQTT_LOST"
#define TOPIC_WIFI_BSSID "WIFI_BSSID"
#define TOPIC_CMD_RECEIVED "cmd_received"
#define TOPIC_TDS1820 "Tds1820"
#define TOPIC_FSCK "fSCK"
#define TOPIC_FMOSI "fMOSI"
#define TOPIC_FMISO "fMISO"

#define TOPIC_POWER "Power"
#define TOPIC_MODE "Mode"
#define TOPIC_FAN "Fan"
#define TOPIC_VANES "Vanes"
#define TOPIC_VANESLR "VanesLR"
#define TOPIC_3DAUTO "3Dauto"
#define TOPIC_TROOM "Troom"
#define TOPIC_TSETPOINT "Tsetpoint"
#define TOPIC_ERRORCODE "Errorcode"

#define TOPIC_UNKNOWN "unknown"
#define TOPIC_KWH "KWH"
#define TOPIC_RETURNAIR "RETURN-AIR"
#define TOPIC_THI_R1 "THI-R1"
#define TOPIC_THI_R2 "THI-R2"
#define TOPIC_THI_R3 "THI-R3"
#define TOPIC_IU_FANSPEED "IU-FANSPEED"
#define TOPIC_TOTAL_IU_RUN "TOTAL-IU-RUN"
#define TOPIC_OUTDOOR "OUTDOOR"
#define TOPIC_COMP "COMP"
#define TOPIC_TD "TD"
#define TOPIC_THO_R1 "THO-R1"
#define TOPIC_CT "CT"
#define TOPIC_TDSH "TDSH"
#define TOPIC_PROTECTION_NO "PROTECTION-NO"
#define TOPIC_OU_FANSPEED "OU-FANSPEED"
#define TOPIC_DEFROST "DEFROST"
#define TOPIC_TOTAL_COMP_RUN "TOTAL-COMP-RUN"
#define TOPIC_OU_EEV1 "OU-EEV1"

#define TOPIC_REQUEST_ERROPDATA "ErrOpData"
#define TOPIC_REQUEST_RESET "reset"

// MQTT payload text
#define PAYLOAD_CONNECTED_TRUE "1"
#define PAYLOAD_CONNECTED_FALSE "0"
#define PAYLOAD_CMD_OK "o.k."
#define PAYLOAD_CMD_UNKNOWN "unknown command"
#define PAYLOAD_CMD_INVALID_PARAMETER "invalid parameter"
#define PAYLOAD_POWER_ON "On"
#define PAYLOAD_POWER_OFF "Off"
#define PAYLOAD_MODE_OFF PAYLOAD_POWER_OFF
#define PAYLOAD_MODE_AUTO "Auto"
#define PAYLOAD_MODE_STOP "Stop"
#define PAYLOAD_MODE_DRY "Dry"
#define PAYLOAD_MODE_COOL "Cool"
#define PAYLOAD_MODE_FAN "Fan"
#define PAYLOAD_MODE_HEAT "Heat"
#define PAYLOAD_FAN_AUTO "Auto"
#define PAYLOAD_VANES_UNKNOWN "?"
#define PAYLOAD_VANES_SWING "Swing"
#define PAYLOAD_OP_DEFROST_ON "On"
#define PAYLOAD_OP_DEFROST_OFF "Off"
#define PAYLOAD_REQUEST_RESET "reset"
#define PAYLOAD_VANESLR_SWING "Swing"
#define PAYLOAD_3DAUTO_ON "On"
#define PAYLOAD_3DAUTO_OFF "Off"

enum POWER_STATUS {
    unknown,
    off,
    on
};

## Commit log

2019-12-15 update for v1.1
    Error code (DB4) added
    OTA is now also working when waiting for a MQTT connection
    [MHI-AC-Ctrl.ino]
2019-12-17 Vanes information enhanced
    Due to update from niclet in the thread https://github.com/rjdekker/MHI2MQTT/issues/8#issuecomment-557870093
2019-12-21 Assembled PCB figure added
2020-01-18 BOM added
2020-01-27 Fix logic error on MQTT connection failure backoff
    [MHI-AC-Ctrl.ino]
2020-03-01 link to SPI.md added
2020-04-26 Timing diagram frame & byte
2020-04-26 cable connection diagram added
2020-06-05 updated to fix typo in row 662
    updated to fix typo according to [issue](https://github.com/absalom-muc/MHI-AC-Ctrl/issues/16#issuecomment-639591710)
    [MHI-AC-Ctrl.ino]
2020-06-06 bug in row 192 fixed (wrong interrupt handler was selected)
    and some minor code rebuild
    [support.cpp]
2020-06-15 fix of issue #18 (AC Power off randomly)
    fix of issue #18 https://github.com/absalom-muc/MHI-AC-Ctrl/issues/18#issuecomment-643739863. The illegal (dummy) value 0xff from opdata was used for MISO_DB6. This led to the shutdown of the air conditioning system. Now replaced by 0x00
    [MHI-AC-Ctrl-core.h]
2020-06-21 Create frequency_measurement.ino
    Used for measurement of the SCK period and byte/frame period
2020-06-24 SPI logger
    logs the timing of the SPI signal edges
2020-06-24 v2.01
    - No functional changes
    - Further reduction of memory usage
    - Compiler warnings removed
    - set-mechanism reworked
    - SCK by SCK_PIN replaced according to [pull request 19](https://github.com/absalom-muc/MHI-AC-Ctrl/pull/19)
    - Shift void MeasureFrequency() from support.cpp to MHI-AC-Ctrl-core.cpp
    [MHI-AC-Ctrl-core.cpp, MHI-AC-Ctrl-core.h, MHI-AC-Ctrl.h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]
2020-06-28 update to v2.02
    Functionality for POWERON_WHEN_CHANGING_MODE enhanced, the according #define shifted to support.h
2020-06-28 typo in HOSTNAME corrected
    [support.h]
2020-07-01 switched to vcd format
    use e.g. PulseView to see the waveform
2020-07-09 updates for 2.03
    - Functionality for POWERON_WHEN_CHANGING_MODE improved in MHI-AC-Ctrl.ino
    - WiFi mode restricted to STA (no more AP) in support.cpp
2020-07-09 info for fan auto added
2020-07-29 important warning related to the 2-pin connector added
2020-08-09 Numbering of AC connector corrected
    https://github.com/absalom-muc/MHI-AC-Ctrl/issues/39
2020-08-09 external temperature sensor disabled per default
    according to issue 32 in https://github.com/absalom-muc/MHI-AC-Ctrl/issues/32
    [support.h]
2020-08-28 link to Gerber files added
2021-02-06 PCB layout update
    [MHI-AC-Ctrl_v2.2.brd, MHI-AC-Ctrl_v2.2.sch]
2021-04-01 link to swapped pins on PCB removed
    No longer needed due to new PCB layout
2021-04-28 Added unsupported model (#57)
    SRKxxZSPR-S doesn’t have the required connector
2021-04-28 Added warning because of limited space on AC board
2021-12-17 v2.5R21
    - calculation of RETURN-AIR in MHI-AC-Ctrl.ino corrected
    - Removed the option #define ROOM_TEMP_IU for adaption by the user in support.h. Now it is generated automatically when ROOM_TEMP_DS18X20 and ROOM_TEMP_MQTT are not defined
    - Reworked WiFi network re-scan function
    [MHI-AC-Ctrl-core.cpp, MHI-AC-Ctrl.ino, support.cpp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]
2021-12-18 link to MHI-AC-Trace added
    SPI.md removed here and shifted to MHI-AC-Trace repository
2021-12-18 Delete SPI.md
    shifted to [MHI-AC-Trace](https://github.com/absalom-muc/MHI-AC-Trace)
2022-04-14 added voltage measurement for SCK/MOSI
2022-08-04 v2.6R1 experimental version
    new implementation for fan control incl. 'Auto'.
2022-08-28 update 2.6R2
    mainly Fan with "Auto" implemented
2022-10-31 kicad: Redo v2.2 in KiCad (#106)
    As KiCad has become quite popular (and eagle less so) offer the same
    design in KiCad going forward.
    [MHI-AC-CTRL-B_Cu.gbl, MHI-AC-CTRL-B_Mask.gbs, MHI-AC-CTRL-B_Paste.gbp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]
2022-10-31 KiCad PCB added
2022-11-05 note for the KiCad PCB added
2022-12-21 update to v2.6R3
    Added switch for Troom filtering
2023-02-11 Fix for fan not showing 4 and Auto after powerdown AC (#132)
    * Fix for fan not showing 4 and Auto after powerdown AC
    * Added version.md and support.h
    [MHI-AC-Ctrl.h, MHI-AC-Ctrl.ino, support.h]
2023-03-26 Change MISO sending and avoid jitter
    - fix some compiler warnings by [glsf91](https://github.com/glsf91)
    - change sending MISO with faster refresh of data every 20s by [glsf91](https://github.com/glsf91)
    - avoid jitter with internal temperature sensor, now updating atmost every 5s by [glsf91](https://github.com/glsf91)
    - fix print wifi encryption type by [glsf91](https://github.com/glsf91)
    - skip not usable values for DB18B20 by [glsf91](https://github.com/glsf91)
    [MHI-AC-Ctrl-core.cpp, MHI-AC-Ctrl-core.h, MHI-AC-Ctrl.ino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]
2023-04-23 Changed WiFi connection setup and continue when MQTT failed
    [MHI-AC-Ctrl.ino, support.cpp, support.h]
2023-08-28 KiCad: Fix J1 connector (#155)
    This fixes the J1 connector footprint and 3D model by using
    easyeda2kicad [0] to pull the data from LCSC!
    Closes #111
    [0]: https://github.com/uPesy/easyeda2kicad.py
    [MHI-AC-CTRL.kicad_pcb, MHI-AC-CTRL.kicad_sch]
2023-10-23 Add SRC35ZSA-W to supported model list
    I've built and installed several of these units from the Gerber files on
    the website via JLC-PCB and have full functionality with this model.
2024-01-08 Correct J1 connector pinout (#168)
    Fixes #167
    Regenerated PDF and gerber/drill
    [MHI-AC-CTRL-B_Cu.gbl, MHI-AC-CTRL-B_Mask.gbs, MHI-AC-CTRL-B_Paste.gbp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]
2024-06-15 Added link to esp32 variant in Hardware.md
2024-08-29 Update Hardware.md Changed link to Kicad design
2024-08-30 Update Hardware.md Kicad
2025-03-26 Add note about loss of timer functionality in troubleshooting
2025-03-26 Rephrase note about loss of timer functionality

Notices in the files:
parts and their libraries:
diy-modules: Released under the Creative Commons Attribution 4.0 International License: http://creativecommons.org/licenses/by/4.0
